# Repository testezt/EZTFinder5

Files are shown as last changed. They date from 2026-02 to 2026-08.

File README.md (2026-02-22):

# PiFinder™
A plate solving telescope finder based around a Raspberry PI, imx296 camera, and custom UI 'hat'

For an overview of what the PiFinder™ is and how it came to be visit the official project website at [PiFinder.io](https://www.pifinder.io/build-yours) 

The PiFinder™ uses the [Ceder Detect](https://github.com/smroid/cedar-detect) and
[Cedar Solve](https://github.com/smroid/cedar-solve) libraries with express permission.
Thank you to [smroid] for all your support of the PiFinder project!

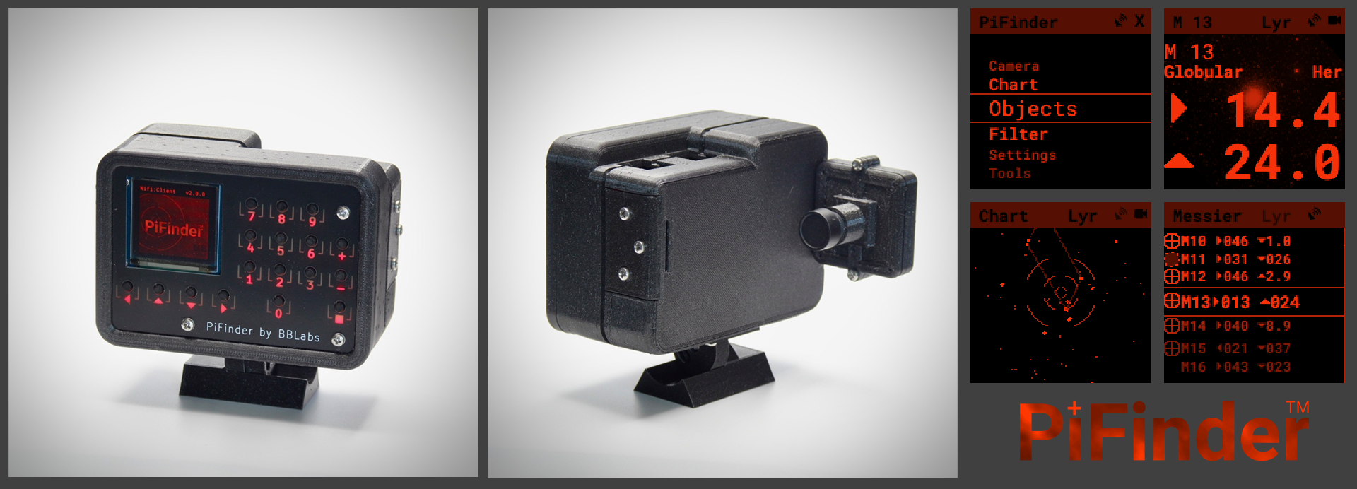
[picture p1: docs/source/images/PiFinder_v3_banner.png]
Banner

The PiFinder™ is my attempt to improve my time at my telescope.  I don't get nearly enough of it and I want to enjoy it as much as possible.  So after years of observing with paper charts and, later, a Nexus DSC here is what I felt I was missing:
* **Reliable telescope positioning:**  The Nexus DSC is great, but my scope just isn't built for solid encoder integration.  The slop in the way I have to couple the encoders means poor pointing accuracy.
* **Easy setup:**  The Nexus DSC needs multi-star alignment to understand how the encoders map to the sky.  The process is not terrible, but I'd like to avoid it.
* **Good push-to functionality**:  This is one place the Nexus DSC shines... if it's well aligned.  The catalog system is okay, and once you select and object the screen is clear and helpful to get the telescope pointed correctly.
* **Observation logging**:  I like to keep track of what I see each night.  I don't often sketch, just record what I saw when, with what eyepiece and some basic info about the experience.  If I could do this right at the eyepiece, that'd save time.

My hope is that other people will find this combination of functionality useful, will build their own PiFinder™ and help the whole project improve by making suggestions and potentially contributing to the software.  It's a pretty easy build with off the shelf parts and beginner friendly soldering.  

## Features
* Zero setup: Just turn it on and point it at the sky!  
* Accurate pointing: Onboard GPS determines location and time while the camera determines where the scope is pointing.  Inertial Measurement Unit tracks scope motion and updates sky position between camera solves
* Self-contained:  Includes catalog search/filtering, sky/object charting, push-to guidance and logging all via the screen and keypad on the unit.
* Dark site friendly:  Red OLED screen and soft backlit keys have wide brightness adjustment, right down to 'off'. No need for bright cell phones or tablets
* Easy access: Can be mounted by the eyepiece just like a finder.
- Wifi Access Point / SkySafari Integration:  The PiFinder™ can act as a WIFI access point to connect your tablet or phone to sync SkySafari or other planetarium software with your scope.

## Build Your Own
The PiFinder™ is fully open-source hardware and software.  You can order PCB's and 3d print the case with the files in this repo and order all the parts from the [parts List](https://pifinder.readthedocs.io/en/release/BOM.html).

If you would like pre-assembled units, kits or other items to jump start your PiFinder™ journey, visit [PiFinder.io](https://www.pifinder.io/build-pifinder) to see what's available and place an order.

## Docs

* [Quick Start](https://pifinder.readthedocs.io/en/release/quick_start.html)
* [User Manual](https://pifinder.readthedocs.io/en/release/user_guide.html)
* [Parts List](https://pifinder.readthedocs.io/en/release/BOM.html)
* [Build Guide](https://pifinder.readthedocs.io/en/release/build_guide.html)
* [Software Setup](https://pifinder.readthedocs.io/en/release/software.html)
* [Developer Guide](https://pifinder.readthedocs.io/en/release/dev_guide.html)

## Releases and Updates

If you are using a PiFinder, I recommend you watch releases in this repo.  Click the 'Watch' button up at the top right of the page, choose 'Custom' and then 'Releases' to make sure you don't miss any new features!

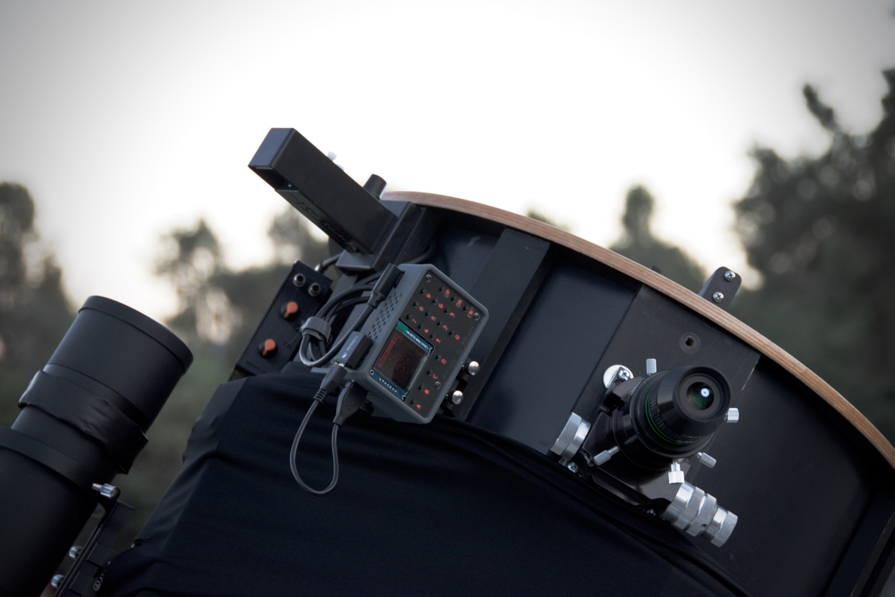
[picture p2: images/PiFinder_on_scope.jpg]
PiFinder™ on my Dob


If you'd like to learn more about how it works, and potentially build your own, everything you need should be here.  I recommend starting with the [User Manual](https://pifinder.readthedocs.io/en/release/user_guide.html) and then checking out the build process using the links below.

## Discord
Join the  [PiFinder™ Discord server](https://discord.gg/Nk5fHcAtWD) for support with your build, usage questions, and suggestions for improvement.

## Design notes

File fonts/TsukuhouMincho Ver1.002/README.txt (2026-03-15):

この度は築豊明朝をダウンロードいただき誠にありがとうございます。

■書体概要
築豊明朝（つくほうみんちょう）は築地五号系の伝統的な本文向け明朝体を意識して作られたかな書体です。
伝統な部分を残しつつ、一部のかなの脈絡を変更することで筆の動きや柔らかさをより強調させました。独特な字形もあり、本文だけではなく、見出しやタイトルでも使っても目を惹きつけられるかもしれません。
漢字や欧文は「ZENオールド明朝 Regular」からお借りしています。

■ご利用にあたり
SILオープンフォントライセンスでの配布なので、商用・個人利用可能です。

文字魚│Typographish

2022/12/18　Ver1.000　公開
2022/12/19　Ver1.001　修正
2022/12/26　Ver1.002　フォント名が日本語になりました

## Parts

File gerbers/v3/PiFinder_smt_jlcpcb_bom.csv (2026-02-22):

Comment | Designator | Footprint | LCSC
1uF | C1 | Capacitor_SMD:C_0805_2012Metric | C28323
100nF | C2 | Capacitor_SMD:C_0805_2012Metric | C49678
22pF | C3,C4 | Capacitor_SMD:C_0805_2012Metric | C24658
LED | D1,D2,D3,D4,D5,D6,D7,D8,D9,D10,D11,D12,D13,D14,D15,D16,D17 | LED_SMD:LED_1210_3225Metric | C125112
BNO055 | IMU1 | Package_LGA:LGA-28_5.2x3.8mm_P0.5mm | C93216
Q_NPN_EBC | Q1 | RSU:PF_SOT-23-NPN | C2150
22 | R1 | Resistor_SMD:R_0805_2012Metric | C17561
330 | R2 | Resistor_SMD:R_0805_2012Metric | C17630
10k | R3,R4,R5,R6 | Resistor_SMD:R_0805_2012Metric | C17414
SW_Push_Dual | SW0,SW1,SW_A1,SW_B1,SW_C1,SW_D1,SW_DN1,SW_GO1,SW_UP1,SW2,SW3,SW4,SW5,SW6,SW7,SW8,SW9 | RSU:SW_Push_6x6mm_SMT_withhole_tight | C4364377
Crystal | Y1 | Crystal:Crystal_SMD_3215-2Pin_3.2x1.5mm | C32346

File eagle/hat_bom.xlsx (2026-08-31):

Comment | Designator | Footprint
22pF | C1 | C0603C100C5GACTU | C1648
1uF | C2 | C0603C100C5GACTU | C15849
22pF | C25 | C0603C100C5GACTU | C1648
0.1uF | C3 | C0603C100C5GACTU | C14663
APBD3224LSYKCGKC | D1 | APBD3224LSYKCGKC | C125112
APBD3224LSYKCGKC | D2 | APBD3224LSYKCGKC | C125112
APBD3224LSYKCGKC | D3 | APBD3224LSYKCGKC | C125112
APBD3224LSYKCGKC | D4 | APBD3224LSYKCGKC | C125112
APBD3224LSYKCGKC | D5 | APBD3224LSYKCGKC | C125112
APBD3224LSYKCGKC | D6 | APBD3224LSYKCGKC | C125112
APBD3224LSYKCGKC | D7 | APBD3224LSYKCGKC | C125112
APBD3224LSYKCGKC | D8 | APBD3224LSYKCGKC | C125112
APBD3224LSYKCGKC | D9 | APBD3224LSYKCGKC | C125112
APBD3224LSYKCGKC | D10 | APBD3224LSYKCGKC | C125112
APBD3224LSYKCGKC | D11 | APBD3224LSYKCGKC | C125112
APBD3224LSYKCGKC | D12 | APBD3224LSYKCGKC | C125112
APBD3224LSYKCGKC | D13 | APBD3224LSYKCGKC | C125112
APBD3224LSYKCGKC | D14 | APBD3224LSYKCGKC | C125112
APBD3224LSYKCGKC | D15 | APBD3224LSYKCGKC | C125112
APBD3224LSYKCGKC | D16 | APBD3224LSYKCGKC | C125112
APBD3224LSYKCGKC | D17 | APBD3224LSYKCGKC | C125112
SS8050-G | Q1 | SS8050-G | C2150
10K | R1 | RC0603JR-070RL | C25804
10K | R2 | RC0603JR-070RL | C25804
10K | R3 | RC0603JR-070RL | C25804
330 | R4 | RC0603JR-070RL | C23138
22 | R5 | RC0603JR-070RL | C103419
10K | R19 | RC0603JR-070RL | C25804
C2888519 | S1 | TS04-44-75-BK-100-SMT44 | C2888519
TS04-44-75-BK-100-SMT44 | S2 | TS04-44-75-BK-100-SMT44 | C2888519
TS04-44-75-BK-100-SMT44 | S3 | TS04-44-75-BK-100-SMT44 | C2888519
TS04-44-75-BK-100-SMT44 | S4 | TS04-44-75-BK-100-SMT44 | C2888519
TS04-44-75-BK-100-SMT44 | S5 | TS04-44-75-BK-100-SMT44 | C2888519
TS04-44-75-BK-100-SMT44 | S6 | TS04-44-75-BK-100-SMT44 | C2888519
TS04-44-75-BK-100-SMT44 | S7 | TS04-44-75-BK-100-SMT44 | C2888519
TS04-44-75-BK-100-SMT44 | S8 | TS04-44-75-BK-100-SMT44 | C2888519
TS04-44-75-BK-100-SMT44 | S9 | TS04-44-75-BK-100-SMT44 | C2888519
TS04-44-75-BK-100-SMT44 | S10 | TS04-44-75-BK-100-SMT44 | C2888519
TS04-44-75-BK-100-SMT44 | S11 | TS04-44-75-BK-100-SMT44 | C2888519
TS04-44-75-BK-100-SMT44 | S12 | TS04-44-75-BK-100-SMT44 | C2888519
TS04-44-75-BK-100-SMT44 | S13 | TS04-44-75-BK-100-SMT44 | C2888519
TS04-44-75-BK-100-SMT44 | S14 | TS04-44-75-BK-100-SMT44 | C2888519
TS04-44-75-BK-100-SMT44 | S15 | TS04-44-75-BK-100-SMT44 | C2888519
TS04-44-75-BK-100-SMT44 | S16 | TS04-44-75-BK-100-SMT44 | C2888519
TS04-44-75-BK-100-SMT44 | S17 | TS04-44-75-BK-100-SMT44 | C2888519
SS12D07VG5/C22435634 | S18 | SS12D07VG4 | C22435634
BNO055 | U1 | BNO055 | C93216
32.768kHz 70kΩ | XTAL1 | Q13FC1350000400 | C32346

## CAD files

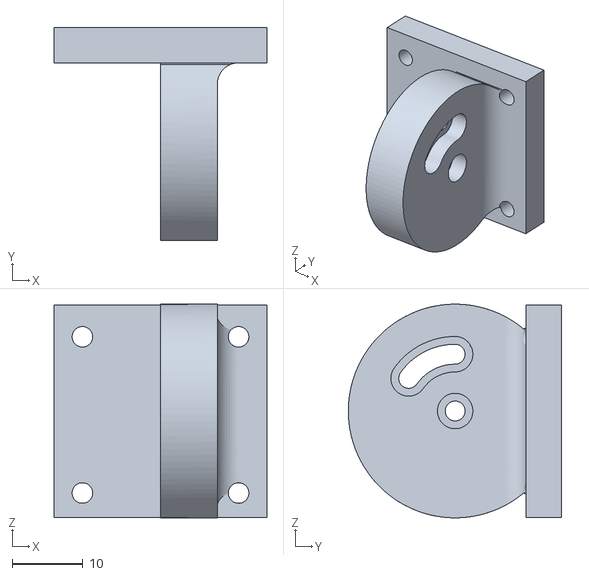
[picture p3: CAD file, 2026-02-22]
case/accessories/tall_dovetail_top.stl
30.0 x 30.0 x 30.1

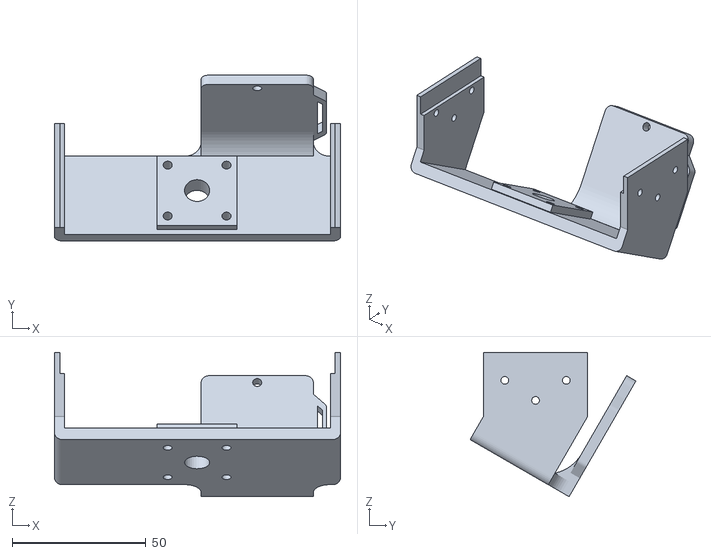
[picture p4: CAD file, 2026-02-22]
case/adapters/flat30_adapter_tripod.stl
107.0 x 62.1 x 54.0

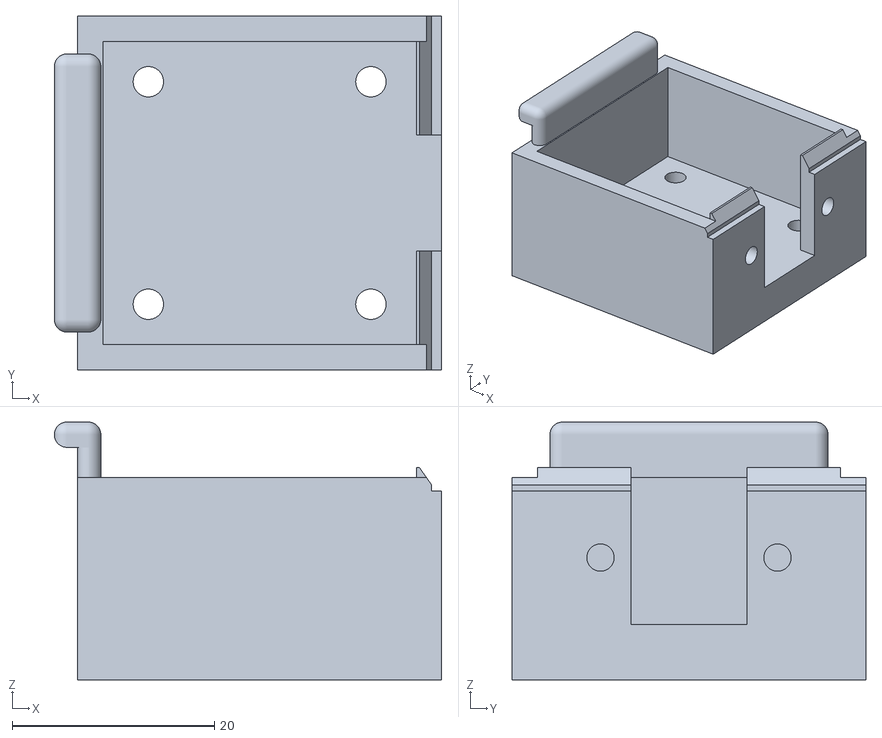
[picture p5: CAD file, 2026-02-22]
case/adapters/quikfinder/PiToQuikfinder v2 - Part 1.stl
38.3 x 35.0 x 25.5

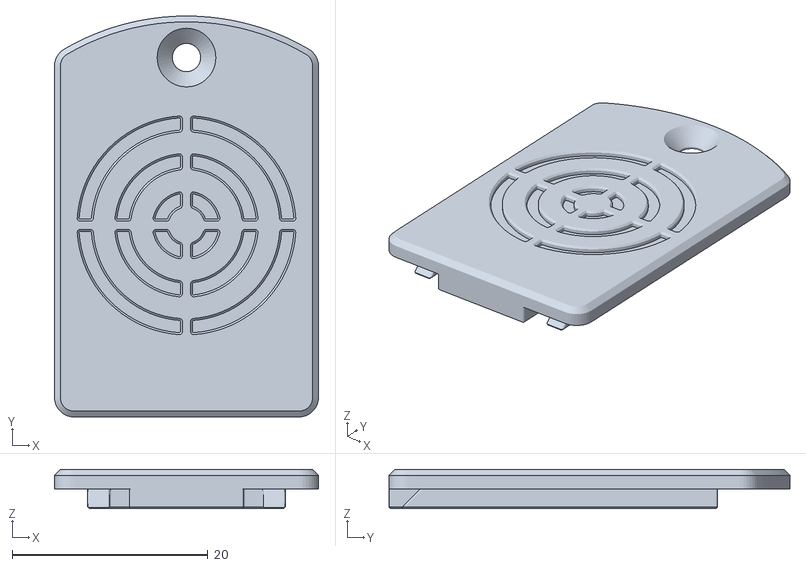
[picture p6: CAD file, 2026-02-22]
case/GPS_enclosure_bottom.stl
27.0 x 41.0 x 4.00

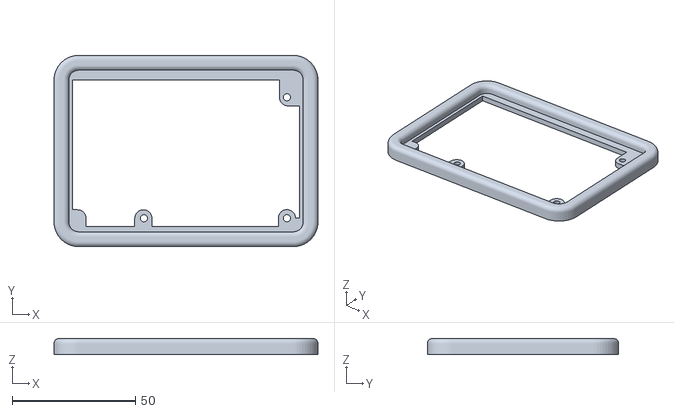
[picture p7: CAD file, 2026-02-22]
case/v3/common/bezel.stl
107.0 x 77.5 x 6.50

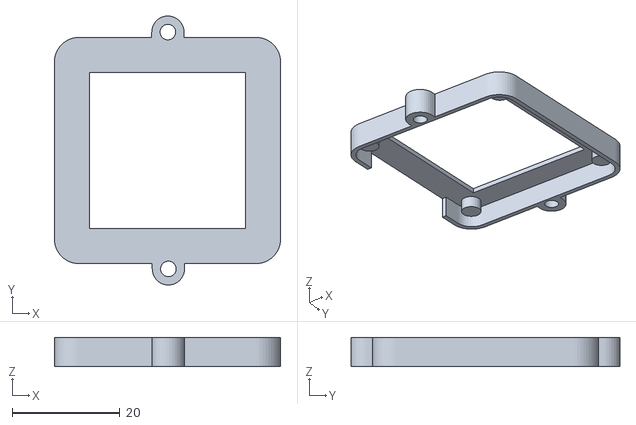
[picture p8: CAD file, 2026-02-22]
case/v3/flat/flat30_camtray.stl
42.0 x 50.0 x 5.40

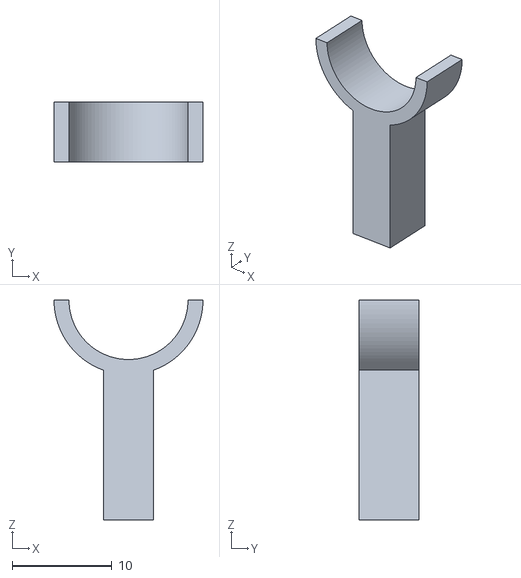
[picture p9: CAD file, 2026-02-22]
case/v3/focus_spacer.stl
14.9 x 6.00 x 22.0

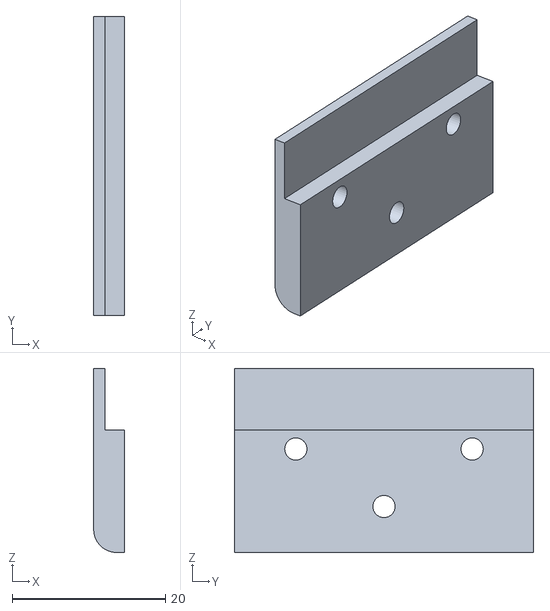
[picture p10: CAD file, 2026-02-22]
case/v3/left_right/hardpoint_cover.stl
4.00 x 39.0 x 24.0

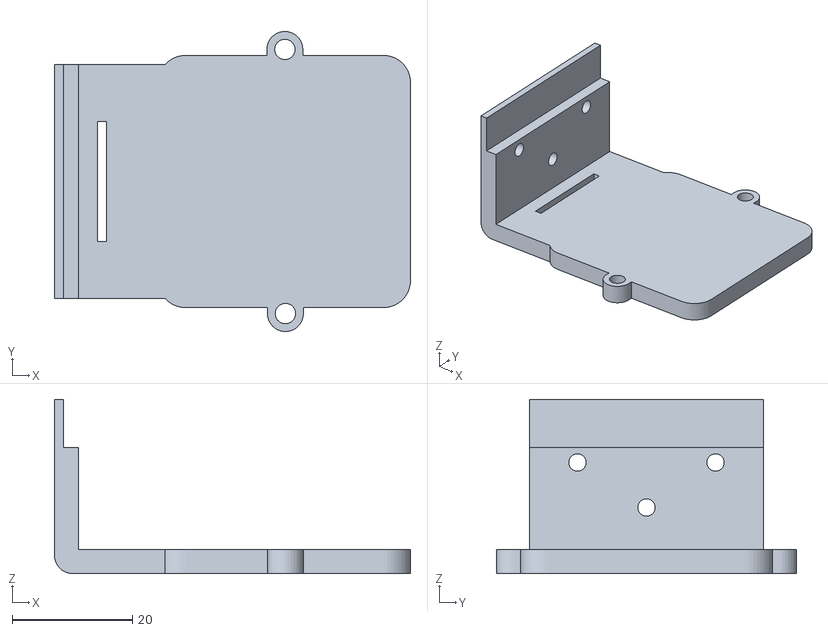
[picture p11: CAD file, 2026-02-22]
case/v3/straight/st_mount.stl
59.3 x 50.0 x 29.0

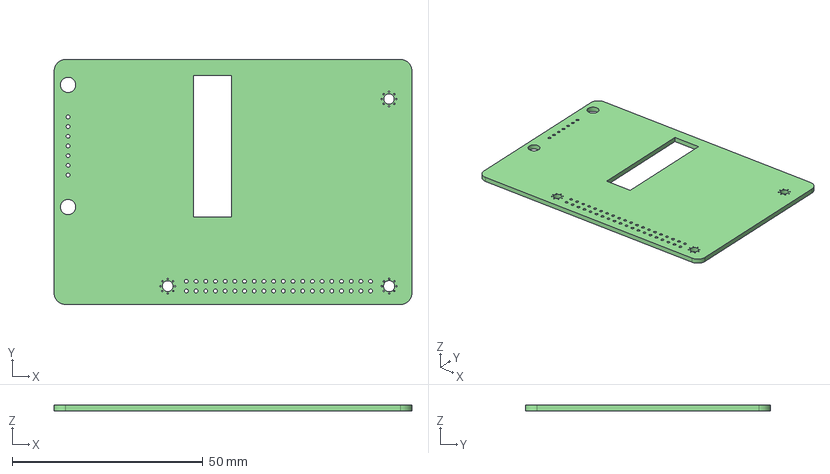
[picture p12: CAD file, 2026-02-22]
kicad/PiFinder_v3/PiFinder_smt.step
93.8 x 64.2 x 1.60 mm

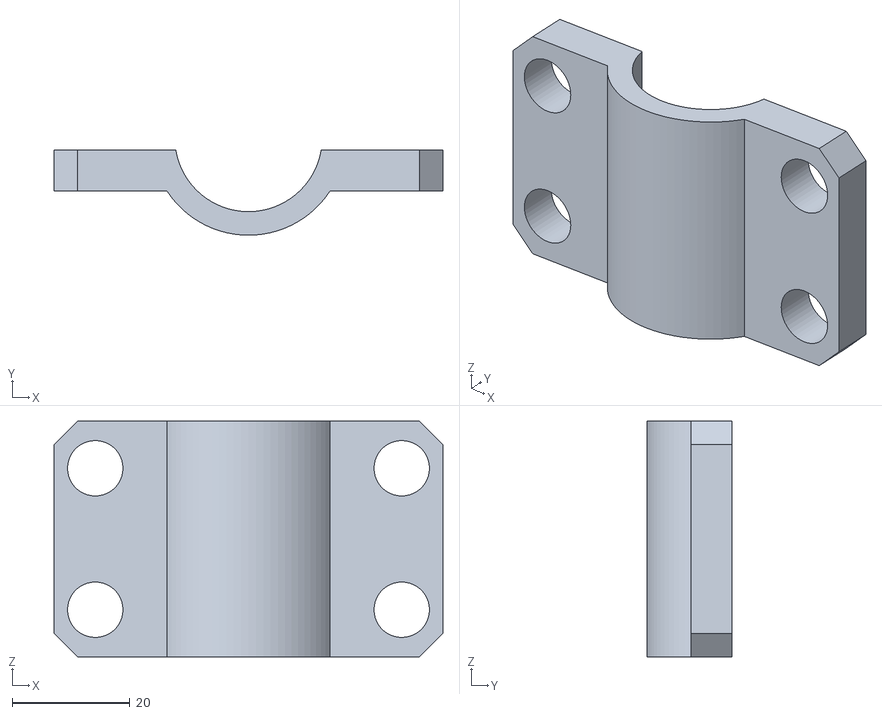
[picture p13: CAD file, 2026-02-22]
case/accessories/tube_shoe_mount_25mm_bottom.stl
66.0 x 14.5 x 40.0

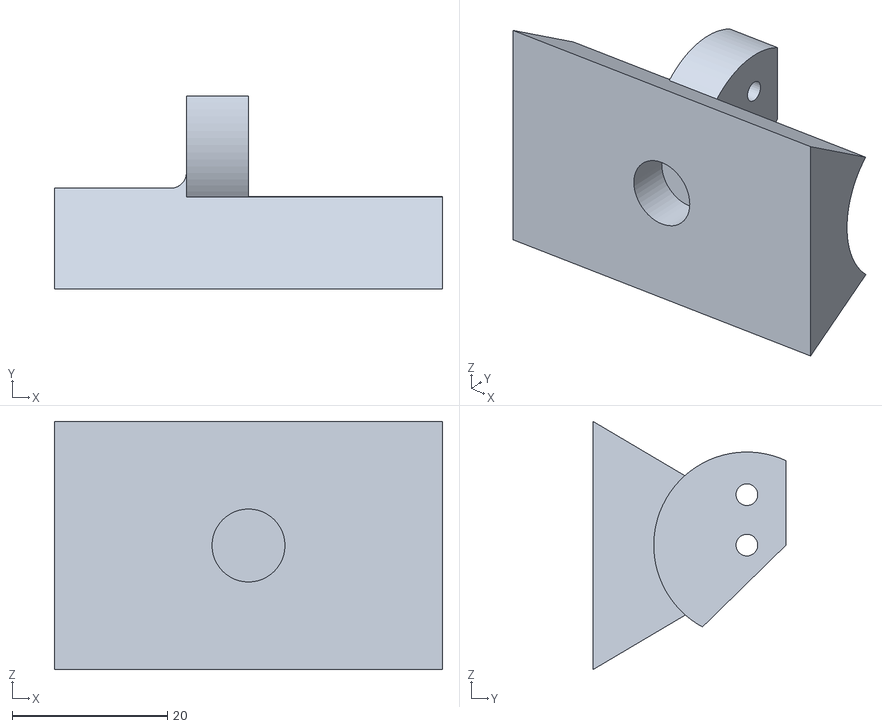
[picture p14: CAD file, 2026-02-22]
case/adapters/dovetail_bottom_tripod.stl
50.0 x 24.9 x 32.0

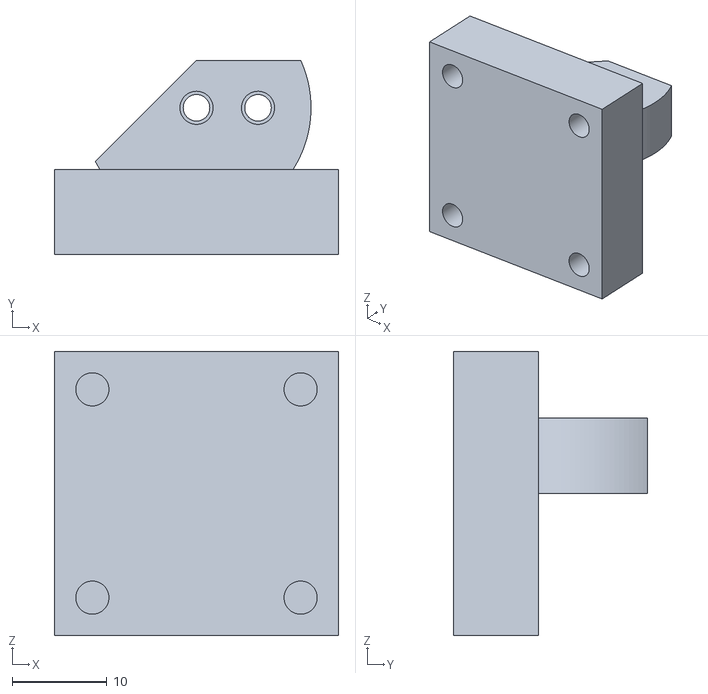
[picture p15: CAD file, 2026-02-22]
case/adapters/quikfinder/Pi2Q2Dovetail.stl
30.0 x 20.5 x 30.0

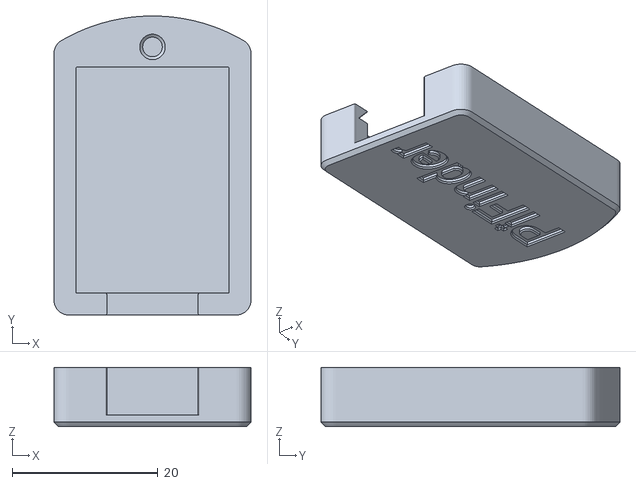
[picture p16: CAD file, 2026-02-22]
case/GPS_enclosure_top.stl
27.0 x 41.0 x 8.10

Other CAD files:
case/v3/common/shroud_front_usb_cutout.stl
case/v3/flat/flat_plug.stl
case/v3/left_right/camera_mount.stl
case/v3/straight/st_tray.stl
case/accessories/90_degree_dovetail.stl
case/accessories/tall_dovetal_bottom.stl
case/accessories/tube_shoe_mount_22mm_bottom.stl
case/accessories/tube_shoe_mount_22mm_top.stl
case/accessories/tube_shoe_mount_25mm_top.stl
case/accessories/tube_shoe_mount_30mm_bottom.stl
case/accessories/tube_shoe_mount_30mm_top.stl
case/accessories/tube_shoe_mount_32mm_bottom.stl
case/accessories/tube_shoe_mount_32mm_top.stl
case/accessories/tube_shoe_mount_38mm_bottom.stl
case/accessories/tube_shoe_mount_38mm_top.stl
case/accessories/vixen_right_angle.stl
case/adapters/dovetail_losmandy.stl
case/adapters/flat30_adapter_sidemount.stl
case/adapters/quikfinder/PiToQuikfinder v2 - Part 2.stl
case/v1/bezel.stl
case/v1/bottom.stl
case/v1/camera_cover.stl
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

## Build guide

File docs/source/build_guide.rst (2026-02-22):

===========
Build Guide
===========

Introduction and Overview
=================================

Welcome to the PiFinder build guide!  This guide is split into three main parts, one for building the :ref:`UI Board<build_guide:pifinder ui hat>` with Screen and Buttons, a section related to :ref:`3d printing<build_guide:printed parts>` and preparing the case parts, and one for :ref:`final assembly<build_guide:assembly>`.   Along with these sections, please consult the :doc:`Bill of Materials<BOM>` for a full list of parts required and reach out with any questions via `email <mailto:info@pifinder.io>`_ or `discord <https://discord.gg/Nk5fHcAtWD>`_

If you've received a kit with an assembled UI Board + 3d Parts, you can jump right to the :ref:`final assembly<build_guide:assembly>`.  Otherwise, fire up that 3d printer and get the :ref:`parts printing<build_guide:printing>` while you work to assemble the UI Hat.

PiFinder UI Hat
========================

A key part of the PiFinder is a custom 'Hat' which matches the general form factor of the Raspberry Pi and connects to it's GPIO header.  It contains the switches, screen and Inertial Measurement Unit along with keypad backlight components

It's all through-hole components, so should be approachable to even beginners... but the component build order is important as some items block access to others.

There are still some older photos here from the v1 non-backlit board, but the assembly is the same once the backlight components are in place.

You'll need the TWO pcb's to start with.  One contains the electronic components and the other has the shine-through legends and goes on top of the assembled board at the end.  You can find the gerber files for both in the main `PiFinder git repo <https://github.com/brickbots/PiFinder/tree/release/gerbers>`_

Backlight Components
------------------------

I like to start with the LEDs.  They sit close to the board and doing them first makes it 
easier to make sure they are all aligned.  

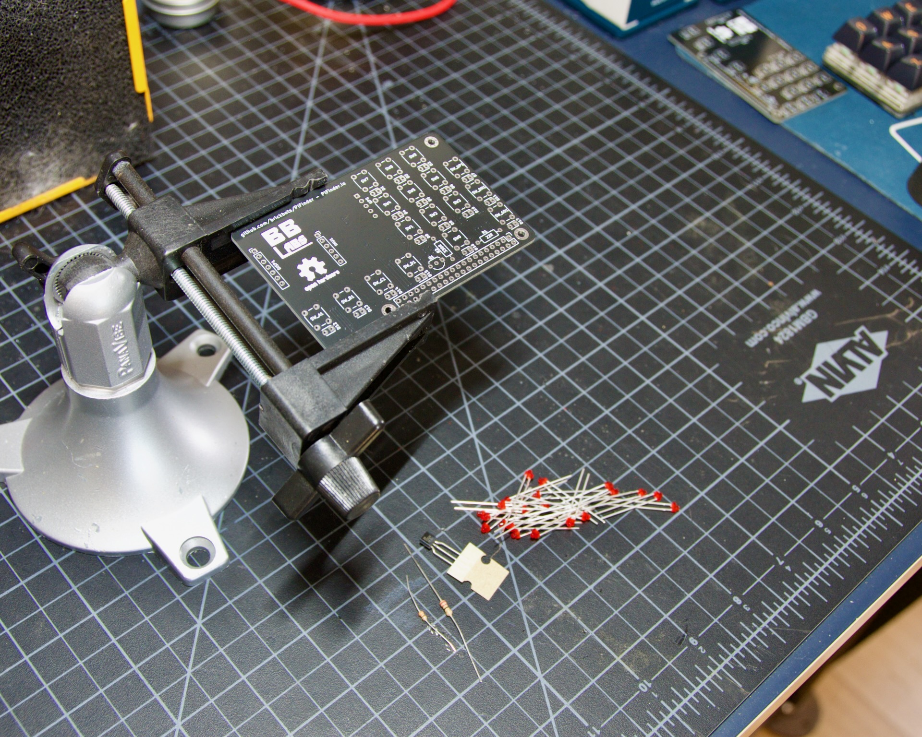
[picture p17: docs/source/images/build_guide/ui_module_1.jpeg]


Polarity matters here, so mind the direction.  The longer lead of the LED should go through the round hole in the footprint.  The photo below shows the orientation

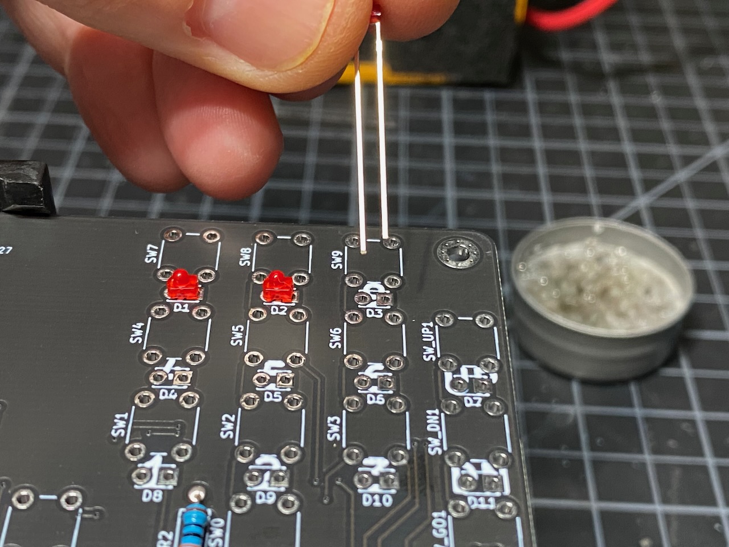
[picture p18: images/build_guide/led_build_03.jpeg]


Take you time and make sure each is positioned well.  They should be pretty uniform, but little inconsistencies don't matter too much.  I like to place them all in the board, and then tape them in place.

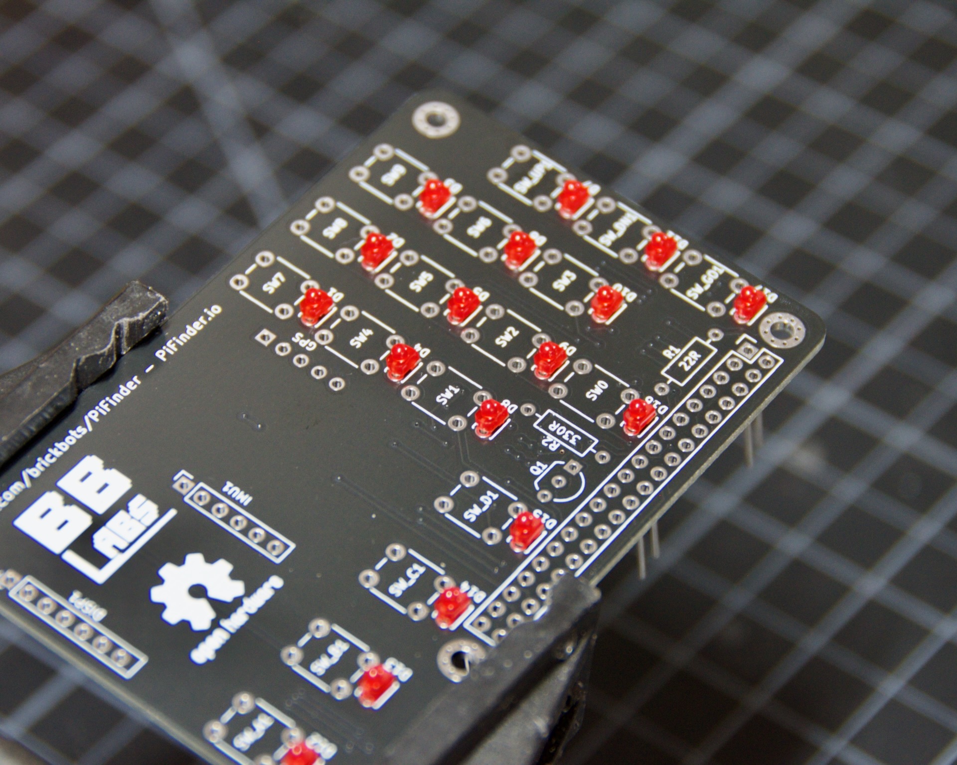
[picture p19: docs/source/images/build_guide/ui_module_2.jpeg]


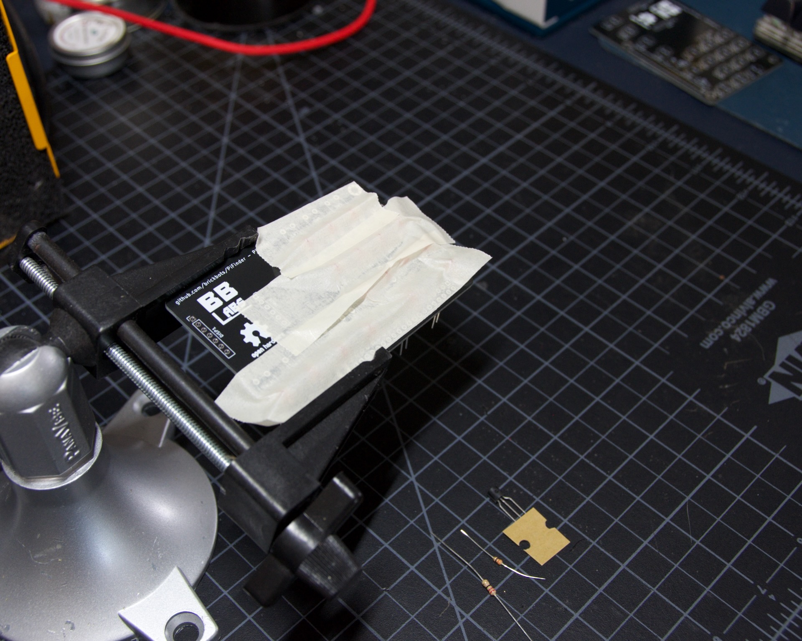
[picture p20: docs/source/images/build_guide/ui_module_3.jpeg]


Pull the legs straight and solder one of each LED.  Then remove the tape and check them again.  If any
are wildly out of place, you can heat up the solder on the one leg and adjust.  

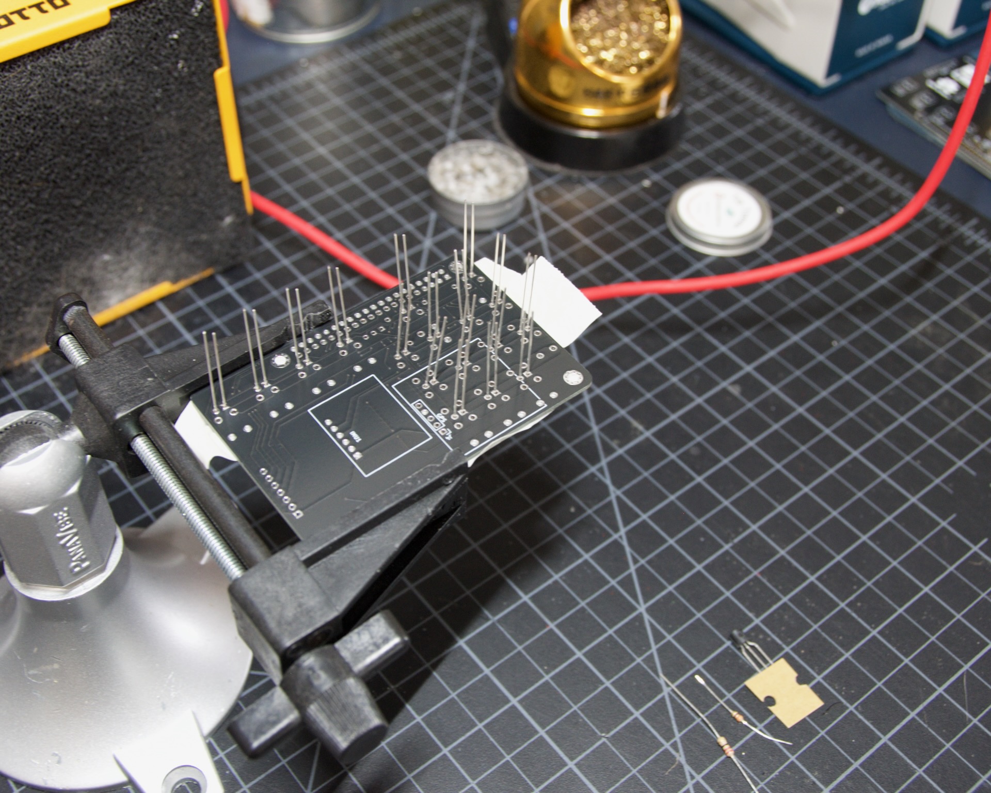
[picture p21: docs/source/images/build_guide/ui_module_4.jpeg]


When satisfied, solder the remaining legs and clip the leads

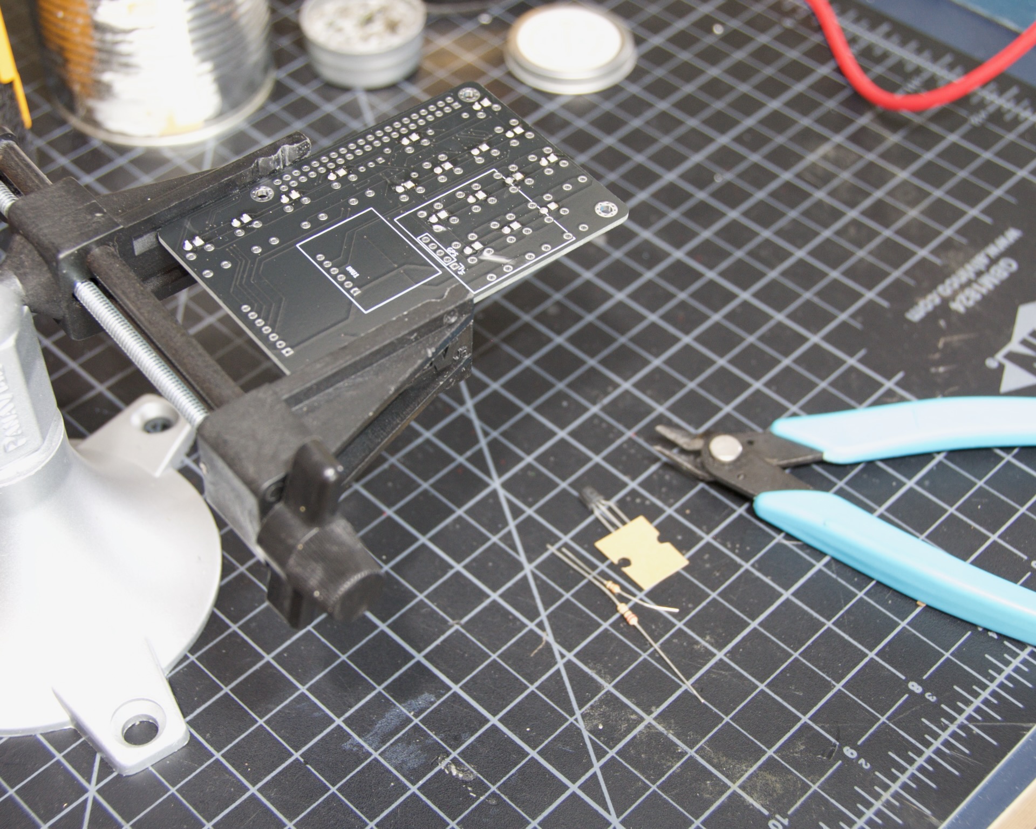
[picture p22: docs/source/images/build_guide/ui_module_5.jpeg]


The two resistors and transitor are next.  R2 is the vertical oriented 330ohm part and R1 is the 22ohm oriented horizontally.  Direction does not matter with these, but it's important for the transistor. Check the photo below for orientation and make sure this is bent flat against the PCB and the resistors are low.  Solder them from the back and clip the leads once you've verified they look good.

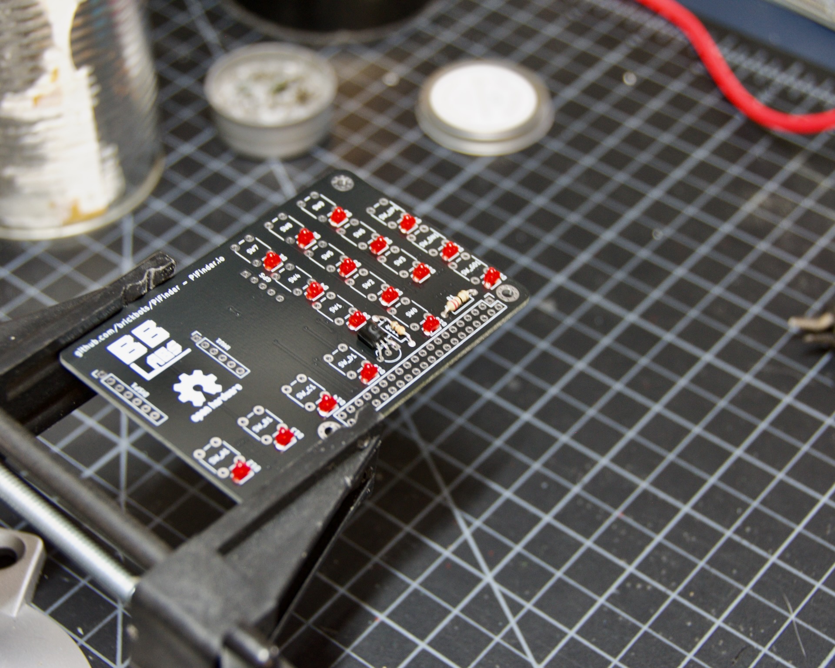
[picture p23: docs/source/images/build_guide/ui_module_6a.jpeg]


Switches
------------------------

Switches are easy and can go next.  Place each one on a footprint and press it down fully.  Once they are all inserted, before you start soldering visually inspect them for any that are tilted.  

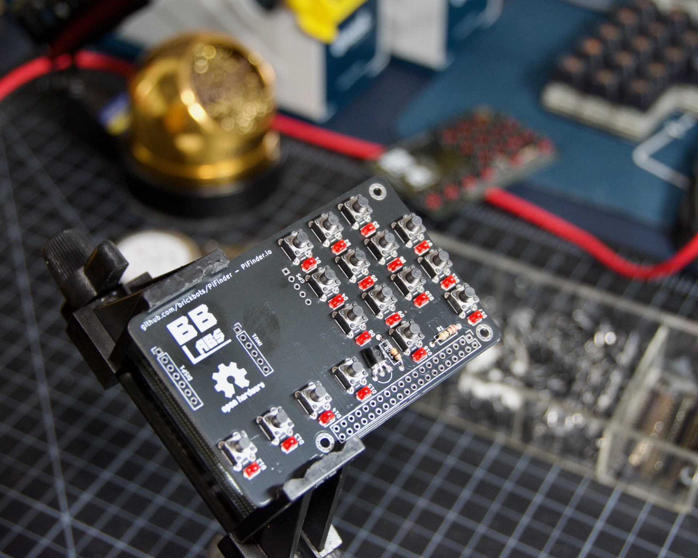
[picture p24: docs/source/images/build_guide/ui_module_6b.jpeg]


It's also a good idea to place the top legend plate over them to make sure they all clear the holes properly.  Then solder them up!  You don't need to clip the leads on all the switches, they have plenty of room.

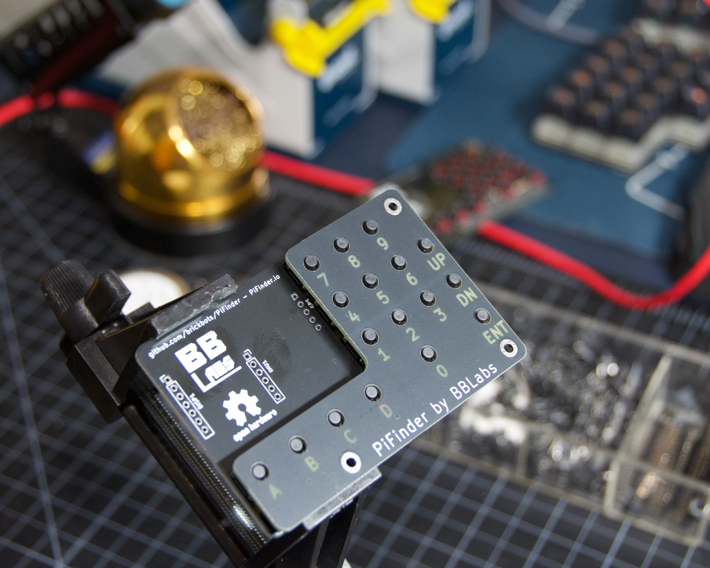
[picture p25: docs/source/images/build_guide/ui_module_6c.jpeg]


Headers
---------

I like to do all the headers next.  These will eventually receive the IMU, GPS and Screen.  The procedure is roughly the same for 
all three: Insert them, solder one pin, check that they are flat and straight and then solder the rest of the pins.  Clip them flush and apply some insulating tape.  

Start with the IMU header.  It goes on the underside of the board and is soldered from the top

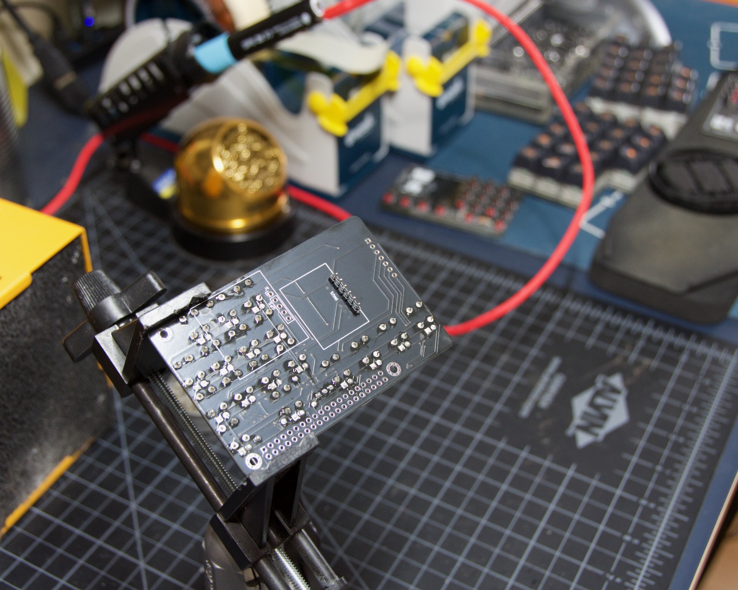
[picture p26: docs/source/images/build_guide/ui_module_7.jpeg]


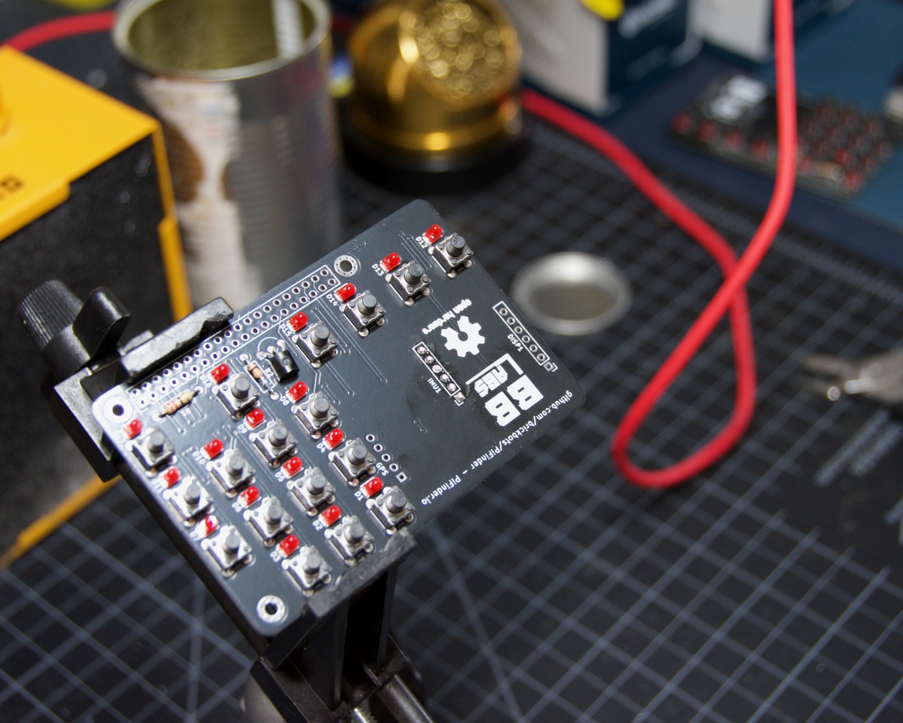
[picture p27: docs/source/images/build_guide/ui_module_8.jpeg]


Apply the insulating tape and move on to the screen header.  It goes in from the top side:

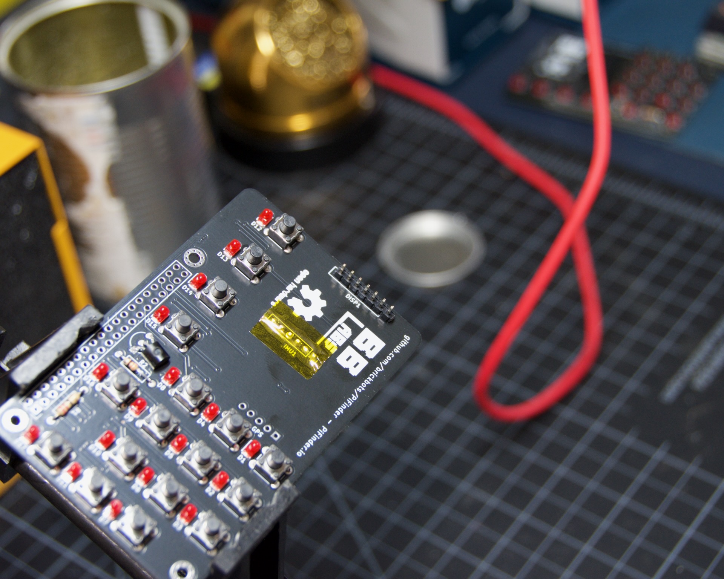
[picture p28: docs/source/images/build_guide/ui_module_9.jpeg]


Trim the pins and tape it up

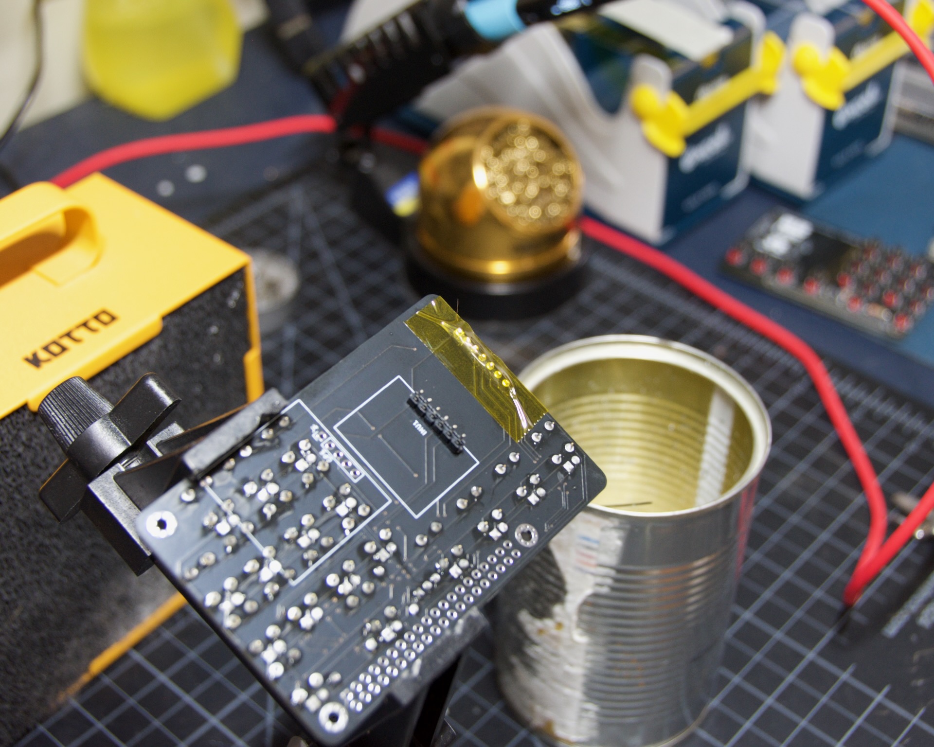
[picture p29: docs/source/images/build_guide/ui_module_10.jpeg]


The GPS header is next. The modules come with a yellow header, but any will do.  It gets inserted from the bottom, soldered and taped liked the rest.

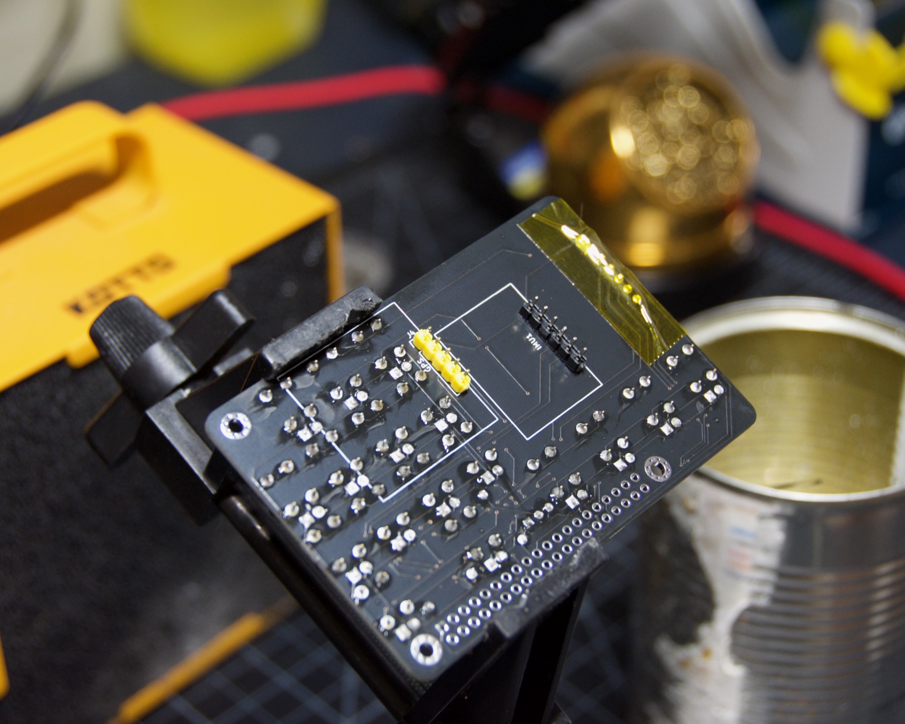
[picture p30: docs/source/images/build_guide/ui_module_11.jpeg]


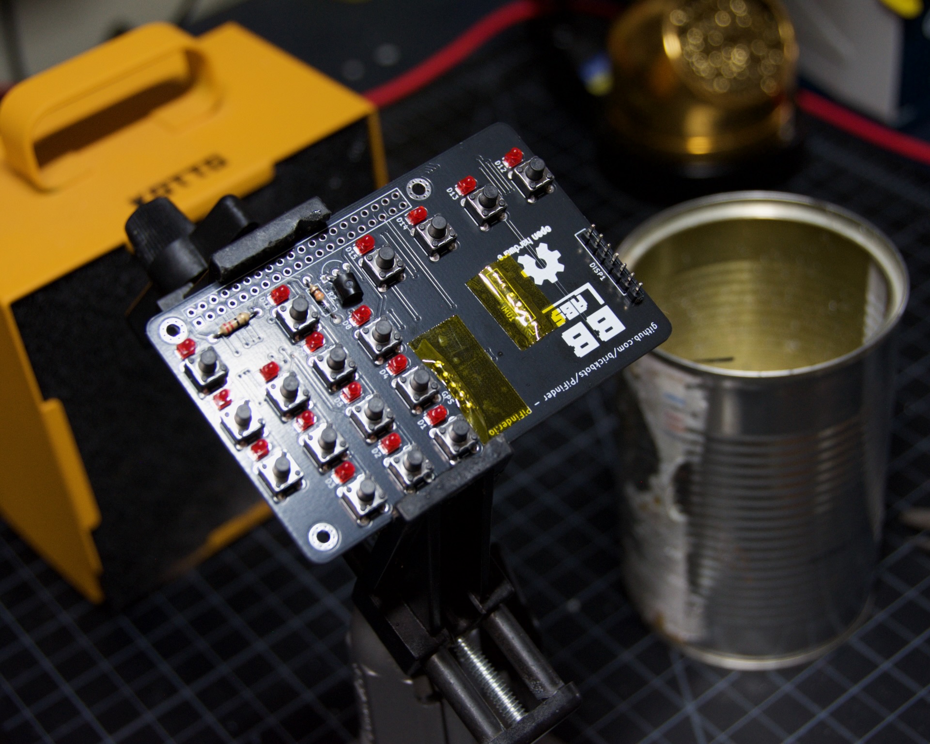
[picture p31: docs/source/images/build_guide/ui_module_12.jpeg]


IMU
------------------------

The Inertial Measurement unit is next.  The IMU has an annoyingly bright green LED on it, which you will either want to paint over with a few laywers of black nail polish, or you can use your soldering iron to destroy it.  It can be handled  after it's soldered if you forget, but it's much easier before hand.  See the image below to ID the offending component.

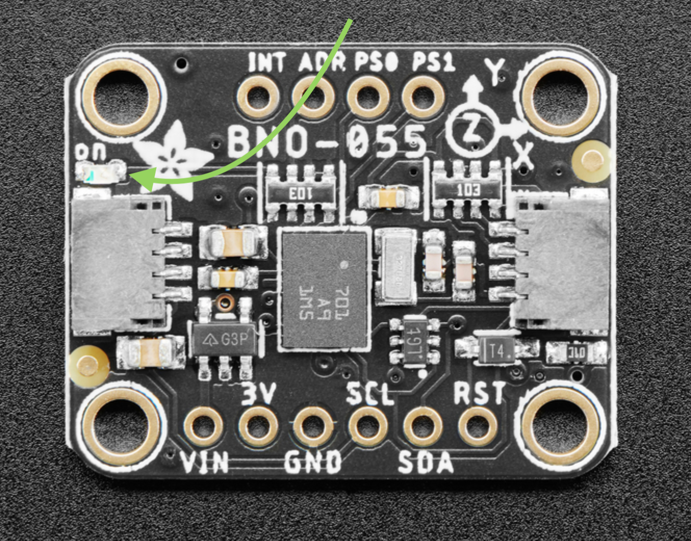
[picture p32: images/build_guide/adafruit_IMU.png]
Green led on IMU


The photo below shows the orientation on the back of the PCB. Make sure it sits flat and square with the board.  It does not need to be perfect, but should be secure and low-profile. Solder it into position and you're good to go!

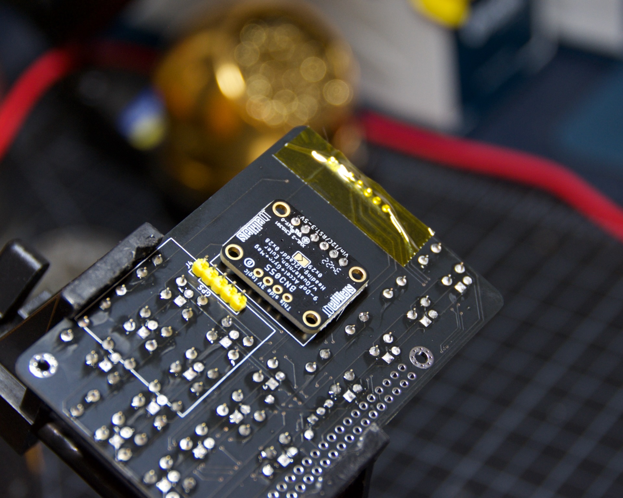
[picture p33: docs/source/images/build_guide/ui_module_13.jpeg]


Display
------------------

The display comes next and will cover the solder points for the IMU header, so double check your solder joints there before proceeding!

You'll need to remove the stand-offs by unscrewing them from the front.  

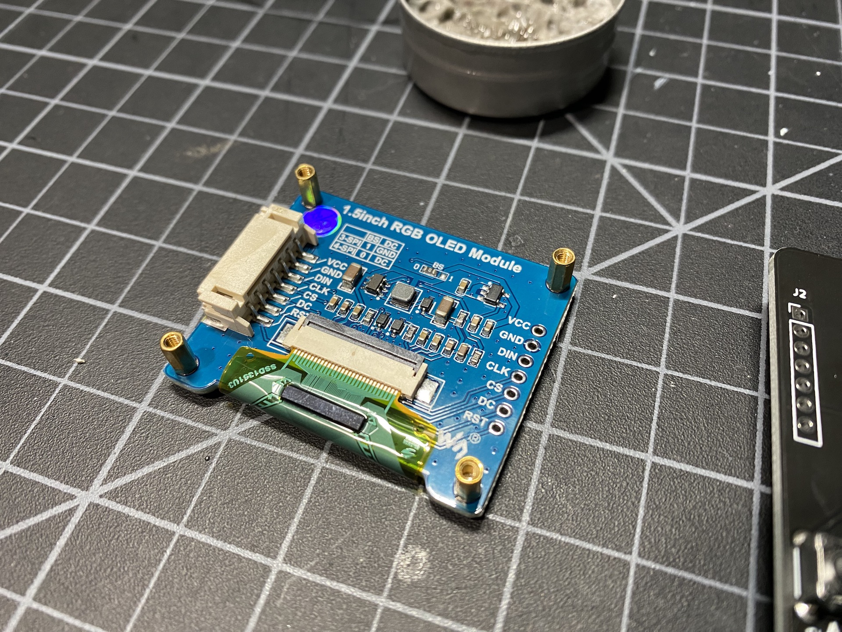
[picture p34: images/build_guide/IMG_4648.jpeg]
Display as shipped


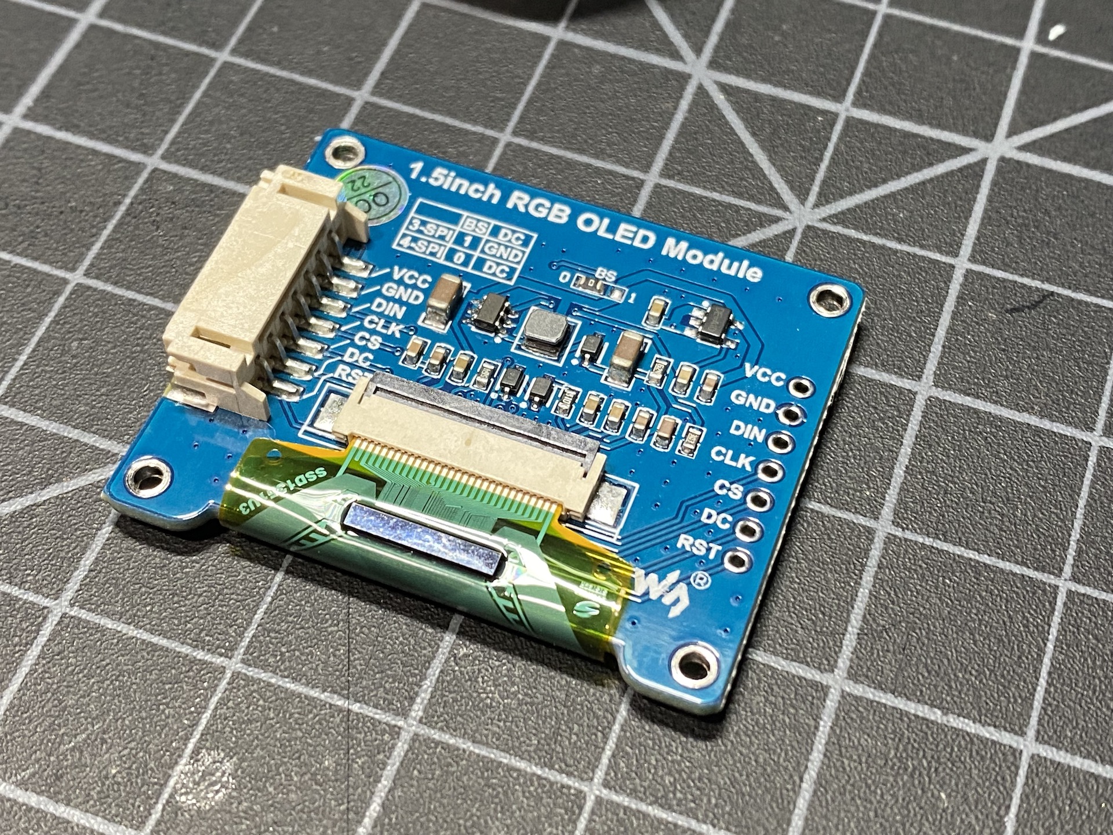
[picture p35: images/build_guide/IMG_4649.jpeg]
Display with standoffs removed


Next you'll need to remove the plug from the underside of the board.  This is not absolutely necessary, but will help the display sit lower and flatter.  Use a sharp pair of cutters to cut each of the leads to the connector first.  Cut down low, but the exact location is not critical.  Once this is done, you can use clippers to cut away the plastic at the attachment points on both of the short sides.

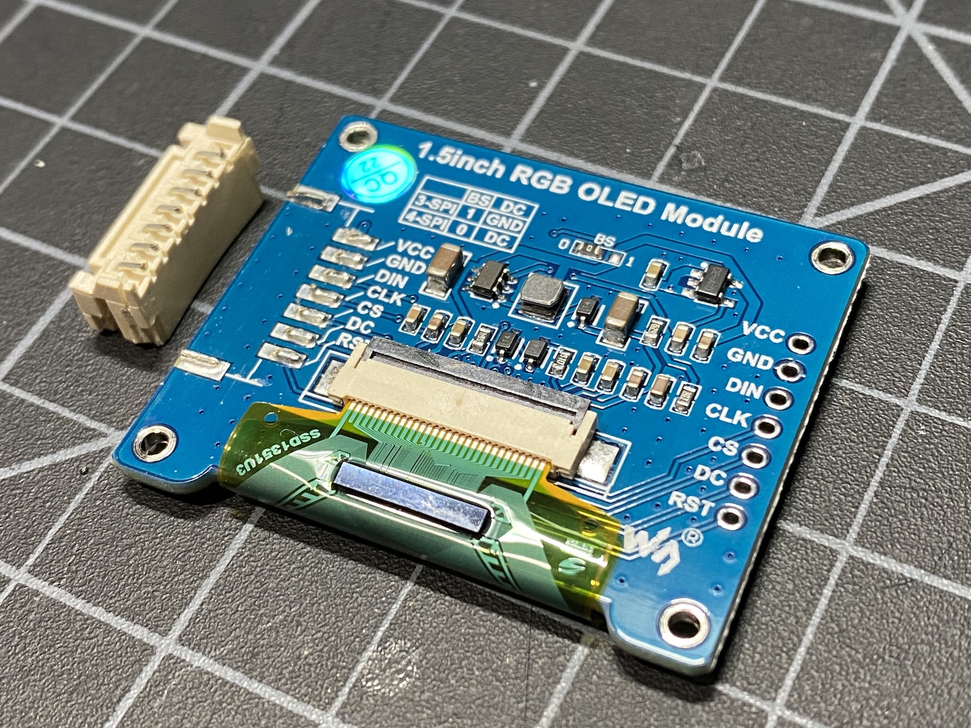
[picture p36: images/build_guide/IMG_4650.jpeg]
Connector cut free


To make the top plate fit a bit better and look tidier, I suggest sanding back or simply cutting the bottom tabs on the display PCB.  There is no circuitry there, they are just providing screw points which are not needed.

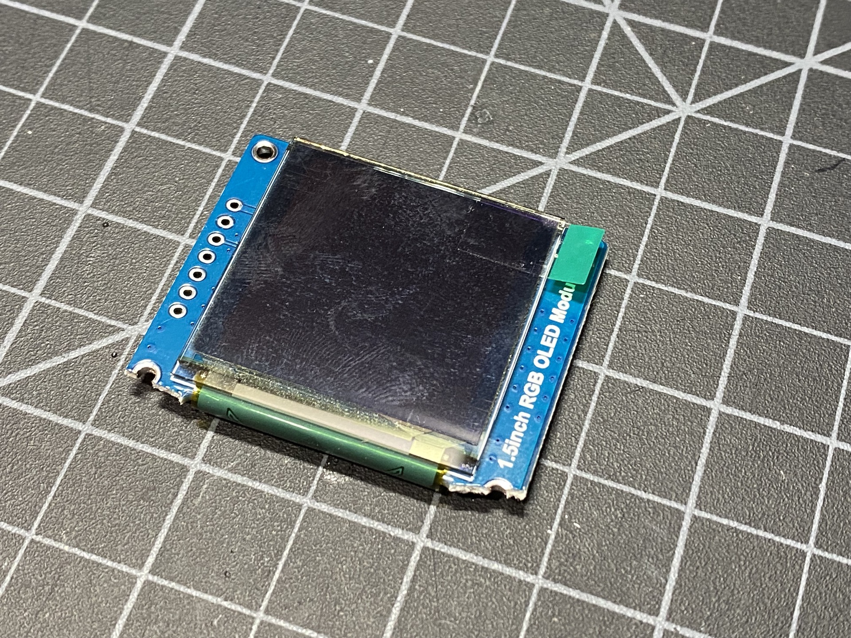
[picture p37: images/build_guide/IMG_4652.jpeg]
Cut/Sand tabs on displya


It's not a bad idea to test fit the screen with the header installed and the top-plate in place.  Everything should fit nicely and be square. 

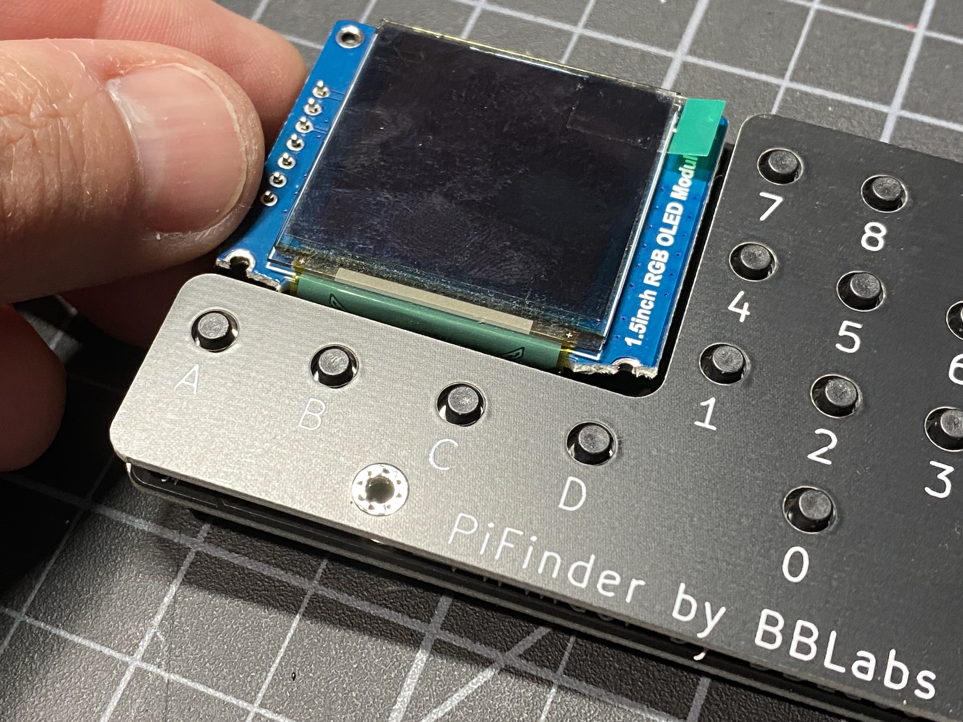
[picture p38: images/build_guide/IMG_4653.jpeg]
Screen test fit


When you are ready, solder the screen in place.  Do one pin first and check it all around to make sure it's sitting flat.  If not, heat that one joint and adjust.

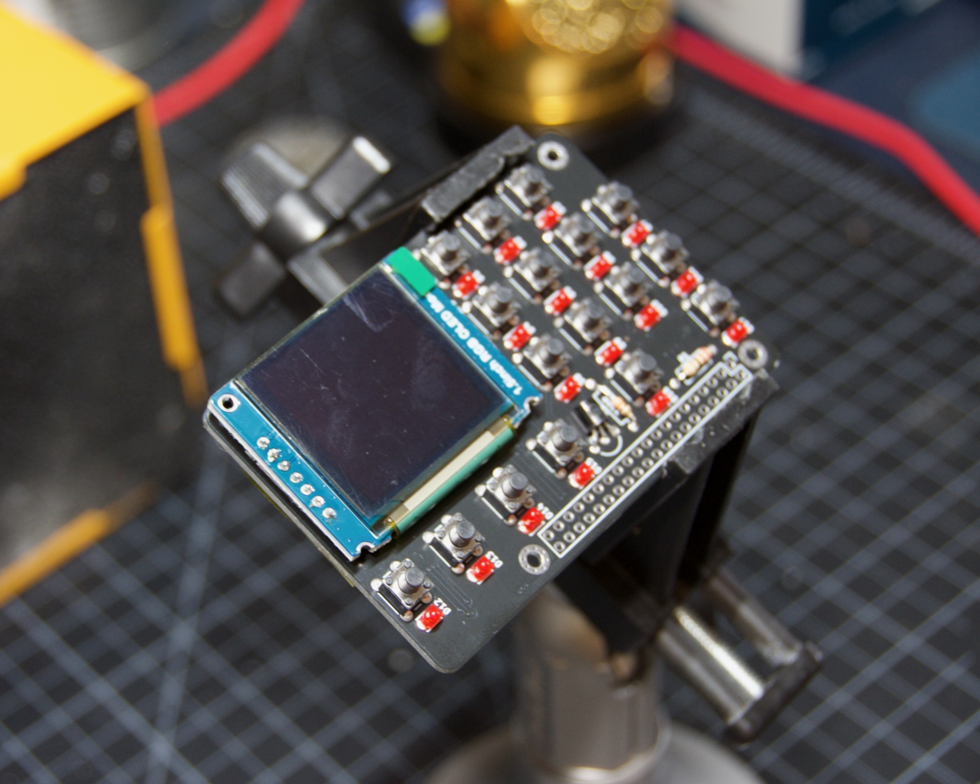
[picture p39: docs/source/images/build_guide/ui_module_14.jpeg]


GPS
------------------

The last active component is the GPS module.  It goes component side up so you can access the antenna plug.  Check the photo below and solder it securely.

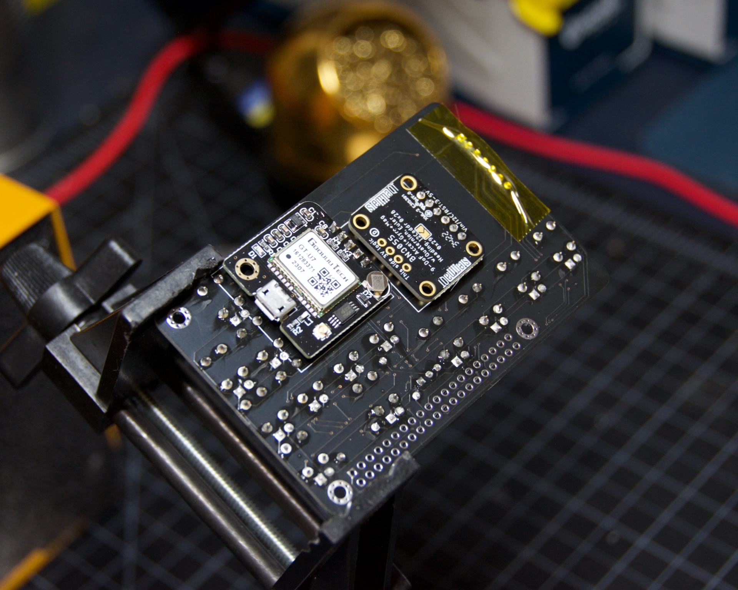
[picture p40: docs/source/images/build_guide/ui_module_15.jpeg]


Connect the antenna to the GPS module. It's a bit fiddly, so check the alignment carefully before
applying too much force.  It will snap in and then rotate pretty easily. 

.. list-table::

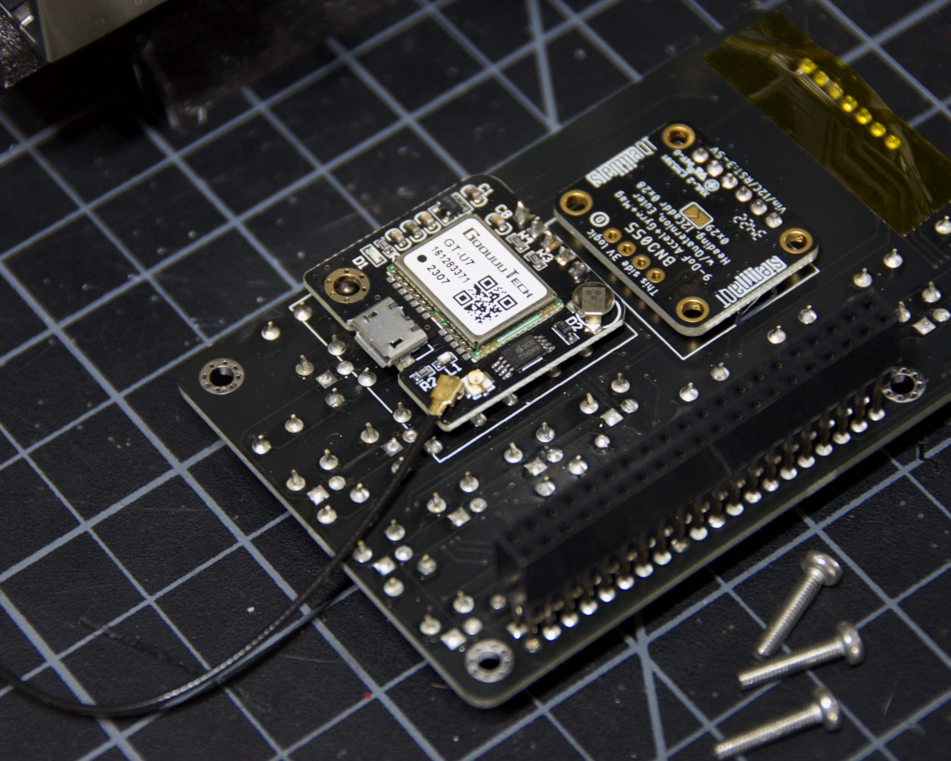
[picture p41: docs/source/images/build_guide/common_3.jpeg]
   * - 

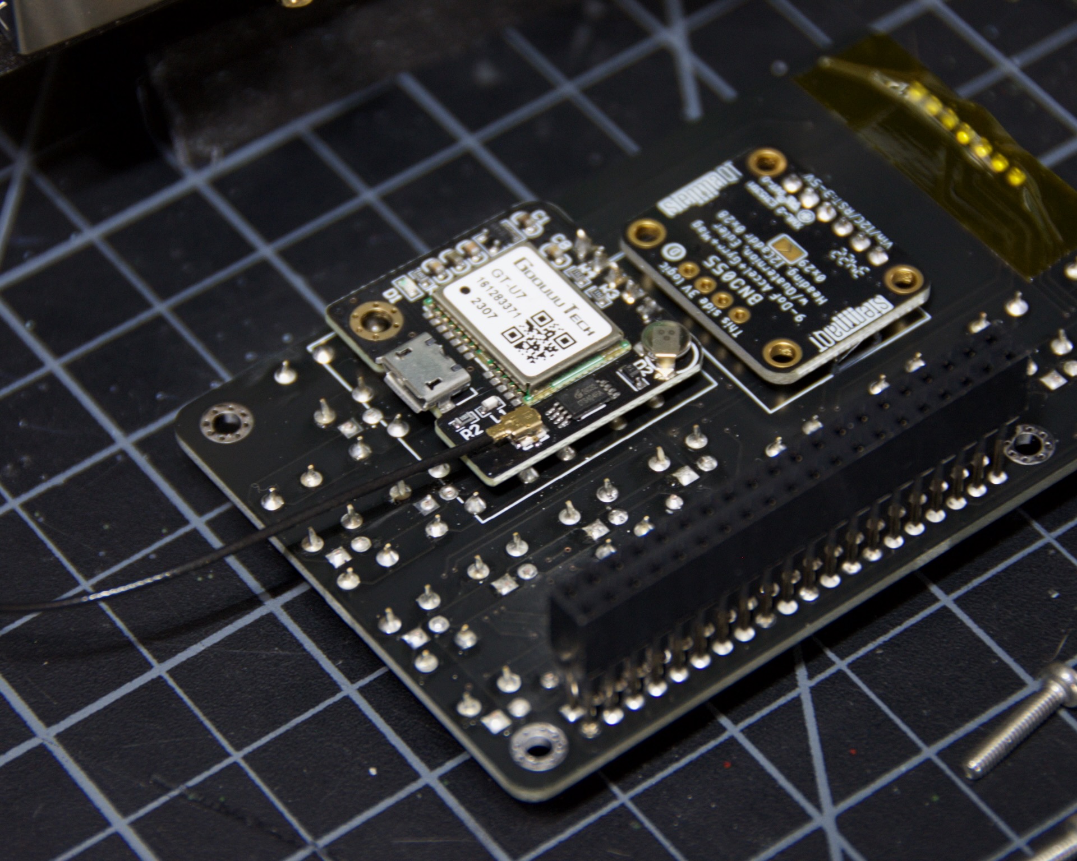
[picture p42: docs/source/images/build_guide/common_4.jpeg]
     - 

The routing of the antenna cable is important for the best possible reception.  Reference the photo below and tape it to the back of
the board to keep it secure and out of the way during the build.

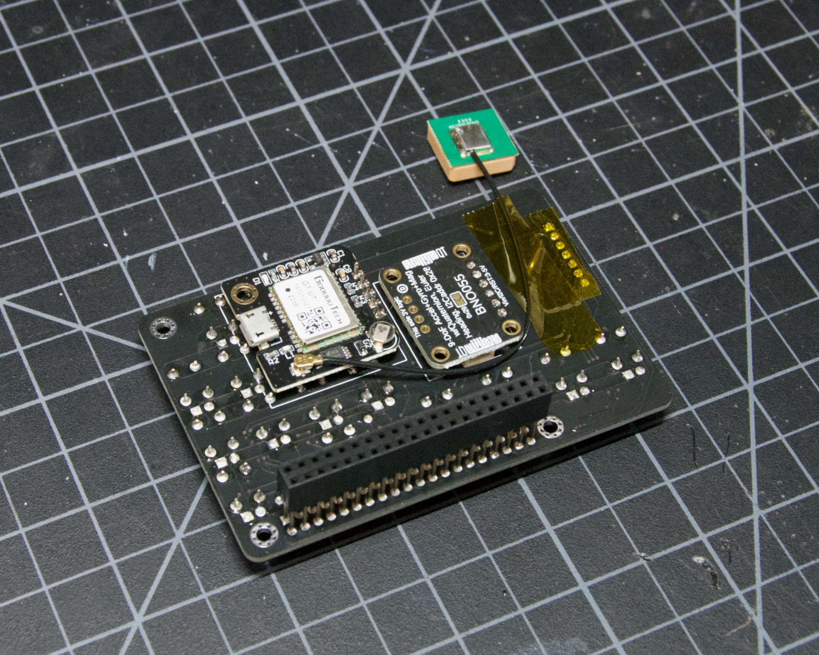
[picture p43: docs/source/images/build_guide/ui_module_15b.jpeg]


Connector
------------------

Attaching the GPIO connector is the last soldered bit for the Hat.  To get this properly spaced, you'll need to mount the PCB to your Pi using the stand-off's you'll be using for final assembly.  

The pins on the connector are long to accommodate various spacings.  Plug the connector firmly into your Pi and once you have mounted the PiFinder hat to your Pi with stand-offs/screws you'll be able to solder the connector with the correct spacing.

Make sure you've added any heatsinks you plan to use. Take your time here and make sure the hat is secured properly to the Pi, that there is no mechanical interference, and that you're satisfied with the spacing before soldering the connector.  

Check the photos below for the procedure, it's easier than it sounds!  There are a lot of pins, make sure each is secure as this
part can have force applied as the hat is installed and removed.  

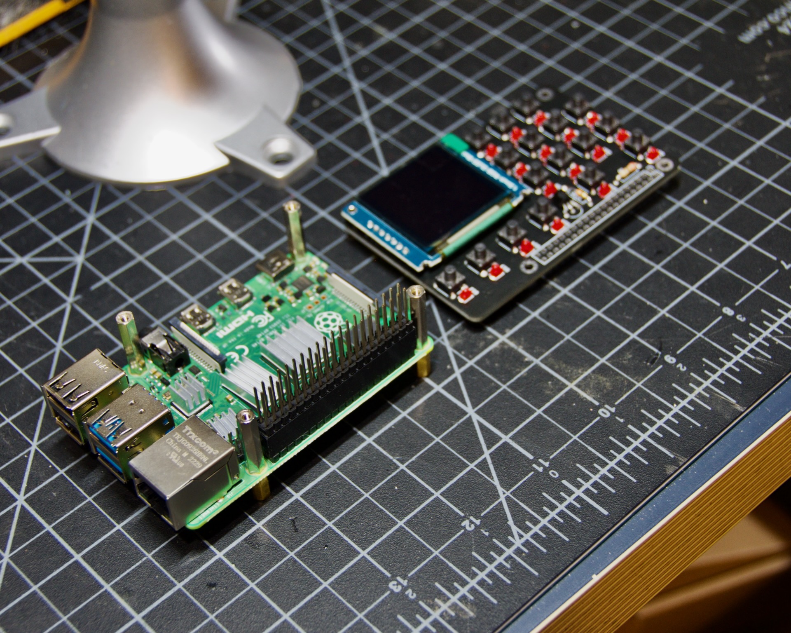
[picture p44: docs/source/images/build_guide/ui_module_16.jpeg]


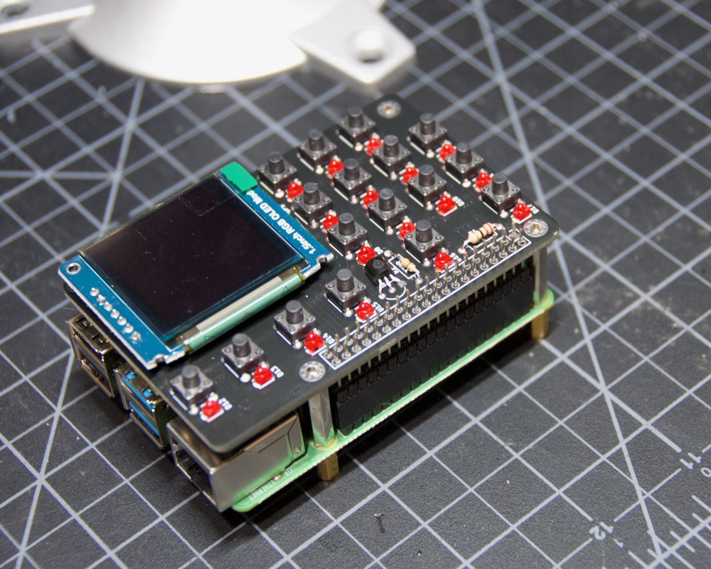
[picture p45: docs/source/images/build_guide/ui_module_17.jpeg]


After you have all the pins soldrerd, it's a good time to insert the SD card and power it up to double check everything is working

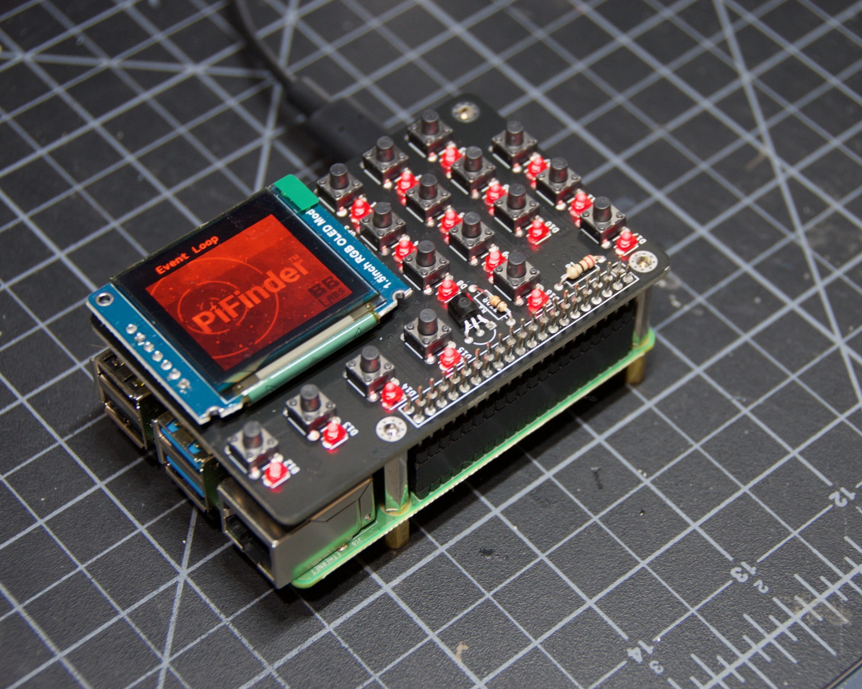
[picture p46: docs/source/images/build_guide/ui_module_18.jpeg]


There you go!  The PiFinder hat is fully assembled and you can move on to printing your parts or :ref:`final assembly<build_guide:assembly>`

Configurations Overview
========================

There are three different ways to build a PiFinder allowing it to be convieniently used on a variety of telescopes.  

.. list-table::

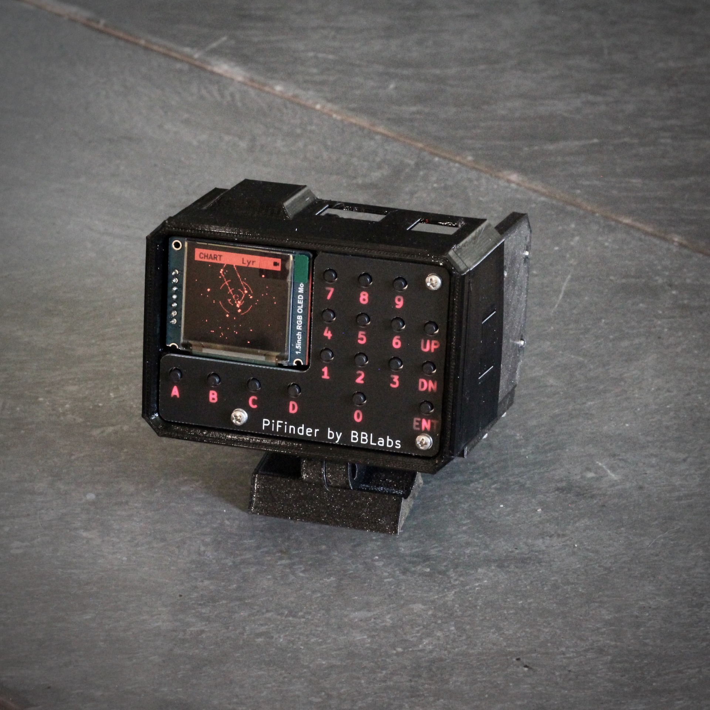
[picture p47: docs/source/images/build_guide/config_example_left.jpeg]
   * - 

          Left Handed

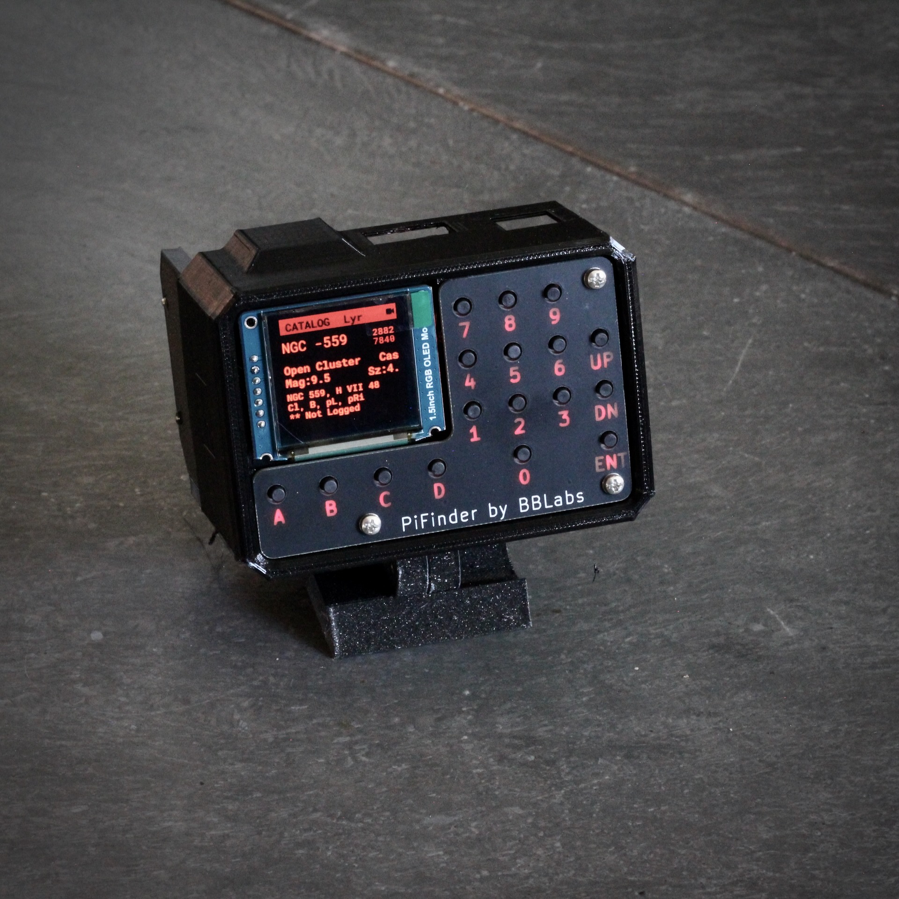
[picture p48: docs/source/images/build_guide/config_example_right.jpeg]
     - 

          Right Handed

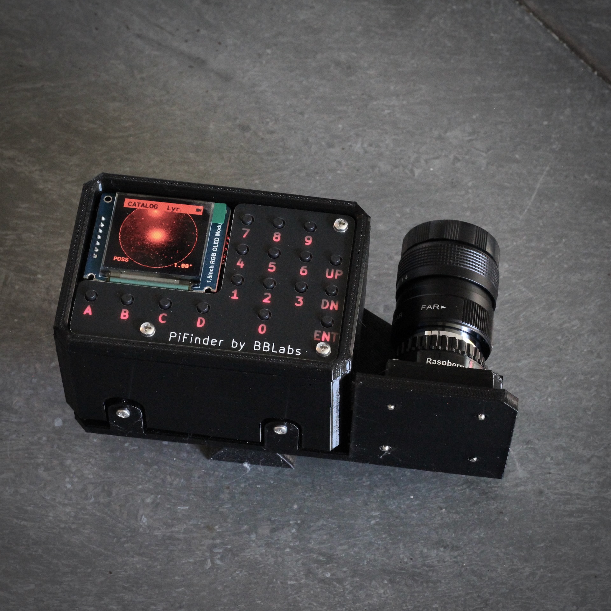
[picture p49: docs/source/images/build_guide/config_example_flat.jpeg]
     - 

          Flat

Any configuration can technically work with any scope, but since the camera always needs to face the sky the different configurations allow the screen and keyboard to be placed for easy access.  The Left and Right configruations are primarily for newtonian style scopes, like dobsonians, which have the focuser perpendicular to the light path.

The Flat configuration places the keypad and screen in easy reach for refractors, SCT's and other rear-focuser scopes.  When the scope is pointed upward, the screen is tilted towards you for quick access.

All the STL files for the PiFinder case parts can be found in the main `PiFinder git repo case folder <https://github.com/brickbots/PiFinder/tree/release/case>`_

Printed Parts
===========================

The PiFinder can be built in a left, right or flat configuration to work well on many types of telescopes.  See the :ref:`configurations overview<build_guide:configurations overview>` for more information including example photos.  To build each configuration, only a subset of the available parts are required.

Common Parts
-----------------------

There are some parts which are common to all three configurations.  The Bezel, Camera Cover and RPI Mount are used in all configurations. 

Right and Left configurations
^^^^^^^^^^^^^^^^^^^^^^^^^^^^^

Below is an image showing all the parts required to build a left or right hand PiFinder.  
Due to the use of edge inserts, these pieces can be assembled in either left, or right, handed 
configurations so you just need the one set of parts regardless of which side your focuser is 
facing.  In the assembly guide you'll find info about how to orient the pieces as you put them together. 

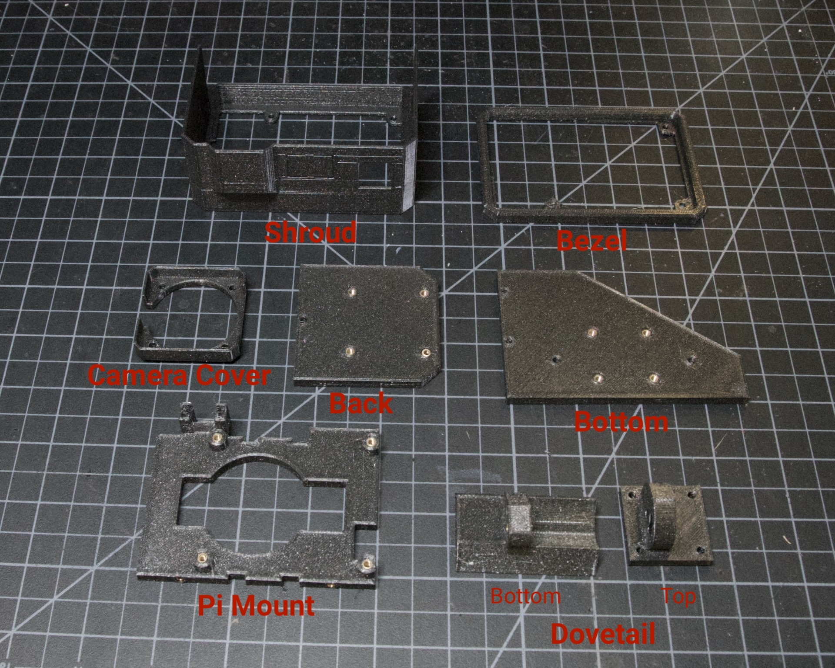
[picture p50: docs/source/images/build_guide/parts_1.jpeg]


Flat Configuration
^^^^^^^^^^^^^^^^^^

The pieces required for building the flat versions are pictured below.  The same parts are used with or without a PiSugar battery.

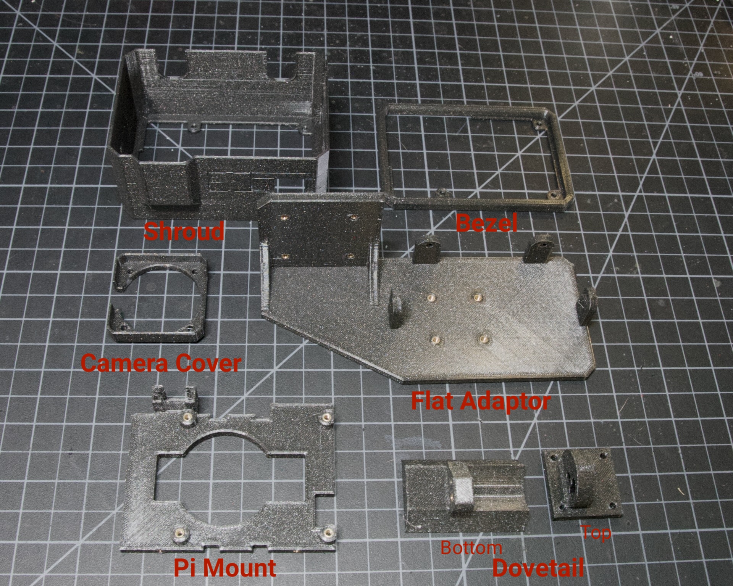
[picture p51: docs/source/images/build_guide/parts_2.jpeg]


Printing
--------

These pieces will print without supports in the orientation shown in the photos.  I use 3 perimeter layers and 15% infill, but the pieces are not large and don't need to handle heavy forces so almost any print settings should work.

You will want to consider using a material other than PLA, as your PiFinder is likely to experience some sunlight in it's lifetime and PLA degrades under moderate heat and UV.  PETG or some co-polymer like NGen would be a good choice.  Prusament Galaxy PETG is the official PiFinder filament and is pictured in most of the build guide, except where grey provided needed contrast.

Inserts
-------

Only some holes receive inserts, the rest have M2.5 screws inserted through them into the inserts in other pieces.  The brass inserts used in this project are 
M2.5 x 4mm long.  There are some inserts that go into holes through the entire piece thickness, and some that go into blind holes in the edges.  Each part
with inserts is pictured below for reference:

Pi Mount
^^^^^^^^^

There are eight inserts total for the Pi Mount.  Four go in the printed stand-offs and four go into the edges.

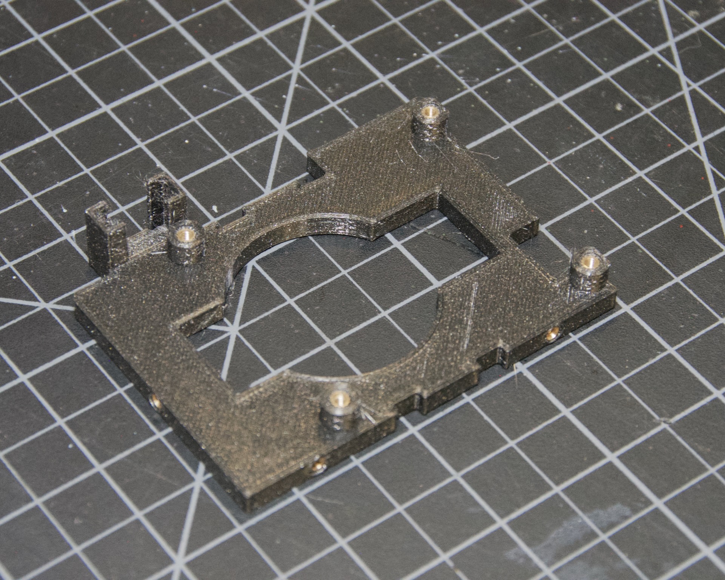
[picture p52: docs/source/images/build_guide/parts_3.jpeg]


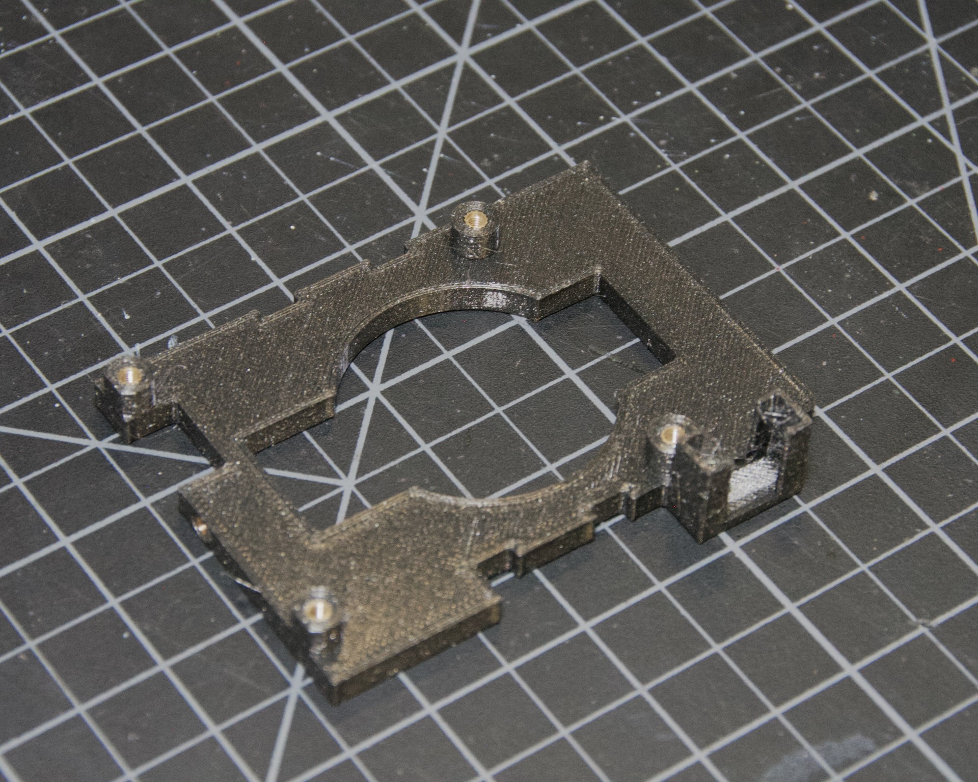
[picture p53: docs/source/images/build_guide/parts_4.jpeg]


Bottom
^^^^^^^

For left/right builds this is the bottom piece.  It needs four inserts for attaching the dovetail mount.

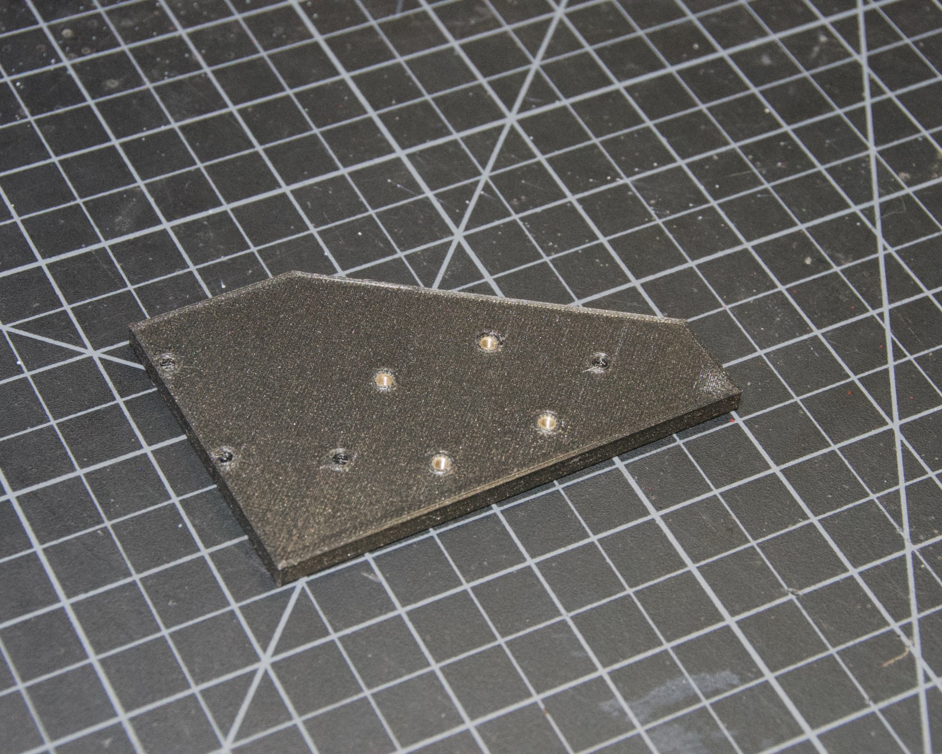
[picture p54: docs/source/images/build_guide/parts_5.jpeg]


Flat Adaptor
^^^^^^^^^^^^^
.. note::
   The photos for the Flat Adaptor and the Back shown here are for the v2 build.  The v2.5 parts 
   are almost identical, but have 2 camera mount holes rather than 4. 

This piece takes the place of the bottom and back piece in the left/right build.  It needs eight inserts, 
four to attach the dovetail mount and four to attach the camera

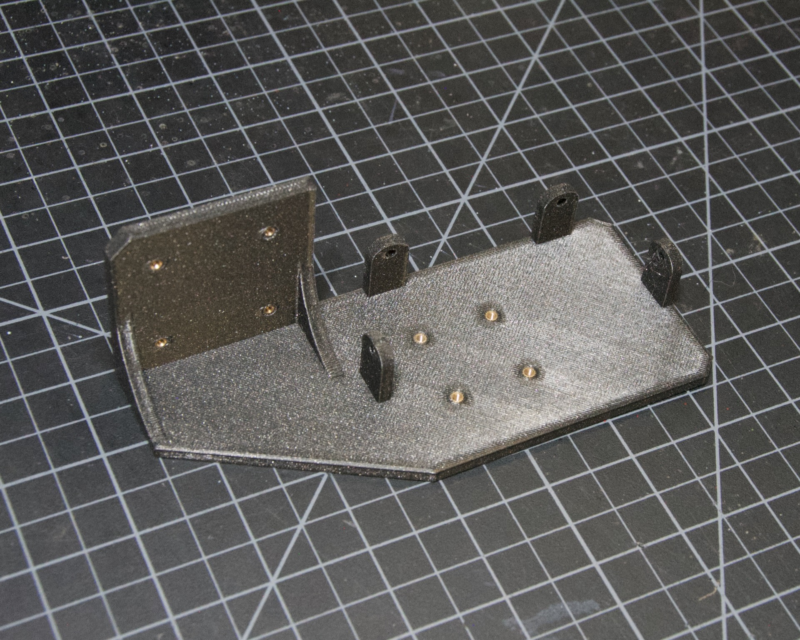
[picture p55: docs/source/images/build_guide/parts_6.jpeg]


Back
^^^^^^^^^

The back piece holds the camera for left/right builds and reinforces the PiMount and Bottom piece to 
help keep everything squar and sturdy.  It needs six inserts; four to mount the camera and two in the bottom
edge to connect with the bottom piece

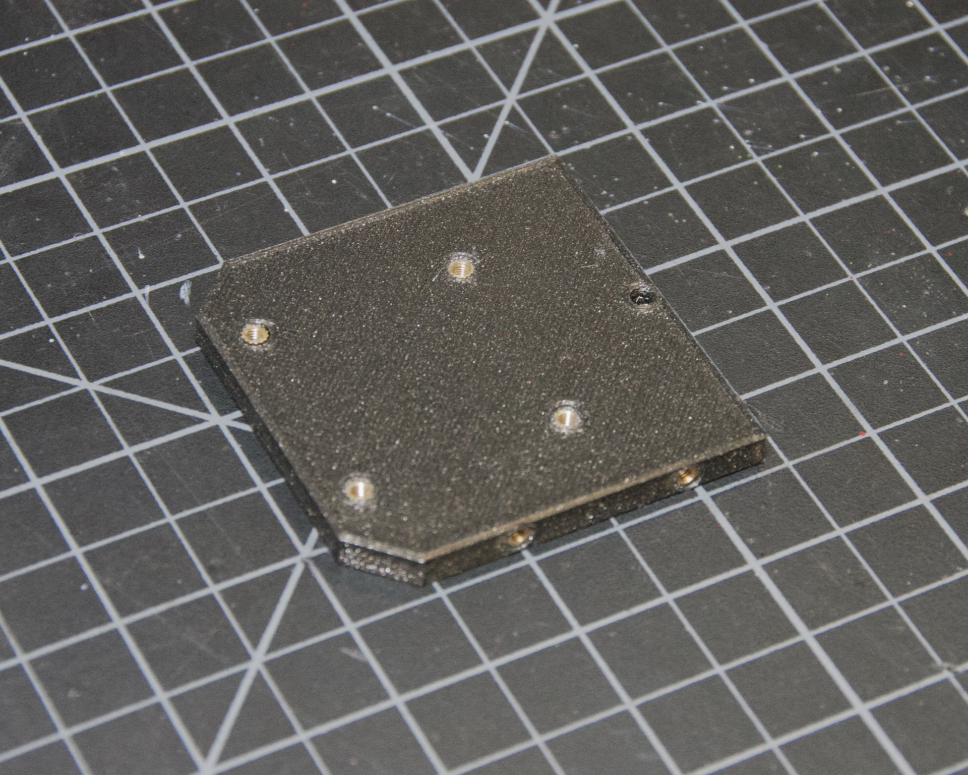
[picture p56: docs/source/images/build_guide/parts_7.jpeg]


Dovetail Bottom
^^^^^^^^^^^^^^^^

The dovetail bottom has two inserts to receive the longer 12mm screws which allow angle adjustment.  These inserts
are placed in the side opposite where the top piece connects.  The screws pass through the top piece and part of the 
bottom before engaging with the inserts.  This makes this assembly strong enough to hold the set angle with the screws 
sufficiently tightend.



Installation
^^^^^^^^^^^^^

Because I use a lot of these inserts, I use a tool to help seat them plumb into the parts,  but I've done plenty freehand and it's not overly difficult.  Use a temperature a bit below your normal printing temperature (for reference, I print PETG at 230c and use 170-200c for inserts) and give the plastic time to melt around them.  

Insert Inserting

Mounting
--------

Most people will want to print the dovetail mount which fits into the finder shoe included on most telescopes.  
The dovetail mount is angle adjustable.  This allows to orient the screen surface (roughly) vertical and perpendicular to the ground. 
This puts the inertial motion sensor into the expected position. See the image below for a better explanation:

Finder shoe angle

Adjustable Dovetail Assembly
^^^^^^^^^^^^^^^^^^^^^^^^^^^^

If you print your own parts, you'll need to add heat-set inserts as pictured in the photo above.  Note that the inserts must be inserted from the outside of the bottom piece, as pictured.  The holes on the inside are not large enough for inserts, they just allow the screws to pass through into the inserts.

See the photos below for how the pieces fit together.  Once assembled you can loosen both screws to adjust the angle up to 40 degrees from horizontal and then secure them again.  No need to go too tight, but a bit of friction will be required to hold the angle.









If you need more flexibility, there is also a go-pro compatible plate that will bolt into the bottom plate.  You'll need to add inserts into the bottom plate mounting footprint to use this option.

Once you've got all the parts printed and inserts inserted, you're ready to :ref:`assemble<build_guide:assembly>`!

Rigel Quickfinder Assembly
^^^^^^^^^^^^^^^^^^^^^^^^^^

This is the list of things, that you'll need for a Rigel Quickfinder adapter: 

.. list-table::
   :header-rows: 1

   * - Qty
     - Item
     - URL
     - Notes
   * - 1
     - PiToQuickfinder v2 - Part 1.stl
     - `git repo quikfinder <https://github.com/brickbots/PiFinder/tree/release/case/adapter/quikfinder>`_
     - You'll need both this and the next item
   * - 1
     - PiToQuickfinder v2 - Part 2.stl
     - `git repo quikfinder <https://github.com/brickbots/PiFinder/tree/release/case/adapter/quikfinder>`_
     - You'll need both this and the previous item
   * - 2
     - heat-set insert M2.5 x 4 mm 
     - 
     - Same as for the case

Please make sure to print "Part 2" in way, such as to maximize the strength of the "hook"! Please print it with supports like this: 



If you print your own parts, you'll need to add heat-set inserts as pictured in the photos below. As the space is limited, you'll need to
fix it first to the PiFinder and then insert the second part. Just tighten the screws a little bit, to hold the second part, so it can't fall off.

After putting it on a Rigel Quickfinder base, tighten the screws fully. Note that the foam double-sided adhesive that's distributed with the
Rigel Quikfinder might be compressed by the weight of the PiFinder (the PiFinder is ~6 times the weight of a Quikfinder), so you might need to reconsider
how the base plate is fixed to your scope.  







Optionally, if you need to adjust the orientation of your PiFinder to make it vertical on your scope, you need these in addition:

.. list-table::
   :header-rows: 1

   * - Qty
     - Item
     - URL
     - Notes
   * - 1
     - Pi2Q2Dovetail.stl
     - `git repo quikfinder <https://github.com/brickbots/PiFinder/tree/release/case/adapter/quikfinder>`_
     - You'll at least need this and the next item
   * - 1
     - dovetail_top.stl
     - `git repo dovetail <https://github.com/brickbots/PiFinder/tree/release/case/v2>`_
     - You'll at least need this and the previous item
   * - 6
     - heat-set insert M2.5 x 4 mm 
     - 
     - Same as for the case
   
You need to add 4 heat-set inserts as indicated in the following pictures:





The assembly is then like the dovetail assembly in the previous section. Depending on your needs, you can fix the optional adapter 
in two orientations. Make sure the "long lip" is pointing in the same directions like the PiFinder. The completely assembled adapter looks like this:





Once you've got all the parts printed and inserts inserted, you're ready to :ref:`assemble<build_guide:assembly>`!

Assembly
======================

Assembly Overview
-----------------

From here on out you'll need the M2.5 screws, stand-offs, and thumbscrews along with the 3d printed parts, UI hat and other bits like the camera, lens and GPS unit.  Most of the photos in this part of the guide show a build with the PiSugar, but if you are powering the PiFinder in some other way, the assembly is almost identical.

*In all cases, don't over tighten the hardware!*  There is no need and you could end up damaging the 3d printed pieces, inserts or screws.  Once they feel snug, that's probably enough force.  The case forms a ridged assembly once everything is in place and will easily support the camera and other bits.

Pi Mounting
---------------------------

The first step is to mount the Pi and PiSugar battery to the Pi Mount piece.  The pieces you'll need are shown below

Build Guide Step

Regardless of the orientation of your build, the Raspberry Pi and battery always mount in this same orientation.  The Raspberry Pi and PiSugar (if you are using one) will mount on top of the posts in the RPI Holder.

If you are using a PiSugar it's time to mount the battery pack.  If not, just skip this step and continue on.  Flip the PiMount piece over and use the zip ties to secure the battery as shown.  No need to tighten these down very much, doing so may damage the battery.  It needs just enough to keep it from moving too much. 

Mind the orientation of the battery pack to make sure the connector is situated in the notch as shown below



Snip the zip-ties off and you are ready to move on.



Camera Prep
---------------------------

The new v3 camera may come with one of two different lens holders aready installed. No matter 
which your camera has you'll be removing and replacing it.



Some cameras have pin headers installed, if you have one of these, you'll need to clip them as close
as reasonable to the board. It can help here to remove the black plastic portion by pulling it with
a pair of pliers.  Alternatively, you can just cut through it to get as close to the PCB as possilble.
Take care not to clip any of the surrounding components.





Grab the lens holder and look through it to make sure it's clear of any obstructions.

Place the lens holder on the table with the large side up oriented as in the photo below.  The two screw
tabs on the lens holder must stick out the opposite sides from the cream-white and dark-grey cable connector on the PCB.
You'll be removing the two screws (yours might be black) near the center of the green PCB and lifting it gently
to the new lens holder.  

Mind the sensor surface on the under side of the PCB. It should sit nicely in the square recess of the lens holder.
Use the same two screws to affix the sensor PCB to the lens holder.  The screws will be cutting their own threads, but
there are holes there to help get started.  Tighten the screws down against the PCB so nothing is wiggling/moving.





Flip the camera assembly over and thread in the lens.  Be slow and careful here.  With gentle force
the lens should slide in a few MM to get everything align and stop.  When it stops, check to make sure it seems 
straight and start screwing it into place.  To get focus about right, You'll want a 6mm gap (picured below) between the 
top of the lens holder and the bottom of the lip on the lens.  Don't fret too much about it as you'll do final focus 
under the stars.





Cable Routing
---------------------------

If you are building a flat unit, just set the camera cable to the side as it gets routed in a different manner.  For left/right builds, it's easier to get the cable roughly positioned now.

Return to the Raspberry Pi assembly and thread the camera cable through as shown.  Note the orientation/direction of the silver contacts at each end of the cable.  The photos below show the cable routing for left and right hand builds.

.. list-table::

   * - 

       Left hand cable routing

     - 

       Right hand cable routing

.. important::
    If you are using the recommended S Plus unit, now is the time to make sure you've got it all prepared.

    * Turn the 'Auto Startup' switch on the bottom of the unit to OFF. Having this in the ON position will prevent i2c from working and the IMU will not be used. See the image below:  The switch is outlined in orange, and the photos shows the correct OFF position.

    * The blue power light on the PiSugar board is very bright.  You'll definitely want to cover it with some black nail polish or use a soldering iron to destroy it.  Plug it in to the battery and turn it on to make sure it's subdued.  Check the image below for the position of this LED.  It's already blacked out with nail polish in the photo, but the orange arrow indicates which one you'll want to cover.

Build Guide Step

The PiSugar will have a protective film on the screw posts as seen in the photo below, make sure to remove this or you'll have a frustrating time getting everything screwed together.

Build Guide Step

The PiSugar sits under the Raspberry Pi with the gold pogo pins pressed up against the bottom of the Raspberry Pi.  The side facing up in the image above is the side that should press against the bottom of the Raspberry Pi.  The PiSugar documentation has more info if needed. 

The combined PiSugar/RPI stack then gets secured to the PI Mount using the 20mm stand-offs.  The photos below show the right/left hand stack with their respective cable routing.  For flat configurations, it builds just the same without any camera cable.

.. list-table::

   * - 
     
          Left hand PiSugar stack

     - 
     
          Right hand PiSugar stack

   * - 
     
          Secured with stand offs

     - 
     
          Secured wiith stand offs

Right / Left Configuration
---------------------------

Continue on with this section to build a Right/Left hand unit.  The build progresses the same for both versions with some differences in the part orientation.  
You'll see photos for each step with left hand version on the left and right on the right.

Now that the RPI is mounted, it's time to secure the mount plate to the bottom plate.  The bottom plate can be flipped to allow for the screen to 
be facing the right, or left side.  As you can see from the two photos below.

In both cases, the RPI/Screen will always be face the same direction as the long, flat side of the bottom piece.  The angled cut out is 
always on the camera side, and the lens faces the angled portion.  

.. list-table::

   * - 

     - 

The first step is to screw the Pi Mount assembly to the bottom plate.  You'll use two screws from underneath running through the bottom plate into the threaded
inserts in the side of the Pi Mount piece.

.. list-table::

   * - 

     - 

The back piece is next, but first screw in the four short stand-offs which will support the camera module.  These stand-offs
can be screwed in either side for left or right hand configurations.  Take a look at photos below to match up how the 
back piece fits with both configurations to decide which side to put the stand-offs in.

.. list-table::

   * - 

     - 

   * - 

     - 

Then the back piece secures to the rest of the assembly via three M2.5 8mm screws.  One goes through the 
back plate into the side-insert in the RPI Mount, there is one of these inserts on either side of the 
RPI Mount for left/right hand builds.  The other two go through the bottom plate into the side-inserts 
on the back plate. 

.. list-table::

   * - 

     - 

   * - 

     - 

Now it's time to mount the camera module.  You'll need the module, camera tray and 2x12mm m2.5 screws

.. note::
   The images here show an older back piece and camera tray. New kits have a back piece 
   with two holes which match the camera holder.  In this simpler arrangment the camera
   tray is not directly secured to the back piece, but rather has two holes through it.
   The camera holder is secured with longer screws through the tray into the two holes
   in the back piece

Start by connecting the cable to the new camera module.  Open the connector all the way
by sliding the dark-grey piece away from the PCB.  Be gentle as this part can break with too
much force. 

Once the connector is open, slide the cable into the connector using gentle force and making 
sure it's well aligned.  Take you time and watch the
dark-grey clip.  It should not close as you are inserting the cable, and if it does, you'll need
to re-open it to get the cable to slide in all the way.

Once the cable is seated in the connector, close the dark-grey clip by sliding it shut, this 
may take a little force to get it completely closed.  Check the photo below if in doubt!



Situate the camera in the adapter and use the two new screws to secure it.  They are 
the same size as the other four, if they get mixed up.





.. note::
   The remainder of the build guide is yet to be updated with new photos
   including the v2.5 camera.  The build proceeds just the same and we
   will be updating the photos soon.

Flip the unit over and connect the RPI end of the camera cable.  The photo below show the proper orientation of the cable into the connector.  Note the silver contacts facing the white portion of the connector.



For the left hand version you will need a twist in the cable before it enters the connector on the RPI.  Be gentle with it and you'll be able to adjust as you put on the UI Module later.

.. list-table::

   * - 

     - 

.. note::
   The remainder of the build is almost the same for left or right hand units.  The photos below are a mix of left and 
   right handed builds, but where there are important differences, you'll see both indicated for clarity.

Next up is to connect the UI Board and affix the shroud. Lay out the board as it will be connected and slide the antenna into the holder on the Pi Mount piece.  
The ceramic top with the silver dimple on it needs to face upwards.  Consult the photos below







.. note::
   The images above have the GPS cable loose and not routed properly.  Please use the 
   routing shown in the :ref:`GPS<build_guide:gps>` section

Now carefully plug the UI Module into the Raspberry Pi.  Make sure both rows of pins are aligned and take your time to 
manage the camera and GPS cables.  The photos below show the left and right configurations for the cable routing.

.. list-table::

   * - 

     - 

The screw holes on the UI Board should line up with three of the four stand-offs.  The fourth provides support, but does is not used to secure the outer case. Collect up the Shroud, Bezel and cover plate along with three of the 12mm screws for the next steps



The shroud has three optional openings, one for the PiSugar power switch on top, one for the USB ports, 
and one for the SD Card on the side if you want easier access.  These can all be removed with a little force 
or a sharp knife.  If you are using a PiSugar battery, you'll absolutely need to make sure that tab is removed
See the photo below:



Slide the shroud over the unit then stack the bezel and the front PCB plate on top and secure
them all with the three screws









That's looking great!  Now we just need a way to mount it to the scope.  The top portion of the adjustable dovetail
gets screwed directly to the bottom of the PiFinder and then the bottom portion of the dovetail gets secured to the 
top portion.  The orientation of the top part is important to make sure the dovetail adjusts the proper way.  See
the left/right hand photos below:





It's tricky to photograph the final dovetail assembly details on the PiFinder, so check these photos below
and secure the bottom dovetail portion to the top:









The final step is to Go ahead and screw on the camera lens.  The cap on the Pi HQ camera screws off, 
but leave the knurled metal spacer there or the lens will not reach focus properly. 

Gently screw the lens into the camera module.  You'll need to hold the module with your hand as you tighten the lens.





That's it! You now have a fully assembled PiFinder!  

Continue on to the :doc:`software setup<software>` if you've not already prepared a SD card.  



Flat Assembly
----------------

This section of the build guide contains the steps to complete a Flat build.  This configuration is great for refractors, SCT's and other scopes with rear-focusers as the screen is 'flat' when mounted and the camera faces forward:

Flat example

If you have not already followed the :ref:`general assembly guide<build_guide:assembly>` through to get to the point pictured below, please do so and then return here.

Pi Module Assembled

If you routed the cable as above, pull the camera cable out to remove it from the RPI assembly as the routing is different for a flat build.  

Collect the flat adapter and dovetail.  The dovetail will be secured to the underside of the flat adapter via screws through the adapter and the RPI mount assembly will slot into it the flat adapter and be secured via screws into the edge inserts.  See the photos below for details.

Assembly Steps

Assembly Steps

Assembly Steps

Assembly Steps

Assembly Steps

Note the one additional screw on the other side visible in the next photo.  Once the RPI Mount is secured to the flat adapter, connect the camera cable to the RPi and the Camera as shown below.

Assembly Steps

Turn the PiFinder around and screw in the three thumbscrews as shown.  Check for any excess plastic in the threads and if you run into resistance, try screwing them from the other side first to clear any obstruction.   Screw them most of the way in, but leave some amount for adjustment.

Assembly Steps

Next you'll position the camera module and use the longer M2.5 screw to secure it.  The screw should be inserted through the center hole in the flat adapter back and threaded into the center hole in the camera cell.  It should screw in 3-4mm and pull the camera cell against the ends of the three thumbscrews.  If it's not secure, extend the thumbscrews until it's supported.  No need to tighten anything too much here, you'll adjust again to align the PiFinder with your telescopes optical axis.

Assembly Steps

Gently plug in the UI Module, working to tuck the cable underneath it.  Take you time and make sure the camera cable is not pinched between the stand-offs and the UI Module.

Assembly Steps

Assembly Steps

Assembly Steps

Once the UI Module is plugged in all the way and the cable is tidy, gather the remaining parts to wrap up the build!  The shroud will slip over the UI Module first, then the bezel slots on top and finally the top PCB.  Use three of the long screws to secure everything together per the photos below.

NOTE:  If you have not already flashed and inserted the SD card into the Raspberry Pi, nows a good time.  It will be harder to get to after the shroud is installed.  Also check to make sure the PiSugar power switch access is cut and punched out of the shroud if you are using a PiSugar.

Assembly Steps

Assembly Steps

Assembly Steps

Assembly Steps

Assembly Steps

The only remaining thing to do is to affix the camera lens.  Unscrew the cap from the camera module, but make sure you leave the knurled adapter in place as it's required to get the focus distance correct.  Remove the cap from the silver end of the lens and gently screw them together.

Assembly Steps

Congratulations, you have a PiFinder! See the :doc:`Software Setup<software>` guide for next steps!

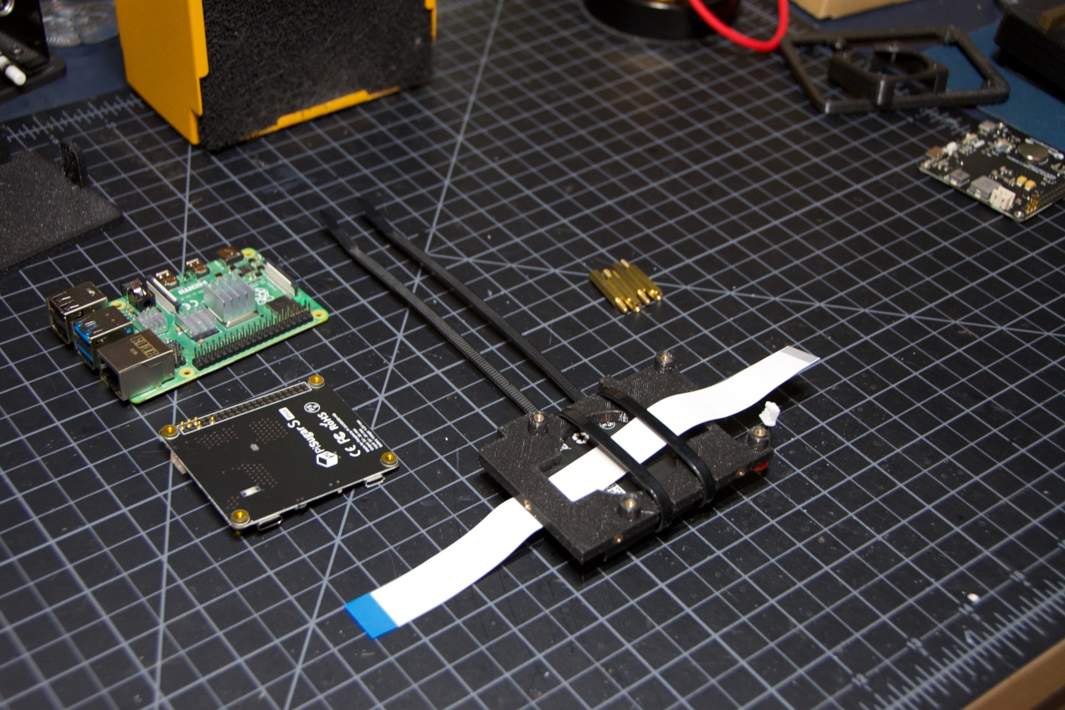
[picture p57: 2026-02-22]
docs/source/images/build_guide/cable_routing_right01.jpeg

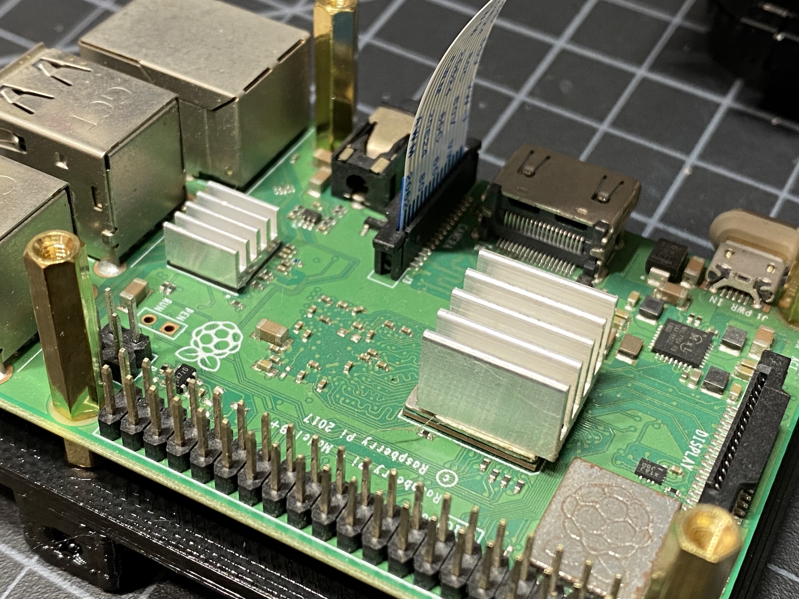
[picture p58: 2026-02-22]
images/build_guide/IMG_4690.jpeg

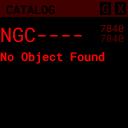
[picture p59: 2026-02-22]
images/screenshots/how_to_see_CATALOG_001.png

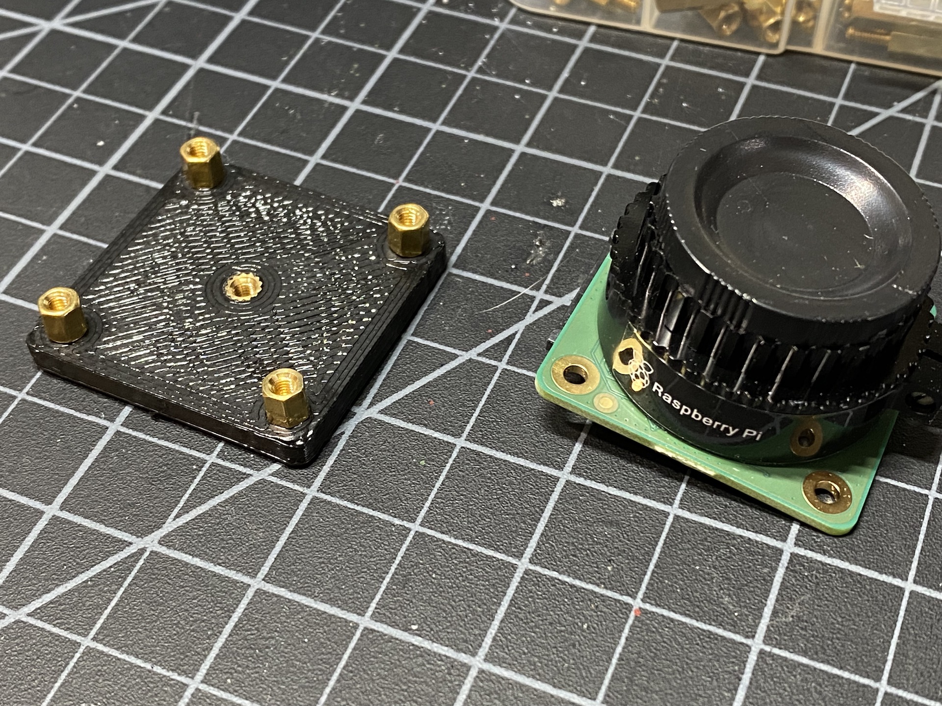
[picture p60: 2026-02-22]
images/build_guide/IMG_4707.jpeg

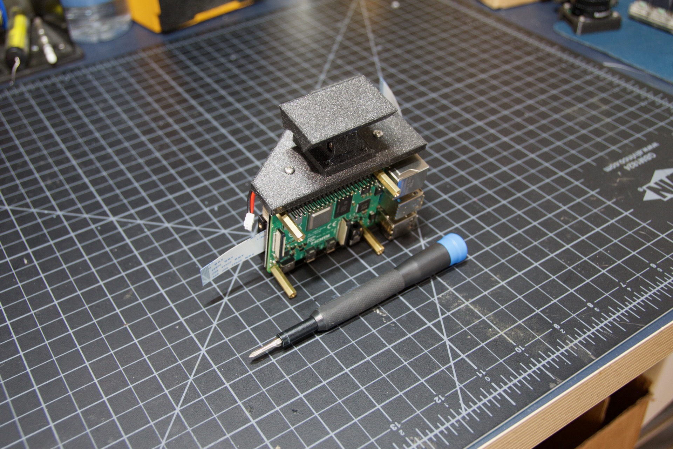
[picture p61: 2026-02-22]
images/build_guide/v1.6/build_guide_18.jpeg

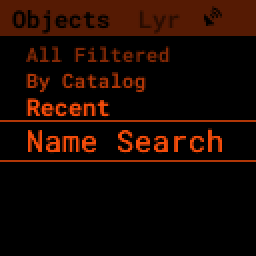
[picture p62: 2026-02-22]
docs/source/images/user_guide/name_search_01.png

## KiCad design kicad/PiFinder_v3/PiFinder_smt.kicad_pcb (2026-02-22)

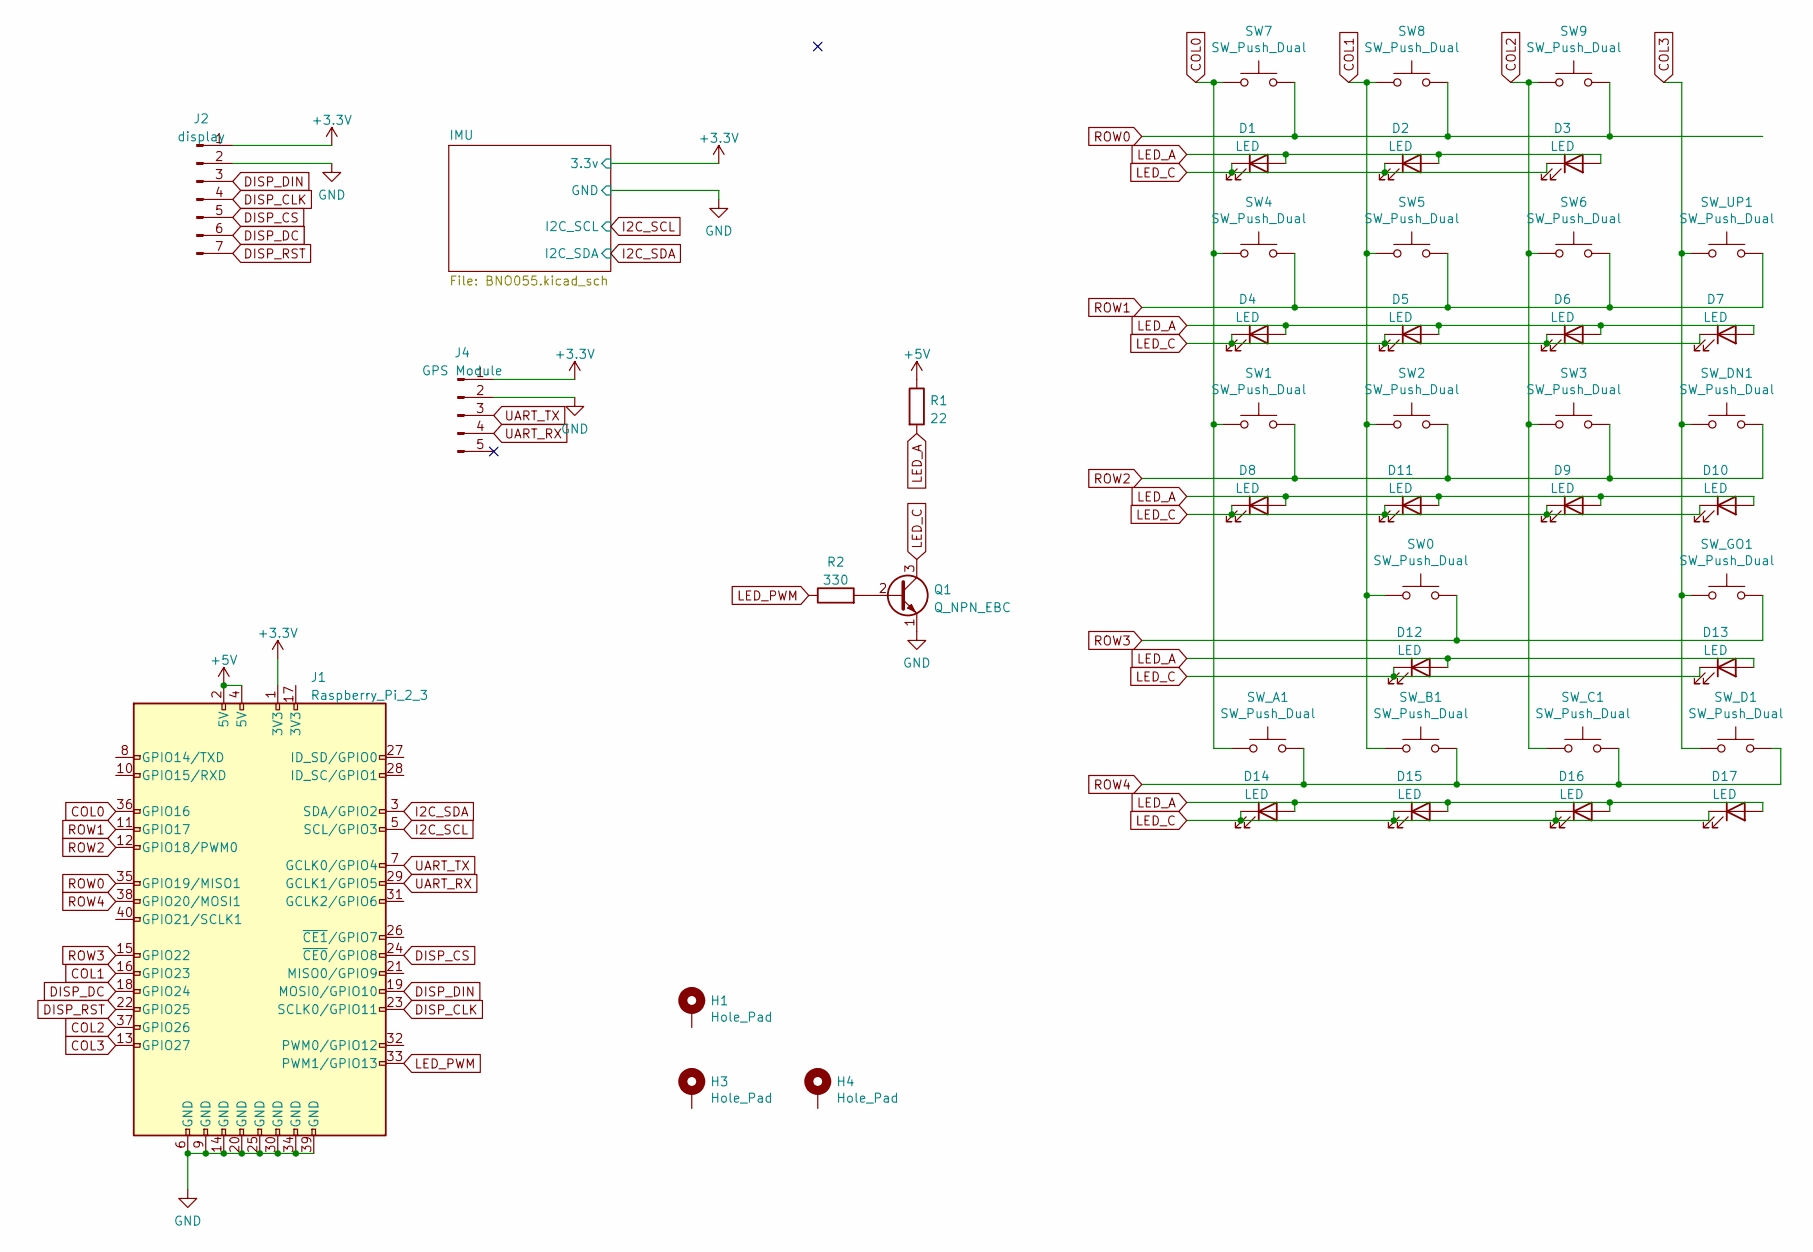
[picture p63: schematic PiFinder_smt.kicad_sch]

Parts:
D1, D2, D3, D4, D5, D6, D7, D8, D9, D10, D11, D12, D13, D14, D15, D16, D17: LED; LED_1210_3225Metric; LCSC C125112
H1, H3, H4: Hole_Pad; Mount_M2.5
J1: Raspberry_Pi_2_3; Pin_Header_Straight_2x20
J2: display; Waveshare1.5inOled_flushmount
J4: GPS Module; GT-U7_GPS_smt
Q1: Q_NPN_EBC; PF_SOT-23-NPN; LCSC C280842
R1: 22; R_0805_2012Metric; LCSC C17561
R2: 330; R_0805_2012Metric; LCSC C17630
SW0, SW1, SW2, SW3, SW4, SW5, SW6, SW7, SW8, SW9: SW_Push_Dual; SW_Push_6x6mm_SMT_withhole_tight; LCSC C4364377
SW_A1: SW_Push_Dual; SW_Push_6x6mm_SMT_withhole_tight; LCSC C4364377
SW_B1: SW_Push_Dual; SW_Push_6x6mm_SMT_withhole_tight; LCSC C4364377
SW_C1: SW_Push_Dual; SW_Push_6x6mm_SMT_withhole_tight; LCSC C4364377
SW_D1: SW_Push_Dual; SW_Push_6x6mm_SMT_withhole_tight; LCSC C4364377
SW_DN1: SW_Push_Dual; SW_Push_6x6mm_SMT_withhole_tight; LCSC C4364377
SW_GO1: SW_Push_Dual; SW_Push_6x6mm_SMT_withhole_tight; LCSC C4364377
SW_UP1: SW_Push_Dual; SW_Push_6x6mm_SMT_withhole_tight; LCSC C4364377

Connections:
+3.3V: J1.1 (3V3), J2.1, J4.1; also elsewhere on the board
+5V: J1.2 (5V), J1.4 (5V), R1.1
COL0: J1.36 (GPIO16), SW1.1, SW4.1, SW7.1, SW_A1.1
COL1: J1.16 (GPIO23), SW0.1, SW2.1, SW5.1, SW8.1, SW_B1.1
COL2: J1.37 (GPIO26), SW3.1, SW6.1, SW9.1, SW_C1.1
COL3: J1.13 (GPIO27), SW_D1.1, SW_DN1.1, SW_GO1.1, SW_UP1.1
DISP_CLK: J1.23 (SCLK0/GPIO11), J2.4
DISP_CS: J1.24 (~CE0/GPIO8), J2.5
DISP_DC: J1.18 (GPIO24), J2.6
DISP_DIN: J1.19 (MOSI0/GPIO10), J2.3
DISP_RST: J1.22 (GPIO25), J2.7
GND: J1.6 (GND), J1.9 (GND), J1.14 (GND), J1.20 (GND), J1.25 (GND), J1.30 (GND), J1.34 (GND), J1.39 (GND), J2.2, J4.2, Q1.1 (E); also elsewhere on the board
I2C_SCL: J1.5 (SCL/GPIO3); also elsewhere on the board
I2C_SDA: J1.3 (SDA/GPIO2); also elsewhere on the board
LED_A: D1.2 (A), D2.2 (A), D3.2 (A), D4.2 (A), D5.2 (A), D6.2 (A), D7.2 (A), D8.2 (A), D9.2 (A), D10.2 (A), D11.2 (A), D12.2 (A), D13.2 (A), D14.2 (A), D15.2 (A), D16.2 (A), D17.2 (A), R1.2
LED_C: D1.1 (K), D2.1 (K), D3.1 (K), D4.1 (K), D5.1 (K), D6.1 (K), D7.1 (K), D8.1 (K), D9.1 (K), D10.1 (K), D11.1 (K), D12.1 (K), D13.1 (K), D14.1 (K), D15.1 (K), D16.1 (K), D17.1 (K), Q1.3 (C)
LED_PWM: J1.33 (PWM1/GPIO13), R2.1
unnamed: Q1.2 (B), R2.2
ROW0: J1.35 (GPIO19/MISO1), SW7.2, SW8.2, SW9.2
ROW1: J1.11 (GPIO17), SW4.2, SW5.2, SW6.2, SW_UP1.2
ROW2: J1.12 (GPIO18/PWM0), SW1.2, SW2.2, SW3.2, SW_DN1.2
ROW3: J1.15 (GPIO22), SW0.2, SW_GO1.2
ROW4: J1.38 (GPIO20/MOSI1), SW_A1.2, SW_B1.2, SW_C1.2, SW_D1.2
UART_RX: J1.29 (GCLK1/GPIO5), J4.4
UART_TX: J1.7 (GCLK0/GPIO4), J4.3

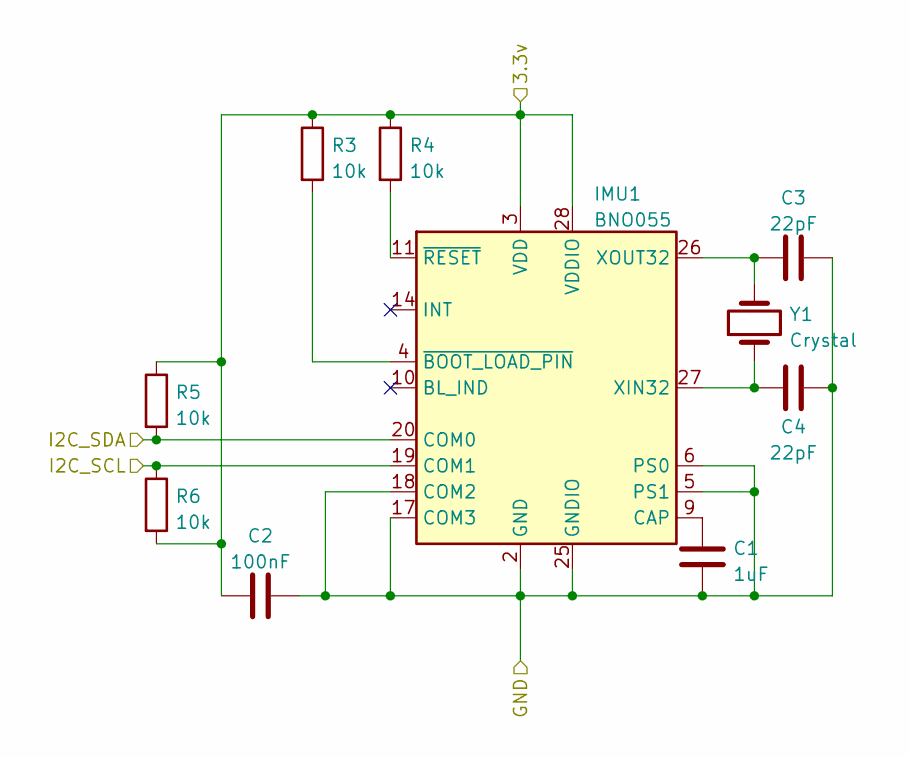
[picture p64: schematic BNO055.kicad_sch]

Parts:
C1: 1uF; C_0805_2012Metric; LCSC C2940738
C2: 100nF; C_0805_2012Metric; LCSC C49678
C3, C4: 22pF; C_0805_2012Metric; LCSC C24658
IMU1: BNO055; LGA-28_5.2x3.8mm_P0.5mm; LCSC C93216
R3, R4, R5, R6: 10k; R_0805_2012Metric; LCSC C17414
Y1: Crystal; Crystal_SMD_3215-2Pin_3.2x1.5mm; LCSC C5366532

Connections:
+3.3V: C2.1, IMU1.3 (VDD), IMU1.28 (VDDIO), R3.1, R4.1, R5.1, R6.2; also elsewhere on the board
GND: C1.2, C2.2, C3.2, C4.2, IMU1.2 (GND), IMU1.5 (PS1), IMU1.6 (PS0), IMU1.15 (GNDIO), IMU1.16 (GNDIO), IMU1.17 (COM3), IMU1.18 (COM2), IMU1.25 (GNDIO); also elsewhere on the board
I2C_SCL: IMU1.19 (COM1), R6.1; also elsewhere on the board
I2C_SDA: IMU1.20 (COM0), R5.2; also elsewhere on the board
unnamed: C1.1, IMU1.9 (CAP)
unnamed: C3.1, IMU1.26 (XOUT32), Y1.2
unnamed: C4.1, IMU1.27 (XIN32), Y1.1
unnamed: IMU1.4 (~BOOT_LOAD_PIN), R3.2
unnamed: IMU1.11 (~RESET), R4.2

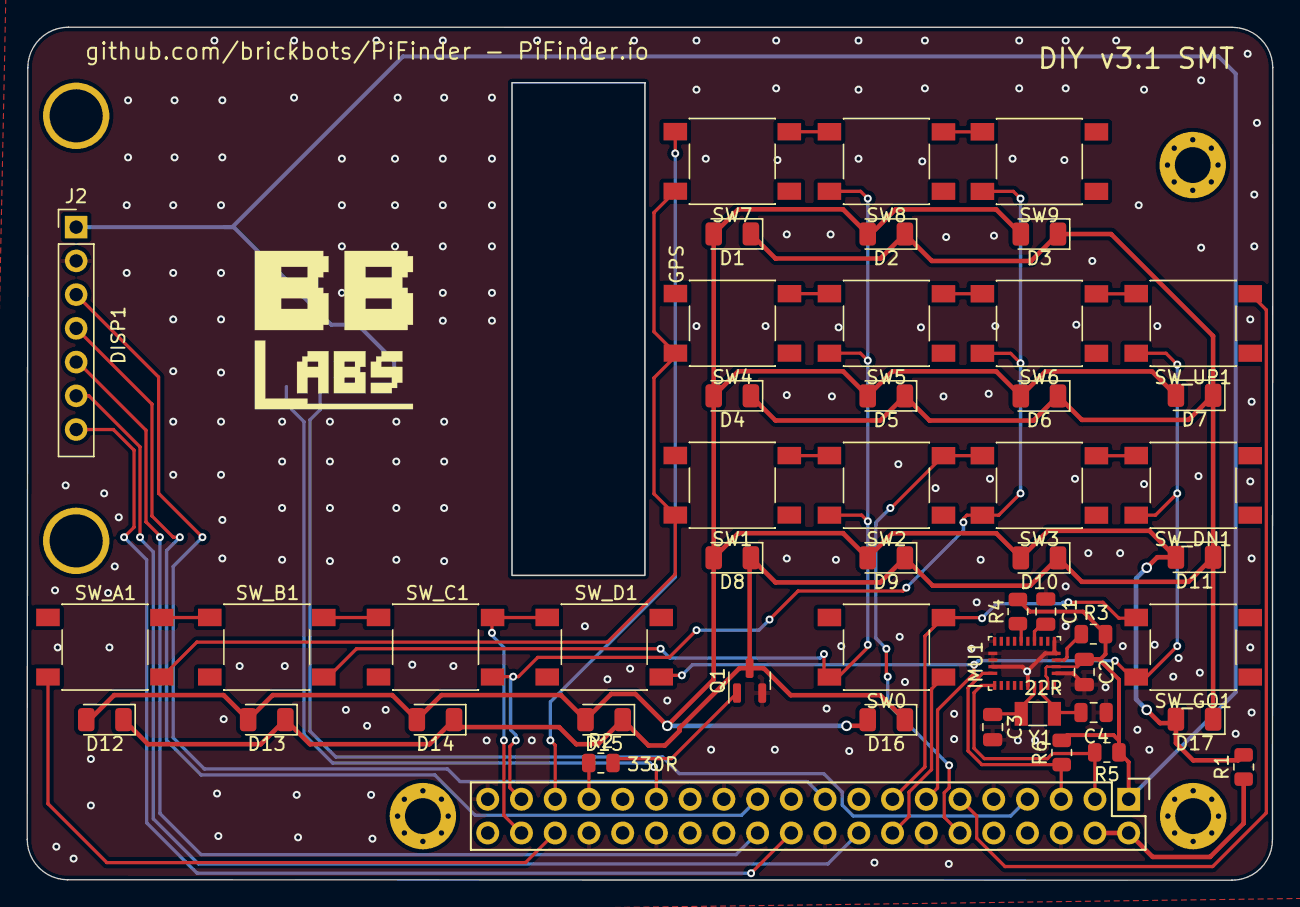
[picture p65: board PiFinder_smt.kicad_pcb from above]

Board: 2 copper layers, 93.8 x 64.2 mm, 53 parts (1 on the bottom side), 30 nets.

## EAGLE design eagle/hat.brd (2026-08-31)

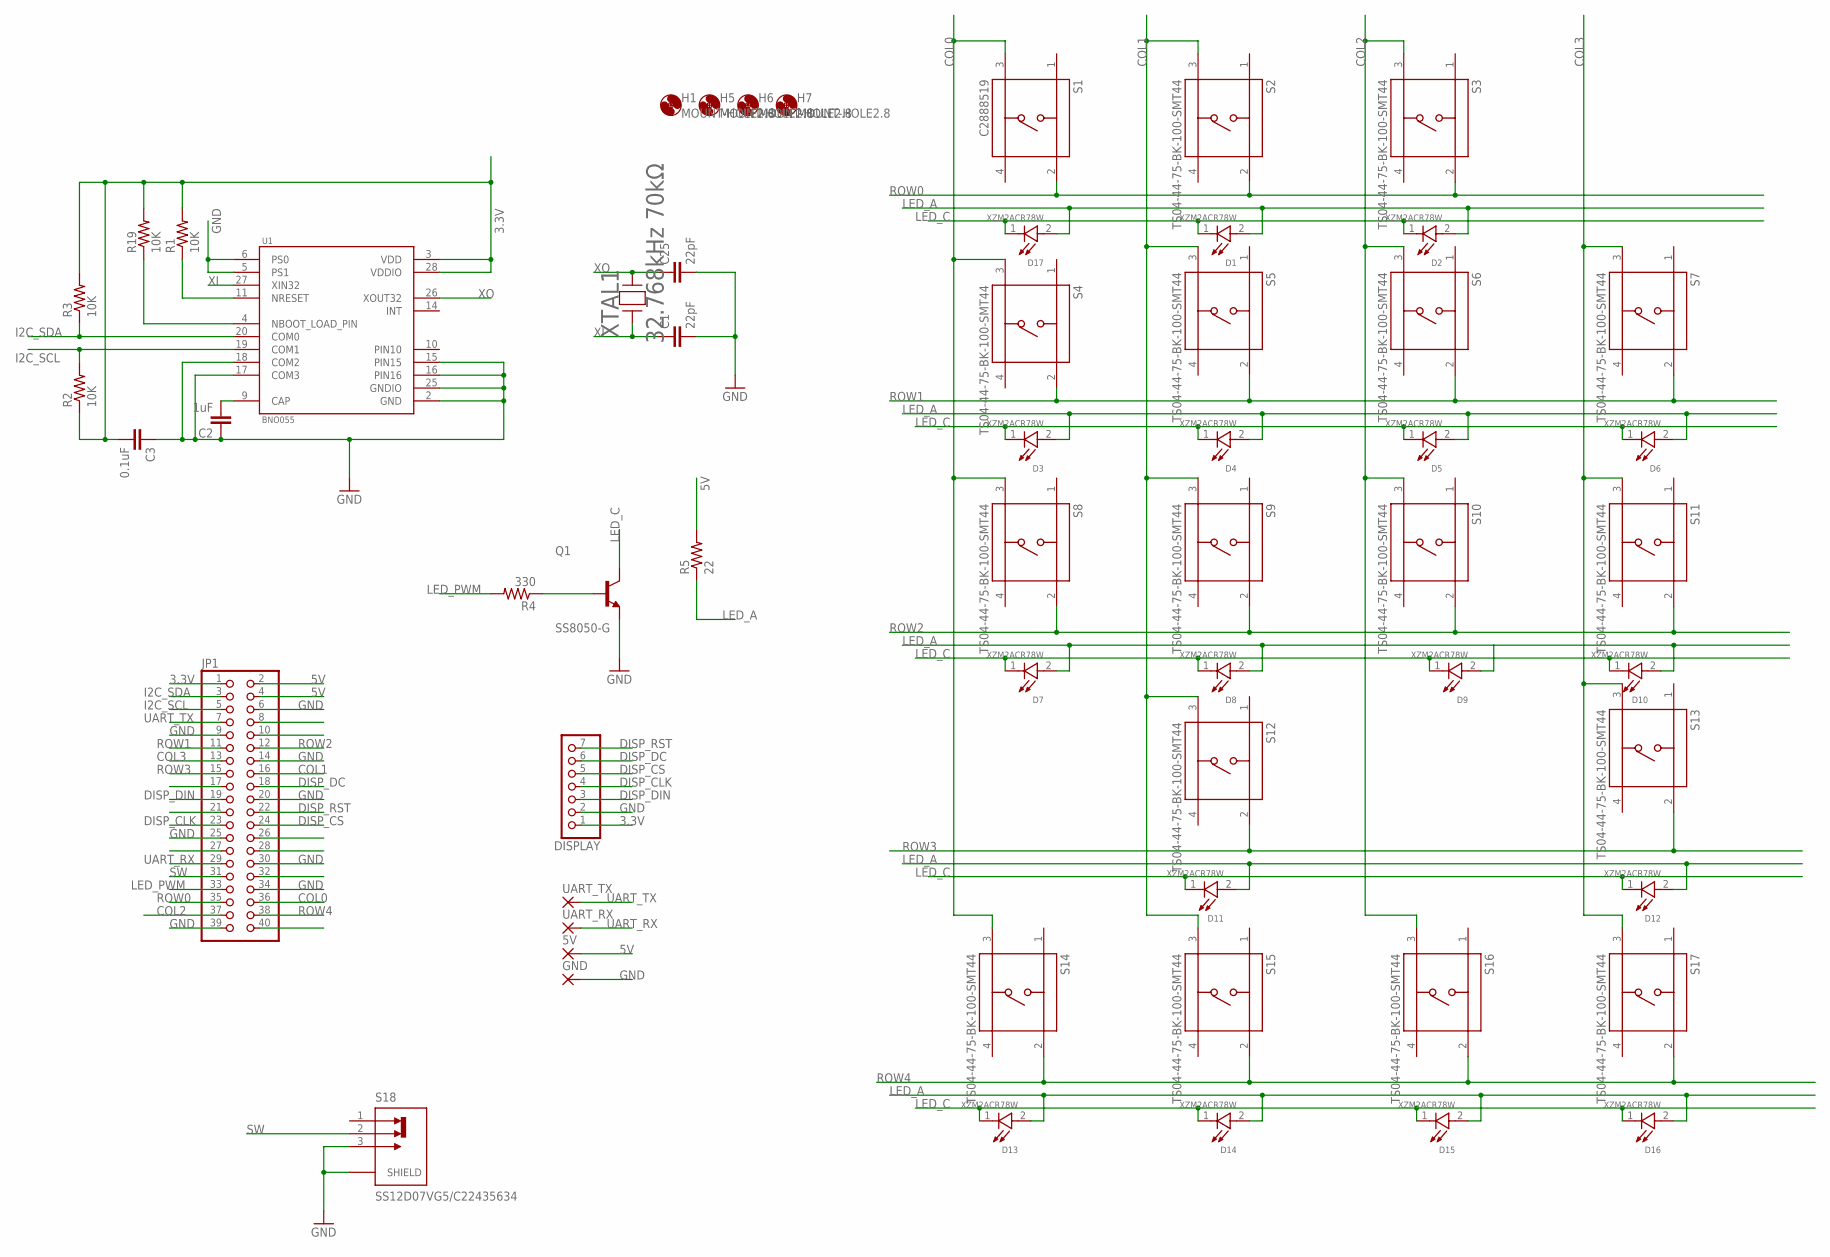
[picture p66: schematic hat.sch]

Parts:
5V: SMD2; SMD1,27-2,54
C1, C25: 22pF; CAP_0603
C2: 1uF; CAP_0603
C3: 0.1uF; CAP_0603
D1, D2, D3, D4, D5, D6, D7, D8, D9, D10, D11, D12, D13, D14, D15, D16, D17: XZM2ACR78W; LED_XZM2ACR78W
DISPLAY: PINHD-1X7; 1X07
GND: SMD2; SMD1,27-2,54
H1, H5, H6, H7: MOUNT-HOLE2.8; 2,8
JP1: PINHD-2X20; 2X20
Q1: SS8050-G; TRANS_SS8050-G
R1, R2, R3, R19: 10K; RES_0603
R4: 330; RES_0603
R5: 22; RES_0603
S1: C2888519; SW_TS04-44
S2, S3, S4, S5, S6, S7, S8, S9, S10, S11, S12, S13, S14, S15, S16, S17: TS04-44-75-BK-100-SMT44; SW_TS04-44
S18: SS12D07VG5/C22435634; SW_SS12D07VG4
U1: BNO055; LGA28R50P4X10_380X520X100
UART_RX: SMD2; SMD1,27-2,54
UART_TX: SMD2; SMD1,27-2,54
XTAL1: 32.768kHz 70kΩ; XTAL_FC-135_EPS

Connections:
3.3V: C3.2, DISPLAY.1, JP1.1, R1.2, R2.1, R3.2, R19.2, U1.3 (VDD), U1.28 (VDDIO)
5V: 5V.1, JP1.2, JP1.4, R5.2
COL0: JP1.36, S1.3 (2), S4.3 (2), S8.3 (2), S14.3 (2)
COL1: JP1.16, S2.3 (2), S5.3 (2), S9.3 (2), S12.3 (2), S15.3 (2)
COL2: JP1.37, S3.3 (2), S6.3 (2), S10.3 (2), S16.3 (2)
COL3: JP1.13, S7.3 (2), S11.3 (2), S13.3 (2), S17.3 (2)
DISP_CLK: DISPLAY.4, JP1.23
DISP_CS: DISPLAY.5, JP1.24
DISP_DC: DISPLAY.6, JP1.18
DISP_DIN: DISPLAY.3, JP1.19
DISP_RST: DISPLAY.7, JP1.22
GND: C1.2, C2.1, C3.1, C25.2, DISPLAY.2, GND.1, JP1.6, JP1.9, JP1.14, JP1.20, JP1.25, JP1.30, JP1.34, JP1.39, Q1.2 (E), S18.3, S18.S1 (SHIELD), S18.S2 (SHIELD), U1.2 (GND), U1.5 (PS1), U1.6 (PS0), U1.15 (PIN15), U1.16 (PIN16), U1.17 (COM3), U1.18 (COM2), U1.25 (GNDIO)
I2C_SCL: JP1.5, R2.2, U1.19 (COM1)
I2C_SDA: JP1.3, R3.1, U1.20 (COM0)
LED_A: D1.2 (A), D2.2 (A), D3.2 (A), D4.2 (A), D5.2 (A), D6.2 (A), D7.2 (A), D8.2 (A), D9.2 (A), D10.2 (A), D11.2 (A), D12.2 (A), D13.2 (A), D14.2 (A), D15.2 (A), D16.2 (A), D17.2 (A), R5.1
LED_C: D1.1 (C), D2.1 (C), D3.1 (C), D4.1 (C), D5.1 (C), D6.1 (C), D7.1 (C), D8.1 (C), D9.1 (C), D10.1 (C), D11.1 (C), D12.1 (C), D13.1 (C), D14.1 (C), D15.1 (C), D16.1 (C), D17.1 (C), Q1.3 (C)
LED_PWM: JP1.33, R4.2
unnamed: R1.1, U1.11 (NRESET)
unnamed: R19.1, U1.4 (NBOOT_LOAD_PIN)
unnamed: C2.2, U1.9 (CAP)
unnamed: Q1.1 (B), R4.1
PIN10: U1.10 (PIN10)
ROW0: JP1.35, S1.2 (3), S2.2 (3), S3.2 (3)
ROW1: JP1.11, S4.2 (3), S5.2 (3), S6.2 (3), S7.2 (3)
ROW2: JP1.12, S8.2 (3), S9.2 (3), S10.2 (3), S11.2 (3)
ROW3: JP1.15, S12.2 (3), S13.2 (3)
ROW4: JP1.38, S14.2 (3), S15.2 (3), S16.2 (3), S17.2 (3)
SW: JP1.31, S18.2
UART_RX: JP1.29, UART_RX.1
UART_TX: JP1.7, UART_TX.1
XI: C1.1, U1.27 (XIN32), XTAL1.1
XO: C25.1, U1.26 (XOUT32), XTAL1.2

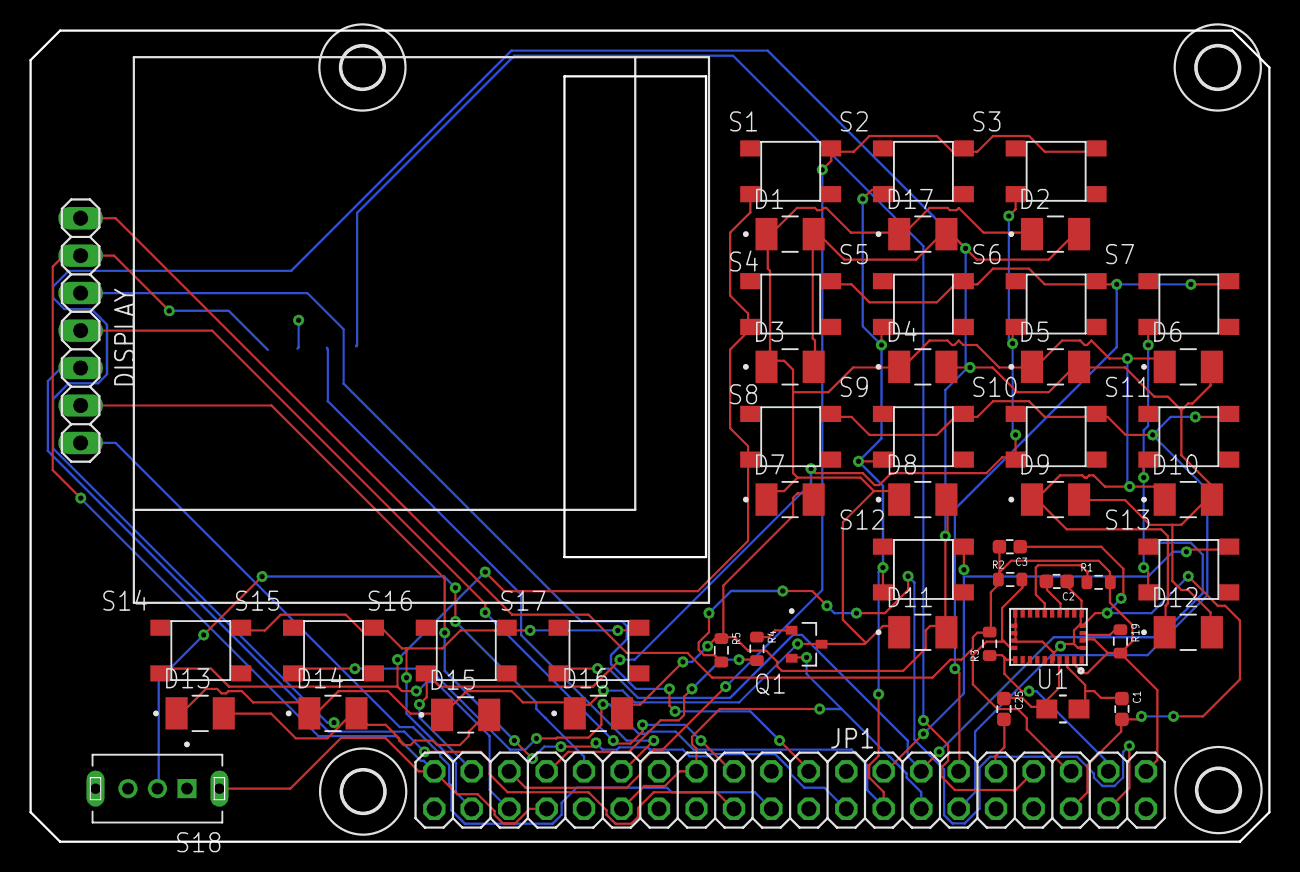
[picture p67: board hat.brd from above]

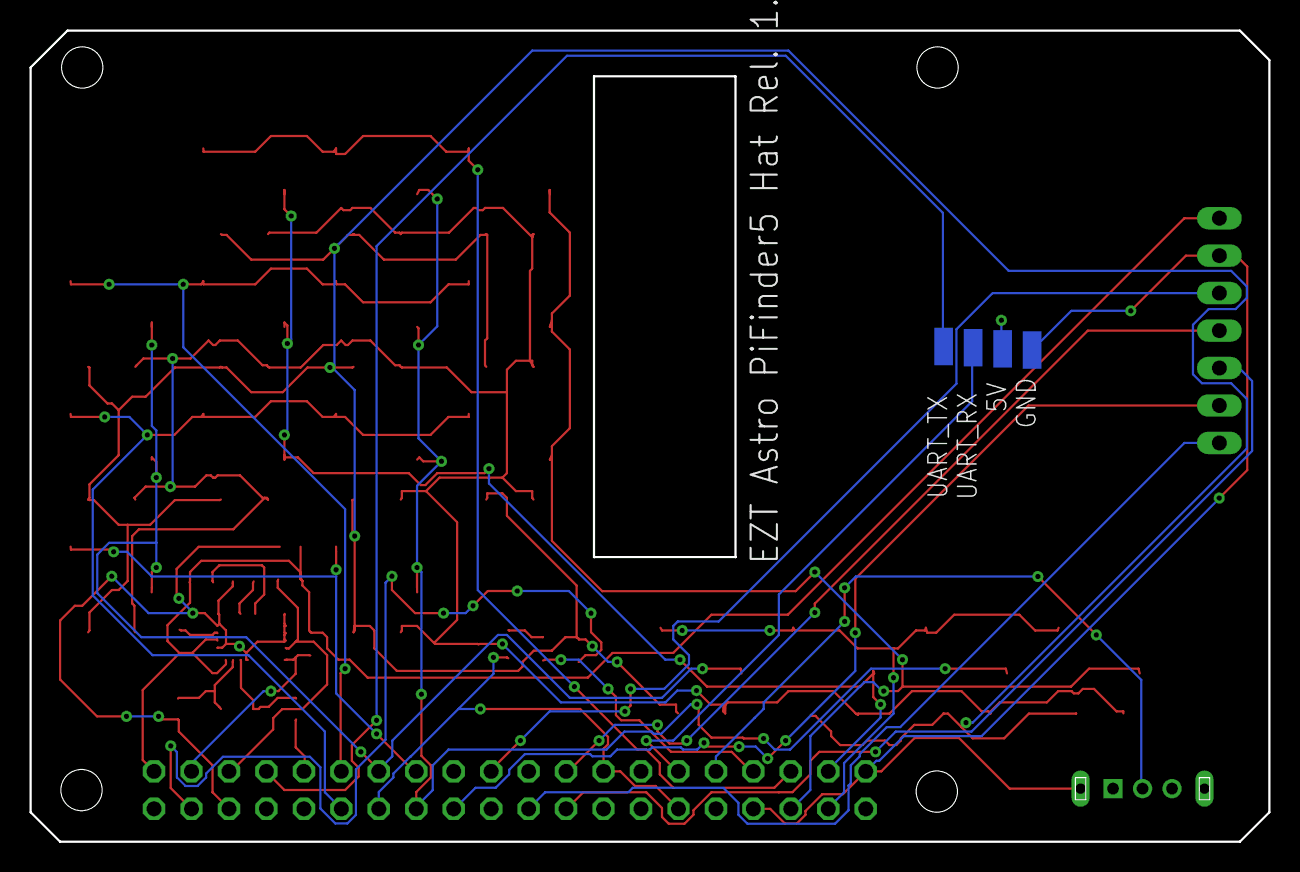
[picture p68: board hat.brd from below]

Board: 4 copper layers, 84.0 x 55.0 mm, 58 parts (4 on the bottom side), 31 nets.

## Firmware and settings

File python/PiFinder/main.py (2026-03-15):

#!/usr/bin/python
# -*- coding:utf-8 -*-
"""
This module is the main entry point for PiFinder it:
* Initializes the display
* Spawns keyboard process
* Sets up time/location via GPS
* Spawns camers/solver process
* then runs the UI loop

"""

import gettext

import os

# skyfield performance fix, see: https://rhodesmill.org/skyfield/accuracy-efficiency.html
os.environ["OPENBLAS_NUM_THREADS"] = "1"
os.environ["MKL_NUM_THREADS"] = "1"
import time
import queue
import datetime
import json
import uuid
import logging
import argparse
import pickle
from pathlib import Path
from PIL import Image, ImageOps
from multiprocessing import Process, Queue
from multiprocessing.managers import BaseManager
import RPi.GPIO as GPIO

import PiFinder.i18n  # noqa: F401
from PiFinder import solver
from PiFinder import integrator
from PiFinder import config
from PiFinder import pos_server
from PiFinder import utils
from PiFinder import server
from PiFinder import keyboard_interface
from PiFinder import mountcontrol_indi

from PiFinder.multiproclogging import MultiprocLogging
from PiFinder.catalogs import CatalogBuilder, CatalogFilter, Catalogs
from PiFinder.calc_utils import sf_utils

from PiFinder.ui.console import UIConsole
from PiFinder.ui.menu_manager import MenuManager

from PiFinder.state import SharedStateObj, UIState

from PiFinder.image_util import subtract_background

from PiFinder.displays import DisplayBase, get_display

from typing import Any, TYPE_CHECKING

# Mypy i8n fix
if TYPE_CHECKING:

    def _(a) -> Any:
        return a

logger = logging.getLogger("main")

hardware_platform = "Pi"
display_hardware = "SSD1351"
display_device: DisplayBase = DisplayBase()
keypad_pwm = None
previous_display_brightness = 0
cfg = config.Config()


# On/Off Switch GPIO
on_off_swtich = 6

# On/Off switch interrupt setup
def init_on_off_switch():
    try:
        GPIO.setmode(GPIO.BCM)
        GPIO.setup(on_off_swtich, GPIO.IN, pull_up_down=GPIO.PUD_UP) # Example with pull-up
        GPIO.add_event_detect(on_off_swtich, GPIO.BOTH, callback=on_off_callback, bouncetime=200)
        logger.info("Started : On/Off Switch monitor..")
    except KeyboardInterrupt:
        logger.error("Failed : On/Off Switch monitor..")

# On/Off switch callback
def on_off_callback(channel):
    if GPIO.input(channel) == GPIO.HIGH:
        logger.info(f"Rising edge detected on GPIO {channel}")
        on_light()
    else:
        logger.info(f"Falling edge detected on GPIO {channel}")
        off_light()

# Turn on the keyboard and dispaly to the orignal brightness
def on_light() :
    global previous_display_brightness, cfg
    set_brightness(previous_display_brightness, cfg)

# Turn off the keyboard and display
def off_light() :
    global keypad_pwm
    global display_device

    if keypad_pwm:
        keypad_pwm.change_duty_cycle(0)
    
    display_device.set_brightness(0)


def init_keypad_pwm():
    # TODO: Keypad pwm class that can be faked maybe?
    global keypad_pwm
    global hardware_platform
    if hardware_platform == "Pi":
        keypad_pwm = HardwarePWM(pwm_channel=1, hz=120)
        keypad_pwm.start(0)


def set_keypad_brightness(percentage: float):
    """
    keypad brightness between 0-100, although effective range seems 0-12
    """
    global keypad_pwm
    if percentage < 0 or percentage > 100:
        logger.error("Invalid percentage for keypad brightness")
        percentage = max(0, min(100, percentage))
    if keypad_pwm:
        keypad_pwm.change_duty_cycle(percentage)


def set_brightness(level, cfg):
    """
    Sets oled/keypad brightness
    0-255
    """
    if GPIO.input(on_off_swtich) == GPIO.HIGH :
        global previous_display_brightness
        global display_device
        display_device.set_brightness(level)
        previous_display_brightness = level

        if keypad_pwm:
            # determine offset for keypad
            keypad_offsets = {
                "+3": 2,
                "+2": 1.6,
                "+1": 1.3,
                "0": 1,
                "-1": 0.75,
                "-2": 0.5,
                "-3": 0.25,
                "-4": 0.13,
                "Off": 0,
            }
            keypad_brightness = cfg.get_option("keypad_brightness")
            set_keypad_brightness(level * 0.05 * keypad_offsets[keypad_brightness])


def setup_dirs():
    utils.create_path(Path(utils.data_dir))
    utils.create_path(Path(utils.data_dir, "captures"))
    utils.create_path(Path(utils.data_dir, "obslists"))
    utils.create_path(Path(utils.data_dir, "screenshots"))
    utils.create_path(Path(utils.data_dir, "solver_debug_dumps"))
    utils.create_path(Path(utils.data_dir, "logs"))
    os.chmod(Path(utils.data_dir), 0o777)


class StateManager(BaseManager):
    pass


StateManager.register("SharedState", SharedStateObj)
StateManager.register("UIState", UIState)
StateManager.register("NewImage", Image.new)


class PowerManager:
    def __init__(self, cfg, shared_state, display_device):
        self.cfg = cfg
        self.shared_state = shared_state
        self.display_device = display_device
        self.last_activity = time.time()

    def register_activity(self):
        """
        Resets idle counter, wakes up systems if needed
        returns True if activity caused wakeup
        """
        self.last_activity = time.time()

        # power states
        # 0 = Sleep
        # 1 = Wake
        if self.shared_state.power_state() < 1:
            # wake up
            self.wake_up()
            return True

        return False

    def wake_up(self):
        """
        Do all the wakeup things
        """
        self.last_activity = time.time()
        self.shared_state.set_power_state(1)
        self.wake_screen()

    def go_to_sleep(self):
        """
        Do all the sleep things
        """
        self.shared_state.set_power_state(0)
        self.sleep_screen()

    def update(self):
        """
        Check IMU for activity
        go to sleep if needed
        if asleep, Introduce wait state
        """
        if self.get_sleep_timeout() <= 0:
            # Disabled
            self.register_activity()
            return

        if self.shared_state.power_state() > 0:
            # We are awake, should we sleep?
            if time.time() - self.last_activity > self.get_sleep_timeout():
                self.go_to_sleep()

        else:  # We are asleepd, should we wake up?
            _imu = self.shared_state.imu()
            if _imu:
                if _imu["moving"]:
                    self.wake_up()

        # should we pause execution for a bit?
        if self.shared_state.power_state() < 1:
            time.sleep(0.2)

    def get_sleep_timeout(self):
        """
        returns the sleep timeout amount
        """
        sleep_timeout_option = self.cfg.get_option("sleep_timeout")
        sleep_timeout = {
            "Off": -1,
            "10s": 10,
            "20s": 20,
            "30s": 30,
            "1m": 60,
            "2m": 120,
        }[sleep_timeout_option]
        return sleep_timeout

    def get_screen_off_timeout(self):
        """
        returns the screen off timeout amount
        """
        screen_off_option = self.cfg.get_option("screen_off_timeout")
        screen_off = {
            "Off": -1,
            "30s": 30,
            "1m": 60,
            "10m": 600,
            "30m": 1800,
        }[screen_off_option]
        return screen_off

    def wake_screen(self) -> None:
        if GPIO.input(on_off_swtich) == GPIO.HIGH :
            screen_brightness = self.cfg.get_option("display_brightness")
            set_brightness(screen_brightness, self.cfg)
            self.display_device.device.show()

    def sleep_screen(self):
        if GPIO.input(on_off_swtich) == GPIO.HIGH :
            screen_brightness = self.cfg.get_option("display_brightness")
            set_brightness(int(screen_brightness / 4), self.cfg)
            self.display_device.device.show()

def main(
    log_helper: MultiprocLogging,
    script_name=None,
    show_fps=False,
    verbose=False,
    profile_startup=False,
) -> None:
    """
    Get this show on the road!
    """
    global display_device, display_hardware, cfg

    display_device = get_display(display_hardware)
    init_keypad_pwm()
    setup_dirs()

    # Instantiate base keyboard class for keycode
    keyboard_base = keyboard_interface.KeyboardInterface()

    # init queues
    console_queue: Queue = Queue()
    keyboard_queue: Queue = Queue()
    gps_queue: Queue = Queue()
    camera_command_queue: Queue = Queue()
    solver_queue: Queue = Queue()
    alignment_command_queue: Queue = Queue()
    alignment_response_queue: Queue = Queue()
    ui_queue: Queue = Queue()
    mountcontrol_queue: Queue = Queue()

    # init queues for logging
    keyboard_logqueue: Queue = log_helper.get_queue()
    gps_logqueue: Queue = log_helper.get_queue()
    camera_logqueue: Queue = log_helper.get_queue()
    solver_logqueue: Queue = log_helper.get_queue()
    server_logqueue: Queue = log_helper.get_queue()
    posserver_logqueue: Queue = log_helper.get_queue()
    integrator_logqueque: Queue = log_helper.get_queue()
    imu_logqueue: Queue = log_helper.get_queue()
    mountcontrol_logqueue: Queue = log_helper.get_queue()

    # Start log consolidation process first.
    log_helper.start()

    os_detail, platform, arch = utils.get_os_info()
    logger.info("PiFinder running on %s, %s, %s", os_detail, platform, arch)

    # init UI Modes
    command_queues = {
        "camera": camera_command_queue,
        "console": console_queue,
        "ui_queue": ui_queue,
        "align_command": alignment_command_queue,
        "align_response": alignment_response_queue,
        "gps": gps_queue,
        "mountcontrol": mountcontrol_queue,
    }

    init_on_off_switch()

    # init screen
    screen_brightness = cfg.get_option("display_brightness")
    set_brightness(screen_brightness, cfg)
    if cfg.get_option("screen_direction") == "as_bloom":
        display_device.device.rotate = 3


    # Set user interface language
    lang = cfg.get_option("language", "en")
    langXX = gettext.translation(
        "messages", "locale", languages=[lang], fallback=(lang == "en")
    )
    langXX.install()

    import PiFinder.manager_patch as patch

    patch.apply()

    with StateManager() as manager:
        shared_state = manager.SharedState()  # type: ignore[attr-defined]
        location = shared_state.location()
        ui_state = manager.UIState()  # type: ignore[attr-defined]
        ui_state.set_show_fps(show_fps)
        ui_state.set_hint_timeout(cfg.get_option("hint_timeout"))
        shared_state.set_ui_state(ui_state)
        shared_state.set_arch(arch)  # Normal
        logger.debug("Ui state in main is" + str(shared_state.ui_state()))
        console = UIConsole(
            display_device, None, shared_state, command_queues, cfg, Catalogs([])
        )
        console.write("Starting....")
        console.update()
        logger.info("Starting ....")

        # spawn gps service....
        console.write("   GPS")
        console.update()
        logger.info("   GPS")
        gps_process = Process(
            name="GPS",
            target=gps_monitor.gps_monitor,
            args=(
                gps_queue,
                console_queue,
                gps_logqueue,
            ),
        )
        gps_process.start()
        console.set_shared_state(shared_state)

        # spawn keyboard service....
        console.write("   Keyboard")
        logger.info("   Keyboard")
        console.update()
        if cfg.get_option("screen_direction") == "as_bloom":
            bloom_key_remap = True
        else:
            bloom_key_remap = False
        keyboard_process = Process(
            name="Keyboard",
            target=keyboard.run_keyboard,
            args=(keyboard_queue, shared_state, keyboard_logqueue, bloom_key_remap),
        )
        keyboard_process.start()
        if script_name:
            script_path = f"../scripts/{script_name}.pfs"
            p = Process(
                name="Script",
                target=keyboard_interface.KeyboardInterface.run_script,
                args=(script_path, keyboard_queue, keyboard_logqueue),
            )
            p.start()

        # Web server
        console.write(_("   Webserver"))
        logger.info(_("   Webserver"))
        console.update()

        server_process = Process(
            name="Webserver",
            target=server.run_server,
            args=(
                keyboard_queue,
                ui_queue,
                gps_queue,
                shared_state,
                server_logqueue,
                verbose,
            ),
        )
        server_process.start()

        console.write(_("   Camera"))
        logger.info(_("   Camera"))
        console.update()
        camera_image = manager.NewImage("RGB", (512, 512))  # type: ignore[attr-defined]
        image_process = Process(
            name="Camera",
            target=camera.get_images,
            args=(
                shared_state,
                camera_image,
                camera_command_queue,
                console_queue,
                camera_logqueue,
            ),
        )
        image_process.start()
        time.sleep(1)

        # IMU
        console.write(_("   IMU"))
        logger.info(_("   IMU"))
        console.update()
        imu_process = Process(
            name="IMU",
            target=imu.imu_monitor,
            args=(shared_state, console_queue, imu_logqueue),
        )
        imu_process.start()

        # Solver
        console.write(_("   Solver"))
        logger.info(_("   Solver"))
        console.update()
        solver_process = Process(
            name="Solver",
            target=solver.solver,
            args=(
                shared_state,
                solver_queue,
                camera_image,
                console_queue,
                solver_logqueue,
                alignment_command_queue,
                alignment_response_queue,
                verbose,
            ),
        )
        solver_process.start()

        # Integrator
        console.write("   Integrator")
        logger.info("   Integrator")
        console.update()
        integrator_process = Process(
            name="Integrator",
            target=integrator.integrator,
            args=(
                shared_state,
                solver_queue,
                console_queue,
                integrator_logqueque,
                verbose,
            ),
        )
        integrator_process.start()

        # Server
        console.write("  POS Server")
        logger.info("  POS Server")
        console.update()
        posserver_process = Process(
            name="SkySafariServer",
            target=pos_server.run_server,
            args=(shared_state, ui_queue, posserver_logqueue),
        )
        posserver_process.start()

        # Mount Control
        sys_utils = utils.get_sys_utils()
        if sys_utils.is_mountcontrol_active():
            console.write(_("  Mount Control"))
            logger.info(_("  Mount Control"))
            console.update()
            mountcontrol_process = Process(
                name="MountControl",
                target=mountcontrol_indi.run,
                args=(
                    mountcontrol_queue,
                    console_queue,
                    shared_state,
                    mountcontrol_logqueue,
                    "localhost",
                    7624,
                ),
            )
            mountcontrol_process.start()

        # Initialize Catalogs
        console.write(_("   Catalogs"))
        logger.info(_("   Catalogs"))
        console.update()

        # Initialize Catalogs
        catalogs: Catalogs = CatalogBuilder().build(shared_state)

        # Establish the common catalog filter object
        _new_filter = CatalogFilter(shared_state=shared_state)
        _new_filter.load_from_config(cfg)
        catalogs.set_catalog_filter(_new_filter)
        console.write(_("   Menus"))
        console.update()

        # Initialize menu manager
        menu_manager = MenuManager(
            display_device,
            camera_image,
            shared_state,
            command_queues,
            cfg,
            catalogs,
        )

        # Initialize power manager
        power_manager = PowerManager(cfg, shared_state, display_device)

        #On/Off switch
        if GPIO.input(on_off_swtich) == GPIO.LOW :
            logger.info("Off Display")
            off_light()
        else :
            logger.info("On Display")


        # Start main event loop
        console.write("   Event Loop")
        logger.info("   Event Loop")
        console.update()

        log_time = True
        # Start of main except handler / loop
        try:
            while True:
                # Console
                try:
                    console_msg = console_queue.get(block=False)
                    if isinstance(console_msg, list):
                        for item in console_msg:
                            if item.startswith("DEGRADED_OPS"):
                                menu_manager.message(_("Degraded\nCheck Status"), 5)
                                time.sleep(5)
                            else:
                                console.write(item)
                    else:
                        if console_msg.startswith("DEGRADED_OPS"):
                            menu_manager.message(_("Degraded\nCheck Status"), 5)
                            time.sleep(5)
                        else:
                            console.write(console_msg)

                except queue.Empty:
                    time.sleep(0.1)

                # GPS
                try:
                    while True:  # Consume from gps_queue until empty
                        gps_msg, gps_content = gps_queue.get(block=False)
                        if gps_msg == "fix":
                            if gps_content["lat"] + gps_content["lon"] != 0:
                                location = shared_state.location()

                            # Only update GPS fixes, as soon as it's loaded or comes from the WEB it's untouchable
                            if (
                                not location.source == "WEB"
                                and not location.source.startswith("CONFIG:")
                                and (
                                    location.error_in_m == 0
                                    or float(gps_content["error_in_m"])
                                    < float(
                                        location.error_in_m
                                    )  # Only if new error is smaller
                                )
                            ):
                                logger.info(
                                    f"Updating GPS location: new content: {gps_content}, old content: {location}"
                                )
                                location.lat = gps_content["lat"]
                                location.lon = gps_content["lon"]
                                location.altitude = gps_content["altitude"]
                                location.source = gps_content["source"]
                                if "error_in_m" in gps_content:
                                    location.error_in_m = gps_content["error_in_m"]
                                if "lock" in gps_content:
                                    location.lock = gps_content["lock"]
                                if "lock_type" in gps_content:
                                    location.lock_type = gps_content["lock_type"]

                                    dt = shared_state.datetime()
                                    if dt is None:
                                        location.last_gps_lock = "--"
                                    else:
                                        location.last_gps_lock = dt.time().isoformat()[
                                            :8
                                        ]
                                    console.write(
                                        f"GPS: Location {location.lat} {location.lon} {location.altitude} {location.error_in_m}"
                                    )
                                    shared_state.set_location(location)
                                    sf_utils.set_location(
                                        location.lat,
                                        location.lon,
                                        location.altitude,
                                    )
                        if gps_msg == "time":
                            if isinstance(gps_content, datetime.datetime):
                                gps_dt = gps_content
                            else:
                                gps_dt = gps_content["time"]
                            shared_state.set_datetime(gps_dt)
                            if log_time:
                                logger.info("GPS Time (logged only once): %s", gps_dt)
                                log_time = False
                        if gps_msg == "reset":
                            location.reset()
                            shared_state.set_location(location)
                        if gps_msg == "satellites":
                            # logger.debug("Main: GPS nr sats seen: %s", gps_content)
                            shared_state.set_sats(gps_content)
                except queue.Empty:
                    pass
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

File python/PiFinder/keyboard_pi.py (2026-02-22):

#!/usr/bin/python
# -*- coding:utf-8 -*-
"""
This module is runs the keyboard matrix
and adds keys to the provided queue

"""

from time import sleep
import libinput

from PiFinder.keyboard_interface import KeyboardInterface
import RPi.GPIO as GPIO
import logging
from PiFinder.multiproclogging import MultiprocLogging

logger = logging.getLogger("Keyboard.Pi")


class KeyboardPi(KeyboardInterface):
    def __init__(self, q, bloom_remap=False):
        self.q = q

        # GPIO pin numbers for the rows and columns of the keyboard matrix
        self.cols = [16, 23, 26, 27]
        self.rows = [19, 17, 18, 22, 20]

        if bloom_remap:
            _up = self.RIGHT
            _down = self.LEFT
            _left = self.UP
            _right = self.DOWN
            _lng_up = self.LNG_RIGHT
            _lng_down = self.LNG_LEFT
            _lng_left = self.LNG_UP
            _lng_right = self.LNG_DOWN
            _alt_up = self.ALT_RIGHT
            _alt_down = self.ALT_LEFT
            _alt_left = self.ALT_UP
            _alt_right = self.ALT_DOWN
        else:
            _up = self.UP
            _down = self.DOWN
            _left = self.LEFT
            _right = self.RIGHT
            _lng_up = self.LNG_UP
            _lng_down = self.LNG_DOWN
            _lng_left = self.LNG_LEFT
            _lng_right = self.LNG_RIGHT
            _alt_up = self.ALT_UP
            _alt_down = self.ALT_DOWN
            _alt_left = self.ALT_LEFT
            _alt_right = self.ALT_RIGHT

        # fmt: off
        self.keymap = [
            7 , 8 , 9 , self.NA,
            4 , 5 , 6 , self.PLUS,
            1 , 2 , 3 , self.MINUS,
            self.NA, 0 , self.NA, self.SQUARE,
            _left, _up , _down , _right,
        ]
        # If SQUARE is pressed together with key, ALT_<key> is sent
        self.alt_keymap = [
            self.NA, self.NA, self.NA, self.NA,
            self.NA, self.NA, self.NA, self.ALT_PLUS,
            self.NA, self.NA, self.NA, self.ALT_MINUS,
            self.NA, self.ALT_0, self.NA, self.NA,
            _alt_left, _alt_up, _alt_down, _alt_right,
        ]
        self.long_keymap = [
            self.NA, self.NA, self.NA, self.NA,
            self.NA, self.NA, self.NA, self.NA,
            self.NA, self.NA, self.NA, self.NA,
            self.NA, self.NA, self.NA, self.LNG_SQUARE,
            _lng_left, _lng_up, _lng_down, _lng_right,
        ]
        # fmt: on

        # physical keyboard support init
        self.li_kb = libinput.LibInput(context_type=libinput.ContextType.UDEV)
        #self.li_kb = libinput.LibInput.udev_create_context()
        self.li_kb.assign_seat("seat0")

    def get_keyboard_key(self) -> int:
        """
        Checks libinput keyboard, if keyrelesed
        map to our keycode and return

        Returns 0 for no key registered
        """
        key_mapping: dict[int, int] = {
            103: self.UP,
            108: self.DOWN,
            105: self.LEFT,
            106: self.RIGHT,
            28: self.SQUARE,
            78: self.MINUS,
            74: self.PLUS,
        }

        while True:
            while True:
                self.li_kb._libinput.libinput_dispatch(self.li_kb._li)
                hevent = self.li_kb._libinput.libinput_get_event(self.li_kb._li)
                if not hevent:
                    return 0
                type_ = self.li_kb._libinput.libinput_event_get_type(hevent)

                if type_.is_keyboard():
                    kbev = libinput.KeyboardEvent(hevent, self.li_kb._libinput)
                    if kbev.key_state == libinput.constant.KeyState.RELEASED:
                        return key_mapping.get(kbev.key, 0)

    def run_keyboard(self, log_queue):
        """
        scans keyboard matrix, puts release events in queue
        """
        MultiprocLogging.configurer(log_queue)

        GPIO.setmode(GPIO.BCM)
        GPIO.setup(self.rows, GPIO.IN)
        GPIO.setup(self.cols, GPIO.IN, pull_up_down=GPIO.PUD_UP)
        pressed = set()
        alt_sent = False
        hold_counter = 0
        hold_sent = False
        scan_freq = 60
        while True:
            # Check physical keyboard
            if keyboard_key := self.get_keyboard_key():
                self.q.put(keyboard_key)
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

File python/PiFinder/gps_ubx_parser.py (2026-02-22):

#!/usr/bin/env python3

import sys
import json
import math
import logging
from PiFinder.multiproclogging import MultiprocLogging
import asyncio
import aiofiles
from typing import Dict, Callable, Optional, Tuple
from dataclasses import dataclass
from enum import IntEnum
import datetime

logger = logging.getLogger("GPS.parser")


class UBXClass(IntEnum):
    NAV = 0x01
    CFG = 0x06


class NAVMessageId(IntEnum):
    # U7 Messages (standard GPS as in the build guide), see https://content.u-blox.com/sites/default/files/products/documents/u-blox7-V14_ReceiverDescriptionProtocolSpec_%28GPS.G7-SW-12001%29_Public.pdf
    SOL = 0x06
    SVINFO = 0x30
    SAT = 0x35
    TIMEGPS = 0x20
    DOP = 0x04
    # For EOE, PVT and POSECEF see https://www.u-blox.com/docs/UBX-20053845 for specification of the messages
    # (search for 0x01 0xMM)
    EOE = 0x61  # End of Epoch
    PVT = 0x07  # Position Velocity Time
    POSECEF = 0x01  # Position solution in ECEF


class CFGMessageId(IntEnum):
    MSG = 0x01
    RATE = 0x08


@dataclass
class ParserConfig:
    enable: bool = True
    json: bool = False
    raw: int = 2


class UBXParser:
    def __init__(
        self,
        log_queue,
        reader: Optional[asyncio.StreamReader] = None,
        writer: Optional[asyncio.StreamWriter] = None,
        file_path: Optional[str] = None,
    ):
        if log_queue is not None:
            MultiprocLogging.configurer(log_queue)
        self.reader = reader
        self.writer = writer
        self.file_path = file_path
        self.config = ParserConfig()
        self.message_parsers: Dict[Tuple[int, int], Callable[[bytes], dict]] = {}
        self.buffer = bytearray()
        self._poll_task = None  # Store polling task for cleanup
        self._running = True  # Control flag for polling loop
        self._initialize_parsers()

    def _initialize_parsers(self):
        self._register_parser(UBXClass.NAV, NAVMessageId.SOL, self._parse_nav_sol)
        self._register_parser(UBXClass.NAV, NAVMessageId.SAT, self._parse_nav_sat)
        self._register_parser(
            UBXClass.NAV, NAVMessageId.TIMEGPS, self._parse_nav_timegps
        )
        self._register_parser(UBXClass.NAV, NAVMessageId.DOP, self._parse_nav_dop)
        self._register_parser(UBXClass.NAV, NAVMessageId.SVINFO, self._parse_nav_svinfo)
        self._register_parser(UBXClass.NAV, NAVMessageId.PVT, self._parse_nav_pvt)
        self._register_parser(
            UBXClass.NAV, NAVMessageId.POSECEF, self._parse_nav_posecef
        )
        self._register_parser(UBXClass.NAV, NAVMessageId.EOE, self._parse_nav_eoe)

    def _register_parser(
        self, msg_class: UBXClass, msg_id: int, parser: Callable[[bytes], dict]
    ):
        self.message_parsers[(msg_class, msg_id)] = parser

    def _generate_ubx_message(
        self, msg_class: int, msg_id: int, payload: bytes
    ) -> bytes:
        msg = bytes([msg_class, msg_id]) + len(payload).to_bytes(2, "little") + payload
        ck_a = ck_b = 0
        for b in msg:
            ck_a = (ck_a + b) & 0xFF
            ck_b = (ck_b + ck_a) & 0xFF
        final_msg = b"\xb5\x62" + msg + bytes([ck_a, ck_b])
        return final_msg

    async def _handle_initial_messages(self):
        if self.writer is None or self.writer.is_closing():
            logger.warning("Writer unavailable for initial messages")
            return

        watch_json = json.dumps(
            {"enable": True, "raw": 2, "json": False, "binary": True, "nmea": False},
            separators=(",", ":"),
        )
        watch_command = f"?WATCH={watch_json}\r\n"
        logger.debug(f"Sending WATCH command: {watch_command}")
        self.writer.write(watch_command.encode())
        await self.writer.drain()
        # Optional: Read response to confirm
        response = await self.reader.read(1024)
        logger.debug(f"WATCH response: {response.decode('utf-8', errors='ignore')}")

    async def _poll_messages(self):
        # while self._running and self.writer and not self.writer.is_closing():
        #     try:
        #         for msg_id in [NAVMessageId.SVINFO, NAVMessageId.TIMEGPS]:
        #             poll_msg = self._generate_ubx_message(UBXClass.NAV, msg_id, b"")
        #             prefix = bytes.fromhex("21 31 57 3d")  # !1W=
        #             suffix = bytes.fromhex("0d 0a")  # \r\n
        #             wrapped_msg = prefix + poll_msg + suffix
        #             self.writer.write(wrapped_msg)
        #             await self.writer.drain()
        #         await asyncio.sleep(1)
        #     except (ConnectionResetError, BrokenPipeError, AttributeError) as e:
        #         logger.error(f"Polling error: {e}. Stopping polling.")
        #         self._running = False
        #         break
        pass

    @classmethod
    async def connect(cls, log_queue, host="127.0.0.1", port=2947, max_attempts=5):
        attempt = 0
        while attempt < max_attempts:
            try:
                # Add delay between connection attempts
                if attempt > 0:
                    delay = min(2**attempt, 30)
                    logger.error(
                        f"Connection attempt {attempt}/{max_attempts} failed. Retrying in {delay}s..."
                    )
                    await asyncio.sleep(delay)

                reader, writer = await asyncio.open_connection(host, port)
                parser = cls(log_queue, reader=reader, writer=writer)
                await parser._handle_initial_messages()
                return parser
            except (ConnectionRefusedError, ConnectionResetError) as e:
                attempt += 1
                if attempt >= max_attempts:
                    logger.error(
                        f"Failed to connect after {max_attempts} attempts: {e}"
                    )
                    raise
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

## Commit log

2026-02-22 Initial project upload
    [90_degree_dovetail.stl, BNO055.kicad_sch, EGC.tsv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]
2026-03-15 Revise mount control
2026-08-31 Update supported mounts
    Add new models
